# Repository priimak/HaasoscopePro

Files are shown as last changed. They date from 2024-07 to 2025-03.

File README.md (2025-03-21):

## HaasoscopePro

### An Affordable 2 GHz 3.2 GS/s 12 bit open-source open-hardware expandable USB oscilloscope

### [Available on CrowdSupply](https://www.crowdsupply.com/andy-haas/haasoscope-pro)

### [Hackaday.io Page](https://hackaday.io/project/200773-haasoscope-pro)

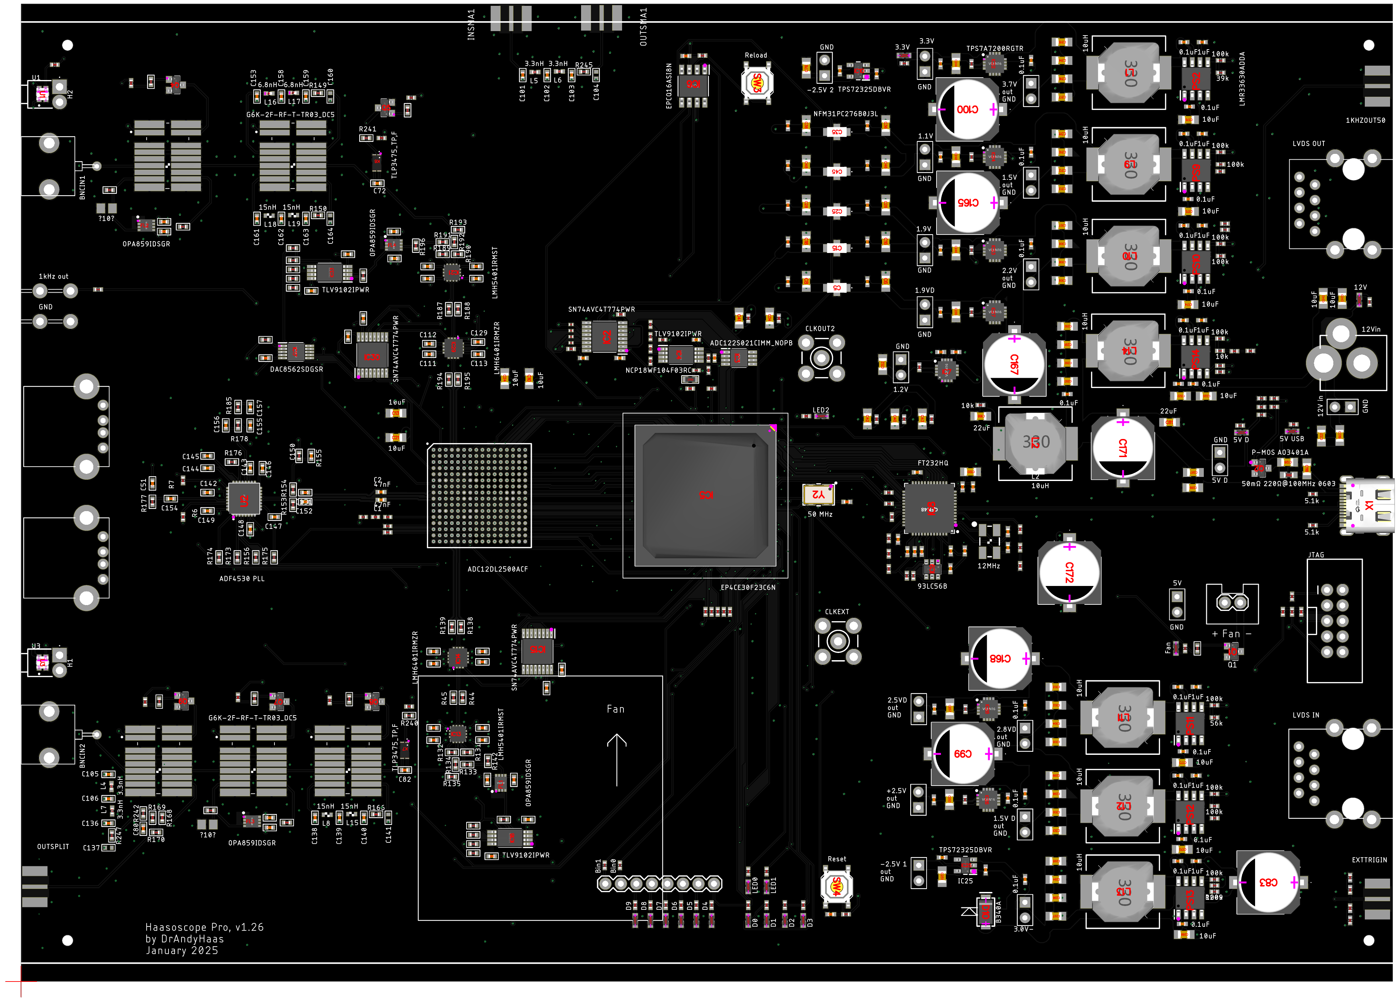
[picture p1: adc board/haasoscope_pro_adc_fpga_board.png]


#### Schematics in PDF: [haasoscope_pro_adc_fpga_board_schematics.pdf](adc%20board%2Fhaasoscope_pro_adc_fpga_board_schematics.pdf)

#### Routing image: [haasoscope_pro_adc_fpga_board_routing.png](adc%20board%2Fhaasoscope_pro_adc_fpga_board_routing.png)

#### Firmware overview: [firmware schematic.pdf](adc%20board%20firmware/schematic.pdf)

### Quick start (Windows/Mac/Linux)

1) Plug Haasoscope Pro into your computer via USB C
2) Download code and unzip it: https://github.com/drandyhaas/HaasoscopePro/archive/refs/heads/main.zip
3) Run **HaasoscopeProQt** in the <code>HaasoscopePro/software/dist/(OS)_HaasoscopeProQt</code> directory

### Tips

- If not enough power is supplied or issues happen during readout, plug in via a powered USB hub, a USB-A to C cable, or use an external 12V power adapter
- If the board is not found on Linux, use this udev rule and then plug it in: <code>sudo cp HaasoscopePro/software/ft245.rules /etc/udev/rules.d/</code>
- If you get an error like "qt.qpa.plugin: Could not load the Qt platform plugin "xcb" in "" even though it was found", try: <code>sudo apt install libxcb-xinerama0</code>

### Fuller way of running

1) Install python3 and git (operating system dependent)
2) Install dependencies: <br><code>pip3 install numpy scipy pyqtgraph PyQt5 pyftdi ftd2xx</code>
3) Get code: <br><code>git clone https://github.com/drandyhaas/HaasoscopePro.git</code>
4) Install [FTDI D2xx driver](https://ftdichip.com/drivers/d2xx-drivers/)
<br>for Windows: install using the [setup exe](https://ftdichip.com/wp-content/uploads/2021/08/CDM212364_Setup.zip)
<br>for Mac can just do: <code>sudo cp HaasoscopePro/software/libftd2xx.dylib /usr/local/lib/</code> 
<br>for Linux can just do: <code>sudo cp HaasoscopePro/software/libftd2xx.so /usr/lib/</code>
5) Run:
<br><code>cd HaasoscopePro/software</code>
<br><code>python3 HaasoscopeProQt.py</code>
6) To remake exe for quick start:
<br><code>pip3 install pyinstaller</code> # install dependency once
<br><code>python3 -m PyInstaller HaasoscopeProQt.py</code>
<br><code>mv dist/HaasoscopeProQt dist/(OS)_HaasoscopeProQt</code>

### Repository structure

- [adc board](adc%20board/): Design files and documentation for the main board, based on Eagle 9.6.2
- [adc board/Kicad](adc%20board/Kicad): An import of the main board design files into KiCad 8
- [adc board firmware](adc%20board%20firmware/): Quartus lite project for the Altera Cyclone IV FPGA firmware (see [README](adc%20board%20firmware/README.md) in there for firmware upload instructions)
- [case](case/): Front and back PCB panels for the aluminum case
- [software](software/): Python files for the oscilloscope program
- [sub boards](sub%20boards/): Eagle design files and documentation for smaller test boards that were used during development 

### 2 GHz Active Probe

All designs for the accompanying active probe are in a separate [repository](https://github.com/drandyhaas/oshw-active-probe)

### Editing the GUI

The Haasoscope Pro GUI can be edited using [Qt Designer](https://www.pythonguis.com/installation/install-qt-designer-standalone/), started with:
<br><code>pip install pyqt5-tools</code>
<br><code>pyqt5-tools designer</code>
<br>Then open software/HaasoscopePro.ui or HaasoscopeProFFT.ui etc.

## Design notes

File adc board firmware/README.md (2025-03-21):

# For compiling and uploading firmware

Install Quartus Prime Lite (free)
 - Tested on Windows, but Linux should work too
 - Tested with version 23.1, but newer should also be OK

Open the **adc_board_firmware/coincidence.qpf** project file in this directory with Quartus Prime Lite
 - File... Open Project

If you've made changes to the code, recompile
 - Processing... Start Compilation (or the "play" button in the menu bar)

To upload firmware to board:
 - Attach power to board
 - Attach USB Blaster to board via JTAG (to set up the usb blaster see tips below)
 - Tools... Programmer
   - Hardware Setup... select USB blaster by double clicking, then close
   - (If you need permanent writing to the board flash, and have recompiled, remake the jic file by doing File... Convert Programming Files, then Open Conversion Setup Data..., select **adc_board_firmware/coincidence.cof**, then Generate button at bottom)
   - Add File... **adc_board_firmware/output_files/coincidence.sof** (for temporary testing) or **adc_board_firmware/output_files/coincidence.jic** (for permanent writing to the board flash memory)
   - Select checkbox Program/Configure
   - Start

To setup USB Blaster on Windows:
 - After plugging in the USB Blaster, it may appear as an unrecognized device in the device manager. If so, you need to install a driver for it. Drivers come with the Quartus installation (even the "programmer only" version). Follow these instructions to install the driver:<br>
Plug in the USB blaster device, go to it in the device manager, and do Update driver, then Browse my computer for drivers, Let me pick from a list of devices, select JTAG cables, Have disk, and select the intelFPGA_lite\<version>\quartus\drivers\usb-blaster-ii directory, and install.

To setup USB Blaster on Linux:
 - In theory it should work out of the box, but you just need permissions to access it. Try this and then plug it in: <code>sudo cp HaasoscopePro/software/blaster.rules /etc/udev/rules.d/</code>

Tips in case of problems:
 - Maybe the USB-blaster must first be powered from the board and then connected to the PC. So the procedure step by step: connect the USB-Blaster to your board, power-on the board, plug the USB cable in the PC.

Screenshots for temporary (sof) or permanent flash (jic) programming:





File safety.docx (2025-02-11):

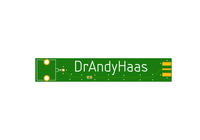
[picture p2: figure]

Regulatory Compliance and Safety Information

Haasoscope Pro and Haasoscope Pro-be

IMPORTANT: PLEASE RETAIN THIS INFORMATION FOR FUTURE REFERENCE

Getting Started

For full set up and installation instructions please visit: github.com/drandyhaas/HaasoscopePro

Wanings

- This product shall only be connected to an external power supply rated at 5V DC for the USB-C connection and a minimum current of 2A, and/or 12V DC for the barrel jack connection and a minimum current of 1A. Any external power supply used with the Haasoscope PRo shall comply with relevant regulations and standards applicable in the country of intended use.
- This product should be operated in a well ventilated environment and the case should not be covered.
- This product should be placed on a stable, flat, non-conductive surface in use and should not be contacted by conductive items.
- The connection of unapproved devices to the connectors may affect compliance or result in damage to the unit.
- All peripherals used with the unit should comply with relevant standards for the country of use and be marked accordingly to ensure that safety and performance requirements are met. These articles include but are not limited to probes, cables, and adapters.
- Where peripherals are connected that do not include the cable or connector, the cable or connector used must offer adequate insulation and operation in order that the requirements of the relevant performance and safety requirements are met.

Institutions for safe use

To avoid malfunction or damage to your Haasoscope Pro please observe the following:

- Do not expose it to water, moisture or place it on a conductive surface whilst in operation.
- Do not expose it to heat from any source; the Haasoscope Pro is designed for reliable operation at normal ambient room temperatures.
- Take care whilst handling to avoid mechanical or electrical damage to the printed circuit board and connectors.
- Avoid handling the printed circuit board while it is powered. Only handle it by the edges to minimise the risk of electrostatic discharge damage.

Compliance information

The Haasoscope Pro complies with the relevant provisions of the RoHS Directive for the European Union. In

common with all Electrical and Electronic Equipment (EEE) the Haasoscope Pro should not be disposed of as

household waste. Alternative arrangements may apply in other jurisdictions.

Electromagnetic compatibility and operation:

- This product is in conformity with the protection requirements of EU Council Directive 2004/108/EC on the approximation of the laws of the Member States relating to electromagnetic compatibility.
- This product has been tested and found to comply with the limits for Class B Information Technology Equipment according to the European Standard.
- NOTE: This equipment has been tested and found to comply with the limits for a Class B digital device, pursuant to part 15 of the FCC Rules. These limits are designed to provide reasonable protection against harmful interference in a residential installation. This equipment generates, uses and can radiate radio frequency energy and, if not installed and used in accordance with the instructions, may cause harmful interference to radio communications. However, there is no guarantee that interference will not occur in a particular installation. If this equipment does cause harmful interference to radio or television reception, which can be determined by turning the equipment off and on, the user is encouraged to try to correct the interference by one or more of the following measures:

❍ Reorient or relocate the receiving antenna

❍ Increase the separation between the equipment and receiver

❍ Connect the equipment into an outlet on a circuit different from that to which the receiver is connected

❍ Consult the dealer or an experienced radio/TV technician for help

- This Class B digital apparatus complies with CAN ICES-3 (B). Cet appareil numérique de la classe B est conforme à la norme NMB-3 (B) du Canada.
- WARNING: Please do not alter or modify the design of this product, doing so may void your ability to use the product freely, this includes altering the frequency at which the product operates.

DrAndyHaas Electronics

215 Lane Gate Rd

Cold Spring, NY 10516

USA

DrAndyHaas.com

Informationen zur Einhaltung gesetzlicher Vorschriften und zur Sicherheit

Haasoskop Pro und Haasoskop Pro-be

WICHTIG: BITTE BEWAHREN SIE DIESE INFORMATIONEN ZUM SPÄTEREN NACHSCHLAGEN AUF

Erste Schritte

Die vollständigen Einrichtungs- und Installationsanweisungen finden Sie unter: github.com/drandyhaas/HaasoscopePro

Abnehmen

- Dieses Produkt darf nur an eine externe Stromversorgung mit 5 V DC für den USB-C-Anschluss und einem Mindeststrom von 2 A und/oder 12 V DC für den Hohlsteckeranschluss und einem Mindeststrom von 1 A angeschlossen werden. Alle mit dem Haasoscope PRo verwendeten externen Netzteile müssen den einschlägigen Vorschriften und Normen entsprechen, die im Land der beabsichtigten Verwendung gelten.
- Dieses Produkt sollte in einer gut belüfteten Umgebung betrieben werden und das Gehäuse sollte nicht abgedeckt werden.
- Dieses Produkt sollte während des Gebrauchs auf einer stabilen, flachen, nicht leitenden Oberfläche platziert werden und nicht mit leitenden Gegenständen in Berührung kommen.
- Der Anschluss nicht zugelassener Geräte an die Anschlüsse kann die Konformität beeinträchtigen oder zu Schäden am Gerät führen.
- Alle mit dem Gerät verwendeten Peripheriegeräte sollten den relevanten Standards des jeweiligen Landes entsprechen und entsprechend gekennzeichnet sein, um sicherzustellen, dass die Sicherheits- und Leistungsanforderungen erfüllt werden. Zu diesen Artikeln gehören unter anderem Sonden, Kabel und Adapter.
- Wenn Peripheriegeräte angeschlossen werden, die kein Kabel oder Stecker enthalten, muss das verwendete Kabel oder der Stecker eine ausreichende Isolierung und Funktion bieten, damit die Anforderungen der relevanten Leistungs- und Sicherheitsanforderungen erfüllt werden.

Institutionen zur sicheren Nutzung

Um Fehlfunktionen oder Schäden an Ihrem Haasoscope Pro zu vermeiden, beachten Sie bitte Folgendes:

- Setzen Sie es während des Betriebs weder Wasser noch Feuchtigkeit aus und stellen Sie es nicht auf eine leitfähige Oberfläche.
- Setzen Sie es keiner Hitzequelle aus; Das Haasoscope Pro ist für einen zuverlässigen Betrieb bei normalen Raumtemperaturen ausgelegt.
- Seien Sie bei der Handhabung vorsichtig, um mechanische oder elektrische Schäden an der Leiterplatte und den Anschlüssen zu vermeiden.
- Vermeiden Sie den Umgang mit der Leiterplatte, während sie mit Strom versorgt wird. Fassen Sie es nur an den Kanten an, um das Risiko einer Beschädigung durch elektrostatische Entladung zu minimieren.

Compliance-Informationen

Das Haasoscope Pro entspricht den einschlägigen Bestimmungen der RoHS-Richtlinie für die Europäische Union. In

Wie bei allen elektrischen und elektronischen Geräten (EEE) sollte der Haasoscope Pro nicht entsorgt werden

Hausmüll. In anderen Gerichtsbarkeiten können alternative Regelungen gelten.

Elektromagnetische Verträglichkeit und Betrieb:

- Dieses Produkt entspricht den Schutzanforderungen der Richtlinie 2004/108/EG des EU-Rats zur Angleichung der Rechtsvorschriften der Mitgliedstaaten zur elektromagnetischen Verträglichkeit.
- Dieses Produkt wurde getestet und entspricht den Grenzwerten für Informationstechnologiegeräte der Klasse B gemäß der europäischen Norm.
- HINWEIS: Dieses Gerät wurde getestet und entspricht den Grenzwerten für ein digitales Gerät der Klasse B gemäß Teil 15 der FCC-Bestimmungen. Diese Grenzwerte sollen einen angemessenen Schutz vor schädlichen Störungen in einer Wohnanlage bieten. Dieses Gerät erzeugt und verwendet Hochfrequenzenergie und kann diese ausstrahlen. Wenn es nicht gemäß den Anweisungen installiert und verwendet wird, kann es schädliche Störungen der Funkkommunikation verursachen. Es gibt jedoch keine Garantie dafür, dass bei einer bestimmten Installation keine Störungen auftreten. Wenn dieses Gerät schädliche Störungen beim Radio- oder Fernsehempfang verursacht, was durch Aus- und Einschalten des Geräts festgestellt werden kann, wird dem Benutzer empfohlen, zu versuchen, die Störung durch eine oder mehrere der folgenden Maßnahmen zu beheben:

❍ Richten Sie die Empfangsantenne neu aus oder verschieben Sie sie

❍ Erhöhen Sie den Abstand zwischen Gerät und Empfänger

❍ Schließen Sie das Gerät an eine Steckdose an, die zu einem anderen Stromkreis gehört als der, an den der Empfänger angeschlossen ist

❍ Wenden Sie sich an den Händler oder einen erfahrenen Radio-/TV-Techniker

- Dieses digitale Gerät der Klasse B entspricht CAN ICES-3 (B). Dieses digitale Gerät der Klasse B entspricht der kanadischen Norm ICES-3 (B).
- WARNUNG: Bitte verändern oder modifizieren Sie das Design dieses Produkts nicht. Dies kann dazu führen, dass Sie das Produkt nicht mehr frei nutzen können, einschließlich der Änderung der Betriebsfrequenz des Produkts.

DrAndyHaas Electronics

215 Lane Gate Rd

Cold Spring, NY 10516

USA

DrAndyHaas.com

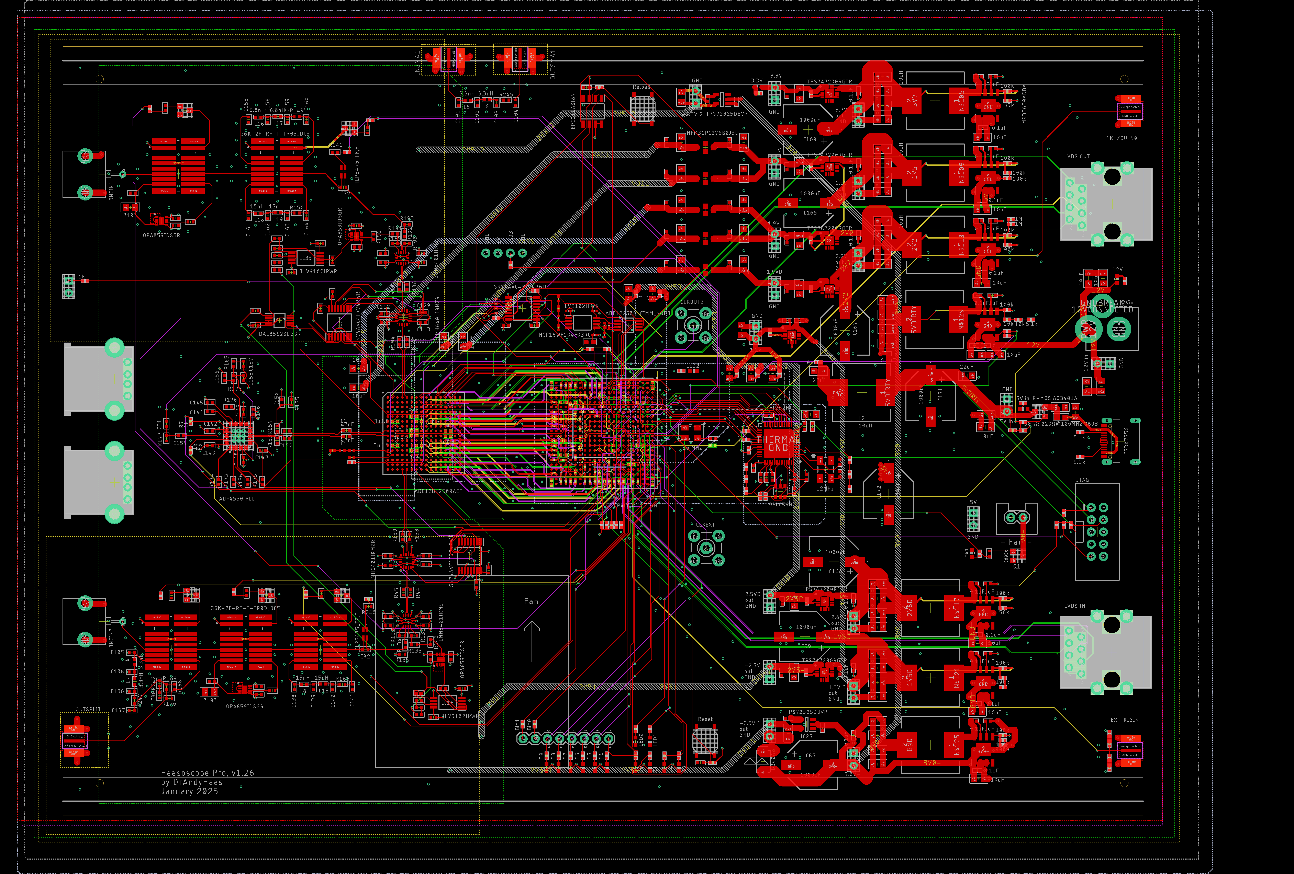
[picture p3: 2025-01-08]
adc board/haasoscope_pro_adc_fpga_board_routing.png

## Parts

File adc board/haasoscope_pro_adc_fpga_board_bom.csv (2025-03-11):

Comment | Designator | Footprint | LCSC Part #
0 | R15 R18 R81 R87 R88 R89 R90 | RES-0402
0 | R128 R129 | 0402_RES
0 | R142 R149 R150 R155 R166 R196 R247 | R0402
0.1uF | C3 C4 C7 C9 C17 C19 C27 C29 C37 C39 | RESC0402_N
0.1uF | C44 | 0402_CAP
0.1uF | C47 C49 | RESC0402_N
0.1uF | C50 | 0402_CAP
0.1uF | C51 | C0402
0.1uF | C53 C54 | RESC0402_N
0.1uF | C55 C56 | C0402
0.1uF | C58 C59 C60 C73 C74 | RESC0402_N
0.1uF | C75 | C0402
0.1uF | C77 | RESC0402_N
0.1uF | C78 C84 C85 C86 C87 C88 C89 C90 C91 C92 C93 C94 C95 C96 C97 C98 | C0402
0.1uF | C101 C102 | RESC0402_N
0.1uF | C107 C108 C109 C110 C111 C112 C113 | C0402
0.1uF | C114 C115 C116 C117 C119 C121 C122 C123 C124 C125 | RESC0402_N
0.1uF | C129 C130 C131 C132 C133 C134 C135 C142 C143 C144 C145 C146 C147 C148 C149 C150 C151 C152 C154 | C0402
0.1uF | C245 C247 C249 C250 C252 C254 C256 C258 C259 C260 C262 C263 C264 C266 C267 C268 C270 C271 C272 C274 C275 C276 C278 C279 C280 C282 C283 C284 C286 C318 | RESC0402_N | C307331
0.75pF | C136 | C0402 | C76914
1.0pF | C105 | C0402 | C72134
1.3pF | C106 | C0402 | C88880
1M | R42 R158 | R0402
1M | R204 R205 | RES-0402
1k | R6 R7 R8 R9 R10 R11 R12 R13 R14 R16 R22 R28 R29 R30 R32 R33 R34 R35 R36 R37 R40 R41 R46 R47 R48 R49 R51 R52 R53 R93 | RES-0402
1k | R122 R124 R126 | 0402_RES
1k | R140 R141 R143 R144 R145 R146 R147 | R0402
1k | R157 | RES-0402
1k | R162 R164 R171 R172 R178 | R0402
1k | R179 | RES-0402
1k | R180 R181 R197 R199 R200 R201 | R0402
1k | R202 R203 | 0402_RES
1k | R206 | RES-0402
1k | R208 | R0402
1k | R236 R237 R238 R243 R244 | RES-0402
1uF | C261 C265 C269 C273 C277 C281 C285 | RESC0402_N
2.4pF | C159 | C0402
2.7nF | C155 | C0402
3.0pF | C153 | C0402
3.3nH | L4 L7 | RESC0402_N | C162542
3.9pF | C158 | C0402
5.1k | R152 R165 | RES-0402
5.1k | R176 | R0402
5.1k | R182 R183 R217 R218 R235 | RES-0402
6.8nH | L16 L17 | RESC0402_N | C77110
6.8pF | C140 C163 | C0402
7.5pF | C138 C161 | C0402
10k | R5 R27 R38 R78 R79 R80 R82 R83 R84 R85 R86 R91 R92 R121 R123 | RES-0402
10k | R125 R127 R130 | 0402_RES
10k | R148 R151 | RES-0402
10k | R156 | R0402
10k | R161 R167 | RES-0402
10k | R173 R174 R175 | R0402
10k | R186 R198 | 0402_RES
10k | R212 R213 R214 R215 R216 R219 R220 R234 R239 R246 | RES-0402
10uF | C6 C8 C10 C13 C16 C18 C21 C24 C26 C28 C34 C36 C38 C40 C41 C42 C43 C46 C48 C52 C76 C118 C120 C126 C170 C173 C174 C175 C176 C242 C243 C244 C246 C248 C251 C253 C255 C257 C287 C288 C289 C319 C320 C321 C322 | RESC0805_N
10uH | L1 L2 L9 L10 L11 L12 L13 L14 | CDRH125 | C339970
11pF | C139 C162 | C0402
12MHz | Y3 | CRYSTAL-SMD-5X3 | C2901628
15nH | L8 L15 L18 L19 | RESC0402_N | C521066
16pF | C80 | C0402
16pF | C127 C128 | RESC0402_N
22.6 | R134 R192 | R0402
22uF | C81 C166 C290 C291 C292 C293 C294 C295 C296 C297 C298 C299 C300 C301 C302 C303 C304 C305 C306 C307 C308 C309 C310 C311 C312 C313 C314 C315 C316 C317 | RESC0805_N
39 | R44 R45 R138 R139 | R0402
39 | R184 | RES-0402
39 | R187 R188 R194 R195 | R0402
39k | R222 | RES-0402
47 | R31 | RES-0402
47 | R43 | R0402
47 | R136 | RES-0402
47 | R153 R154 R159 | R0402
47 | R160 | RES-0402
47 | R168 R169 R170 R177 | R0402
47 | R210 | RES-0402
47 | R242 | R0402
47nF | C1 C2 | RESC0402_N
47nF | C157 | C0402
50 | 1KHZOUT50 EXTTRIGIN OUTSPLIT | SMA_EDGELAUNCH
50mΩ 220Ω@100MHz 0603 | FB2 | 603 | C14709
56k | R228 | RES-0402
66.5 | R133 R191 | R0402
93LC56B | IC9 | SOT23-6 | C190271
100 | R1 R2 R3 R4 | R0201
100k | R137 R163 R209 R221 R223 R224 R225 R226 R227 R229 R230 R231 R232 R233 | RES-0402
120 | R240 R241 | R0402
127 | R131 R132 R189 R190 | R0402
220 | R135 R193 | R0402
357 | R50 | RES-0402
357 | R185 | R0402
680pF | C156 | C0402
1000uF | C83 C99 C100 C165 C167 C168 C171 C172 | EEE0JA152UAP | C401766
?0? | C137 C141 C160 C164 | C0402
?10? | C57 C79 | C0805
ADC12DL2500ACF | IC1 | BGA256C100P16X16_1700X1700X331
ADC122S021CIMM_NOPB | IC3 | SOP65P490X110-8N
ADF4350BCPZ | U2 | QFN50P500X500X100-33V2N | C98705
B340A | D10 | SMA-DIODE | C64982
DAC8562SDGSR | IC17 | SOP50P490X110-10N
EP4CE30F23C6N | IC5 | BGA484C100P22X22_2300X2300X240
EPCQ16ASI8N | IC6 | SOIC127P600X175-8N
FDN340P | Q2 | SOT-23 | C15127
FT232HQ | IC8 | QFN48_8MM
G6K-2F-RF-T-TR03_DC5 | K1 K2 K3 K4 K5 | G6K2FRFTTR03DC5
LMH5401IRMST | IC13 IC21 | LMH5401IRMSR
LMH6401IRMZR | IC14 IC29 | LMH6401IRMZR
LMR33630ADDA | PS2 PS9 PS10 PS11 PS12 PS13 PS14 | SOIC127P600X170-9N | C841384
NCP18WF104F03RC | R207 | R0603 | C13564
NFM31PC276B0J3L | C5 C15 C25 C35 C45 | NFM31HK103R1H3L
OPA859IDSGR | FL1 FL2 FL3 FL4 | SON50P200X200X80-9N
OSCILLATORSMD-5X3 | Y2 | OSCILLATOR-SMD-5X3.2 | C2901546
RF_1uF | C72 C82 | C0402 | C52923
S8050 | Q1 Q4 Q5 Q7 Q8 Q9 | SOT-23 | C7420370
SKQGADE010 | SW3 SW4 | SW4-SMD-5.2X5.2X1.5MM
SN74AVC4T774PWR | IC2 IC15 IC30 | SOP65P640X120-16N
TLP3475_TP F | K6 | TLP3475TPF | C2152213
TLP3475_TP F | K7 | TLP3475TPF | C2152213
TLV9102IPWR | IC4 IC18 IC33 | SOP65P640X120-8N
TPS7A7200RGTR | IC7 IC22 IC23 IC24 IC26 IC27 IC28 | QFN50P300X300X100-17N
TPS72325DBVR | IC10 IC25 | SOT95P280X145-5N
USBC | X1 | USB_C_CUSB31-CFM2AX-01-X | C5307756
WS2812-2020 | U1 U3 | LED_WS2812-2020
red | LED1 LED2 LED3 LED4 LED25 LED26 LED27 LED28 LED29 LED30 LED32 LED41 LED42 LED43 LED45 LED46 LED47 LED48 | CHIP-LED0603
0.1uF | C12 C20 C23 C31 C33 C61 C62 C63 C64 C65 C66 C67 C68 C69 C70 C71 | RESC0402_N
1uF | C11 C14 C22 C30 C32 | RESC0402_N
47 | R211 | RES-0402
50 | 1KHZOUT50 EXTTRIGIN OUTSPLIT | SMA_EDGELAUNCH
100 | R17 R19 R20 R21 R23 R24 R25 R26 R39 R54 R55 R56 R57 R58 R59 R60 R61 R62 R63 R64 R65 R66 R67 R68 R69 R70 R71 R72 R73 R74 R75 R76 R77 R94 R95 R96 R97 R98 R99 R100 R101 R102 R103 R104 R105 R106 R107 R108 R109 R110 R111 R112 R113 R114 R115 R116 R117 R118 R119 R120 | R0201

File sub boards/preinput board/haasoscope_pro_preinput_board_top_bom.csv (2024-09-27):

Comment | Designator | Footprint | LCSC Part #
0 | R14 | R0402
0.1uF | C11 C12 | C0402
1M | R1 | R0805
1k | R3 R4 R6 R7 R12 R13 | R0402
1uF | C2 C3 | C0402
47 | R2 | R0805
47 | R8 R9 R10 | R0402
75 | R15 R16 | R0402
120 | R11 | R0402
?10pF? | C1 | C0805
?50? | R5 | R0805
AQY21SOP | K1 | SOP04 | C7435105
G6K-2F-RF-DC3 | K2 K3 K4 | G6K2FRFDC3 | C397195
OPA859IDSGR | FL1 | SON50P200X200X80-9N
S8050 | Q1 Q2 Q3 | SOT-23 | C7420370
green | D1 D2 | LED0603 | C2286
out50 | OUTMAIN OUTSPLIT TESTSMA1 TESTSMA2 TESTSMA3 TESTSMA4 | SMA_EDGELAUNCH

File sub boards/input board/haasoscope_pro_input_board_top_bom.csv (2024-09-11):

Comment | Designator | Footprint | LCSC Part #
0 | R8 R9 R14 R15 R21 R22 | R0402
0.1uF | C1 C2 C3 C4 C5 C6 C7 C8 C9 C10 C11 C12 C13 C14 C15 | C0402
1k | R12 R13 R16 R18 R19 R20 | R0402
2k | R17 | R0402
22.6 | R6 | R0402
39 | R2 R3 R10 R11 | R0402
66.5 | R5 | R0402
127 | R1 R4 | R0402
357 | R7 | R0402
DAC8562SDGSR | IC6 | SOP50P490X110-10N
LMH5401IRMST | IC1 | LMH5401IRMSR
LMH6401IRMZR | IC2 | LMH6401IRMZR
OPA693ID | IC4 | SOIC127P600X175-8N
SN74AVC4T774PWR | IC3 | SOP65P640X120-16N
TLV9102IPWR | IC7 | SOP65P640X120-8N
green | D1 D2 | LED0603
out+ | AMPOUT+ | SMA_EDGELAUNCH
out- | AMPOUT- | SMA_EDGELAUNCH

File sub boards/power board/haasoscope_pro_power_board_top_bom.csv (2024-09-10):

Comment | Designator | Footprint | LCSC Part #
0.1uF | C1 C2 C5 C9 C12 C15 C16 C20 C22 C23 C24 C27 C29 C31 C32 C35 C39 C40 C43 | RESC0402_N
0.01uF | C4 C7 C13 C17 C25 C33 C41 | RESC0402_N
2k | R16 | RES-0402
3.3k | R1 R3 R8 R11 R12 R14 R18 | RES-0402
10k | R2 R4 R6 R7 R13 R15 R19 R21 | RES-0402
10uF | C3 C10 C11 C14 C19 C21 C28 C30 C38 | RESC0805_N
10uH | L1 L2 L4 L6 L8 L10 | CDRH125 | C339970
20k | R5 R9 R10 R17 R20 R22 R24 | RES-0402
100uF | C6 C8 C18 C26 C34 C42 | VISHAY_C | C7230
B340A | D1 D2 D4 D6 D8 D10 | SMA-DIODE | C64982
TPS7A7200RGTR | IC3 IC7 IC9 IC11 IC12 IC14 | QFN50P300X300X100-17N
TPS5430DDAR | IC1 IC2 IC4 IC6 IC8 IC10 | SOIC127P600X170-9N
TPS72325DBVR | IC5 | SOT95P280X145-5N
green | D3 D5 | LED0805

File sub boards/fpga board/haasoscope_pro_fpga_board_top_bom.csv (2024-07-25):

Comment | Designator | Footprint | LCSC Part #
0 | R4 R17 R18 R19 R20 | RES-0402
0.1uF | C1 C3 C5 C7 C9 C11 C13 C14 C15 | RESC0402_N
1k | R38 R39 R40 R41 R42 R43 R44 R45 | RES-0402
10k | R1 R2 R3 R5 R6 R7 R8 R9 | RES-0402
10uF | C2 C4 C6 C8 C10 C12 | RESC0805_N
AMS1117-1.2 | U3 | SOT-223-3
AMS1117-2.5 | U2 | SOT-223-3
AMS1117-3.3 | U1 | SOT-223-3
EP4CE30F23C6N | IC1 | BGA484C100P22X22_2300X2300X240
EPCQ16ASI8N | IC2 | SOIC127P600X175-8N
OSCILLATORSMD-5X3 | Y1 | OSCILLATOR-SMD-5X3.2 | C2901546
SKQGADE010 | SW1 SW2 | SW4-SMD-5.2X5.2X1.5MM
red | LED33 LED34 LED35 LED36 LED37 LED38 LED39 LED40 | CHIP-LED0603

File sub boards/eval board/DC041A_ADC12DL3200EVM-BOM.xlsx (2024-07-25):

 |  | Bill of Materials
 |  | ADC12DL3200EVM DC041A |  |  | 2018-05-11
Item | Qty | Part Reference | Value | PCB Footprint | MFR | MFR PN | Assembly Option
1 | 2 | BALUN1 BALUN2 | BROADBAND BALUN | BAL-0009SMG | Marki Microwave | BAL-0009SMG | LOAD
2 | 32 | C1 C8 C9 C10 C15 C18 C20 C23 C48 C49 C59 C87 C90 C144 C145 C146 C147 C148 C149 C150 C151 C172 C175 C176 C184 C186 C205 C206 C217 C218 C223 C224 | 1uF | CAPC0402X013N | TDK Corporation | CGB2A1X5R1E105K033BC | LOAD
3 | 77 | C2 C6 C11 C13 C16 C17 C54 C55 C60 C61 C63 C67 C68 C70 C73 C76 C77 C86 C91 C92 C93 C94 C95 C96 C97 C98 C99 C100 C101 C102 C103 C104 C105 C106 C107 C108 C109 C110 C111 C112 C113 C116 C117 C118 C119 C120 C121 C122 C123 C126 C127 C128 C129 C130 C131 C132 C133 C134 C135 C136 C137 C138 C139 C140 C141 C142 C143 C156 C157 C158 C159 C160 C163 C165 C168 C169 C170 | 0.1uF | CAPC0201X013N | MURATA | GRM033R61C104KE84D | LOAD
4 | 25 | C3 C4 C5 C62 C72 C161 C166 C167 C174 C178 C179 C185 C187 C191 C194 C196 C197 C201 C202 C207 C214 C219 C222 C227 C228 | 10uF | CAPC0603X035N | TDK Corporation | C1608X5R1A106K080AC | LOAD
5 | 4 | C7 C71 C78 C79 | 100pF | CAPC0201X013N | MURATA | GRM033R71E101KA01D | LOAD
6 | 22 | C12 C19 C21 C22 C26 C27 C42 C45 C47 C69 C83 C153 C171 C180 C188 C189 C190 C211 C212 C213 C215 C216 | 0.1uF | CAPC0402X021N | TDK Corporation | CGA2B3X7R1E104K050BB | LOAD
7 | 2 | C14 C89 | 10000pF | CAPC0402X022N | Kemet | C0402C103J3RACTU | LOAD
8 | 0 | C24 C25 C115 C125 | 4700pF | CAPC0402X023N | Vishay | VJ0402Y472KXBAC | DNL
9 | 5 | C28 C29 C30 C31 C152 | 10uF | CAPMP1411X082N | Vishay | 293D106X9010B2TE3 | LOAD
10 | 7 | C32 C33 C36 C44 C46 C162 C173 | 0.1uF | CAPC0603X034N | Kemet | C0603C104M3RACTU | LOAD
11 | 4 | C34 C35 C84 C155 | 100pF | CAPC0402X022N | AVX | 04025A101JAT2A | LOAD
12 | 2 | C37 C164 | 100uF | CAPC1206X071N | KEMET | C1206C107M9PACTU | LOAD
13 | 2 | C38 C41 | 18pF | CAPC0402X022N | AVX | 04025A180JAT2A | LOAD
14 | 4 | C39 C40 C43 C154 | 1uF | CAPC0603X035N | SAMSUNG | CL10B105KA8NNNC | LOAD
15 | 1 | C50 | 560pF | CAPC0201X013N | MURATA | GRM033R71E561KA01D | LOAD
16 | 0 | C51 | 6800pF | CAPC0201X013N | AVX | 0201ZD682KAT2A | DNL
17 | 1 | C52 | 6800pF | CAPC0201X013N | AVX | 0201ZD682KAT2A | LOAD
18 | 1 | C53 | 0.047uF | CAPC0201X013N | MURATA | GRM033R60J473KE19D | LOAD
19 | 0 | C56 C57 C66 C74 C75 | 0.1uF | CAPC0201X013N | MURATA | GRM033R61C104KE84D | DNL
20 | 1 | C58 | 0.68uF | CAPC0402X022N | TDK Corporation | C1005X7S0J684K050BC | LOAD
21 | 5 | C64 C65 C181 C182 C183 | 0.01uF | CAPC0201X013N | MURATA | GRM033R71A103KA01D | LOAD
22 | 1 | C80 | 12pF | CAPC0201X013N | TDK Corporation | CGA1A2C0G1E120J030BA | LOAD
23 | 1 | C81 | 47pF | CAPC0201X013N | MURATA | GRM0335C1E470JA01D | LOAD
24 | 1 | C82 | 3900pF | CAPC0201X013N | AVX Corporation | 0201ZD392KAT2A | LOAD
25 | 1 | C85 | 10pF | CAPC0402X022N | AVX | 04025A100JAT2A | LOAD
26 | 1 | C88 | 2200pF | CAPC0402X022N | MURATA | GRM155R61E222KA01D | LOAD
27 | 2 | C114 C124 | 4700pF | CAPC0402X023N | Vishay | VJ0402Y472KXAAC | LOAD
28 | 8 | C177 C192 C193 C195 C198 C199 C203 C204 | 33uF | CAPC0805X057 | TDK Corporation | C2012X5R1A336M125AC | LOAD
29 | 3 | C200 C221 C225 | 22uF | CAPC1206X071N | AVX | 12063D226MAT2A | LOAD
30 | 1 | C208 | 47uF | CAPC1411X083N | AVX Corporation | TPSB476K010R0250 | LOAD
31 | 3 | C209 C210 C226 | 47uF | CAPC1206X071N | MURATA | GRM31CR61A476ME15L | LOAD
32 | 1 | C220 | 2.2uF | CAPC0603X039N | AVX Corporation | TPCL225K016R5000 | LOAD
33 | 0 | C229 C230 | 0.01uF | CAPC0603X035N | MURATA | GRM033R71A103KA01D | DNL
34 | 2 | C231 C232 | 10uF | CAPC0805X053N | MURATA | GRM21BR61E106KA73L | LOAD
35 | 5 | D1 D2 D5 D6 D13 | LED GREEN | LEDC0805X110N | Lite-On Inc. | LTST-C170KGKT | LOAD
36 | 1 | D7 | LED RED | LEDC0805X110N | Lite-On Inc. | LTST-C170KRKT | LOAD
37 | 2 | D8 D11 | LED ORANGE | LEDC0603X080N | Lite-On Inc. | LTST-C190KFKT | LOAD
38 | 2 | D9 D10 | 1N4148W | 1N4148W_SOD123 | Diodes Incorporated | 1N4148W-7-F | LOAD
39 | 1 | D12 | MBRB2515L | MBRB2515L_D2PAK | ON Semiconductor | MBRB2515LT4G | LOAD
40 | 0 | F1 | 1206SFF200F/63-2 | 1206SFF200F_FUSE_SMD | Littelfuse Inc. | 1206SFF200F/63-2 | DNL
41 | 10 | FB1 FB2 FB3 FB4 FB5 FB6 FB7 FB8 FB11 FB12 | 120Ohm@100MHz | INDC0603X037N | MURATA | BLM18AG121SN1D | LOAD
42 | 1 | FB9 | 26Ohm@100MHz | INDC0603X037N | MURATA | BLM18SG260TN1D | LOAD
43 | 3 | FB10 FB13 FB14 | 120Ohm@100MHz | INDC0603X037N | MURATA | BLM18SG121TN1D | LOAD
44 | 5 | FB15 FB16 FB17 FB18 FB19 | 27uF | IND_NFM31PC | MURATA | NFM31PC276B0J3L | LOAD
45 | 5 | FB20 FB21 FB22 FB23 FB24 | 120Ohm@100MHz | INDC1206X051N | MURATA | BLM31PG121SN1L | LOAD
46 | 4 | J1 J2 J7 J8 | 142-0701-201 | SMA_142-0701-201 | Cinch Connectivity Solutions Johnson | 142-0701-201 | LOAD
47 | 1 | J13 | SEAM-40-02.0-S-10-2-A-K-TR | SEAM_400POS_SMD | Samtec Inc. | SEAM-40-02.0-S-10-2-A-K-TR | LOAD
48 | 6 | J3 J9 J10 J15 J16 J18 | SF2921-61345-1S | SMA_SMT_SF2921 | Amphenol SV Microwave | SF2921-61345-1S | LOAD
49 | 1 | J4 | 0853050232 | 85305_SMP | Molex, LLC | 0853050232 | LOAD
50 | 4 | J5 J14 J20 JP1 | HTSW-102-07-G-S | HTSW-102_1X2_100M_TH | Samtec Inc. | HTSW-102-07-G-S | LOAD
51 | 3 | J6 J11 J12 | 142-0701-801 | SMA_142-0701-801 | Cinch Connectivity Solutions Johnson | 142-0701-801 | LOAD
52 | 0 | J17 | HTSW-102-07-G-S | HTSW-102_1X2_100M_TH | Samtec Inc. | HTSW-102-07-G-S | DNL
53 | 1 | J19 | 651305142821 | USB_MINI_AB_651305142821 | Wurth Electronics Inc. | 651305142821 | LOAD
54 | 1 | J21 | RAPC722X | RAPC722X_PWR_CONN | Switchcraft Inc. | RAPC722X | LOAD
55 | 2 | JP2 JP3 | HTSW-102-07-G-S | HTSW-102_1X2_100M_TH | Samtec Inc. | HTSW-102-07-G-S | LOAD SHUNT 1&2
55B | 1 | JP4 | HTSW-102-03-G-S | HTSW-103_1X3_100M_TH | Samtec Inc. | HTSW-103-07-G-S | LOAD SHUNT 1&2
56 | 4 | MT1 MT2 MT3 MT4 | 3480 | 3480 | Keystone | 3480 | LOAD
57 | 1 | PCB1 | BARE BOARD, ADC12DL3200 |  | ANY VENDOR | DC041A ADC12DL3200EVM
58 | 1 | Q1 | MMBT3904 | SOT23_MMBT3904 | Fairchild/ON Semiconductor | MMBT3904 | LOAD
59 | 1 | Q2 | N-MOSFET | CSD18532Q5B_8VSON | Texas Instruments | CSD18532Q5B | LOAD
60 | 2 | R1 R4 | 750Ohm | RESC0603X021N | PANASONIC | ERJ-3EKF7500V | LOAD
61 | 17 | R5 R6 R31 R35 R55 R56 R59 R60 R61 R62 R74 R101 R149 R150 R152 R153 R157 | 0 | RESC0402X016N | PANASONIC | ERJ-2GE0R00X | LOAD
62 | 15 | R7 R8 R13 R14 R16 R17 R22 R23 R64 R83 R85 R88 R116 R117 R154 | 0 | RESC0201X011N | Vishay Dale | CRCW02010000Z0ED | LOAD
63 | 0 | R9 R10 R11 R12 R18 R19 R20 R21 R151 R155 | 0 | RESC0201X011N | Vishay Dale | CRCW02010000Z0ED | DNL
64 | 16 | R15 R41 R45 R47 R48 R82 R92 R123 R128 R129 R131 R132 R134 R135 R136 R137 | 100 | RESC0402X016N | PANASONIC | ERJ-2RKF1000X | LOAD
65 | 12 | R24 R26 R29 R32 R33 R34 R39 R43 R110 R115 R122 R138 | 10k | RESC0402X016N | PANASONIC | ERJ-2RKF1002X | LOAD
66 | 1 | R25 | 270 | RESC0402X016N | PANASONIC | ERJ-2RKF2700X | LOAD
67 | 1 | R27 | 2.2k | RESC0603X022N | PANASONIC | ERJ-3GEYJ222V | LOAD
68 | 2 | R28 R30 | 1.3k | RESC0402X016N | PANASONIC | ERJ-2RKF1301X | LOAD
69 | 1 | R36 | 750 | RESC0402X016N | PANASONIC | ERJ-2RKF7500X | LOAD
70 | 1 | R37 | 0 | RESC0603X021N | PANASONIC | ERJ-3GEY0R00V | LOAD
71 | 0 | R38 | 100 | RESC0402X016N | PANASONIC | ERJ-2RKF1000X | DNL
72 | 2 | R40 R44 | 10 | RESC0603X021N | PANASONIC | ERJ-3EKF10R0V | LOAD
73 | 2 | R42 R51 | 1.2k | RESC0402X016N | PANASONIC | ERJ-2RKF1201X | LOAD
74 | 2 | R46 R49 | 1M | RESC0402X016N | PANASONIC | ERJ-2RKF1004X | LOAD
75 | 1 | R50 | 8.06k | RESC0402X016N | PANASONIC | ERJ-2RKF8061X | LOAD
76 | 1 | R52 | 1.33k | RESC0402X016N | PANASONIC | ERJ-2RKF1331X | LOAD
77 | 0 | R53 R54 R164 R166 R168 R169 | 0 | RESC1206X023N | PANASONIC | ERJ-8GEY0R00V | DNL
78 | 0 | R57 R58 R102 R143 R144 R147 R148 R156 | 0 | RESC0402X016N | PANASONIC | ERJ-2GE0R00X | DNL
79 | 1 | R63 | 150 | RESC0201X010N | PANASONIC | ERJ-1GEJ151C | LOAD
80 | 1 | R65 | 12 | RESC0201X010N | PANASONIC | ERJ-1GEF12R0C | LOAD
81 | 1 | R66 | 680 | RESC0201X010N | PANASONIC | ERJ-1GEF6800C | LOAD
82 | 1 | R67 | 12k | RESC0402X016N | PANASONIC | ERJ-2RKF1202X | LOAD
83 | 1 | R68 | 39k | RESC0201X010N | PANASONIC | ERJ-1GEF3902C | LOAD
84 | 6 | R69 R70 R91 R93 R113 R114 | 240 | RESC0201X010N | PANASONIC | ERJ-1GEF2400C | LOAD
85 | 4 | R71 R75 R80 R86 | 120 | RESC0201X010N | PANASONIC | ERJ-1GEF1200C | LOAD
86 | 1 | R72 | 294 | RESC0402X016N | PANASONIC | ERJ-2RKF2940X | LOAD
87 | 0 | R73 | 294 | RESC0402X016N | PANASONIC | ERJ-2RKF2940X | DNL
88 | 0 | R76 | 18 | RESC0402X016N | PANASONIC | ERJ-2RKF18R0X | DNL
89 | 0 | R77 | 0 | RESC0603X021N | PANASONIC | ERJ-3GEY0R00V | DNL
90 | 4 | R78 R84 R97 R98 | 49.9 | RESC0402X016N | PANASONIC | RC0402FR-0749R9L | LOAD
91 | 0 | R79 R96 R107 R108 | 49.9 | RESC0201X33N | PANASONIC | ERJ-1GEF49R9C | DNL
92 | 0 | R81 R87 R99 | 100 | RESC0201X010N | PANASONIC | ERJ-1GEJ101C | DNL
93 | 1 | R89 | 51Ohm | RESC0201X010N | PANASONIC | ERJ-1GEJ510C | LOAD
94 | 0 | R90 | 680 | RESC0201X010N | PANASONIC | ERJ-1GEF6800C | DNL
95 | 0 | R94 R104 | 82 | RESC0201X010N | PANASONIC | ERJ-1GEF82R0C | DNL
96 | 0 | R95 R105 | 130 | RESC0201X010N | PANASONIC | ERJ-1GEF1300C | DNL
97 | 1 | R100 | 100 | RESC0201X010N | PANASONIC | ERJ-1GEJ101C | LOAD
98 | 1 | R103 | 2.32k | RESC0402X016N | PANASONIC | ERJ-2RKF2321X | LOAD
99 | 1 | R106 | 49.9 | RESC0201X33N | PANASONIC | ERJ-1GEF49R9C | LOAD
100 | 1 | R109 | 620 | RESC0201X010N | PANASONIC | ERJ-1GEF6200C | LOAD
101 | 0 | R111 R112 | 240 | RESC0201X010N | PANASONIC | ERJ-1GEF2400C | DNL
102 | 8 | R118 R120 R121 R124 R125 R126 R127 R142 | 1k | RESC0402X016N | PANASONIC | ERJ-2RKF1001X | LOAD
103 | 1 | R119 | 2.1k | RESC0402X016N | PANASONIC | ERJ-2RKF2101X | LOAD
104 | 1 | R130 | 12k | RESC0603X022N | PANASONIC | ERJ-3EKF1202V | LOAD
105 | 1 | R133 | 1k | RESC0603X021N | PANASONIC | ERJ-3EKF1001V | LOAD
106 | 2 | R139 R140 | 36.5k | RESC0402X016N | PANASONIC | ERJ-2RKF3652X | LOAD
107 | 2 | R141 R146 | 165k | RESC0402X016N | PANASONIC | ERJ-2RKF1653X | LOAD
108 | 1 | R145 | 61.9k | RESC0402X016N | PANASONIC | ERJ-2RKF6192X | LOAD
109 | 2 | R158 R161 | 162k | RESC0402X016N | Vishay Dale | CRCW0402162KFKED | LOAD
110 | 1 | R159 | 143k | RESC0402X016N | PANASONIC | ERJ-2RKF1433X | LOAD
111 | 1 | R160 | 287k | RESC0402X016N | PANASONIC | ERJ-2RKF2873X | LOAD
112 | 2 | R162 R163 | 499k | RESC0402X016N | PANASONIC | ERJ-2RKF4993X | LOAD
113 | 2 | R165 R167 | 0 | RESC1206X023N | PANASONIC | ERJ-8GEY0R00V | LOAD
114 | 1 | T1 | TC1-1-43X-2+ | TC1-1-43X | Mini-Circuits | TC1-1-43X-2+ | LOAD
115 | 1 | T2 | TC1-1-13M+ | TC1-1-13M | Mini-Circuits | TC1-1-13M+ | LOAD
116 | 6 | TP1 TP13 TP20 TP25 TP26 TP32 | 5001 Black | TP_KEYSTONE_5001 | Keystone | 5001 | LOAD
117 | 7 | TP2 TP3 TP4 TP10 TP11 TP12 TP35 | 5003 Orange | TP_KEYSTONE_5003 | Keystone | 5003 | LOAD
118 | 0 | TP5 TP6 TP7 TP9 TP15 TP17 TP19 TP21 TP22 TP23 TP24 TP28 TP29 TP30 TP31 TP33 | PROBE POINT | PROBE_POINT_30PAD | Harwin | P1113SS3 | DNL
119 | 1 | TP8 | 5116 Green | TP_5116 | Keystone | 5116 | LOAD
120 | 3 | TP14 TP16 TP27 | 5011 Black | TP_KEYSTONE_5011 | Keystone | 5011 | LOAD
121 | 1 | TP18 | 5010 Red | TP_KEYSTONE_5010 | Keystone | 5010 | LOAD
122 | 1 | TP34 | 5000 Red | TP_RED_5000 | Keystone | 5000 | LOAD
123 | 1 | U2 | 93LC46B-I/MS | 93LC46B_8MSOP | Microchip Technology | 93LC46B-I/MS | LOAD
124 | 1 | U3 | LM95233 | LM95233_14WDFN | Texas Instruments | LM95233CISD/NOPB | LOAD
125 | 0 | U4 | TLV70233DBVT | TLV70233_5SOT23 | Texas Instruments | TLV70233DBVT | DNL
126 | 1 | U5 | FT4232HL-REEL | FT4232H_64LQFP | FTDI | FT4232HL-REEL | LOAD
127 | 1 | U7 | TPS2400 | TPS2400_5SOT23 | Texas Instruments | TPS2400DBVT | LOAD
128 | 1 | U8 | LMX2582 | LMX2582_40VQFN | Texas Instruments | LMX2582RHAT | LOAD
129 | 2 | U10 U12 | SN74AVC4T774PWR | TSSOP16_SN74AVC4T774 | Texas Instruments | SN74AVC4T774PWR | LOAD
130 | 1 | U11 | SN74LVC1G125 | SN74LVC1G125_5SOT23 | Texas Instruments | SN74LVC1G125DBVR | LOAD
131 | 1 | U13 | TPS82084 | TPS82084_8uSIP | Texas Instruments | TPS82084SILR | LOAD
132 | 2 | U14 U15 | TPS7A7200 | TPS7A7200_20VQFN | Texas Instruments | TPS7A7200RGWR | LOAD
133 | 2 | U16 U17 | TPS7A4700 | TPS7A4700_20VQFN | Texas Instruments | TPS7A4700RGWT | LOAD
134 | 2 | U18 U19 | TPS82085SILT | USIP8_TPS82085 | Texas Instruments | TPS82085SILT | LOAD
135 | 1 | U1 | ADC12DL3200 | ADC12DL3200_BGA_256_39 | Texas Instruments | ADC12DL3200ACF | LOAD
136 | 1 | U6 | LMC6762 | LMC6762_8SOIC | Texas Instruments | LMC6762AIM/NOPB | LOAD
137 | 1 | U9 | LMK04828 | LMK04828_64WQFN | Texas Instruments | LMK04828BISQE/NOPB | LOAD
138 | 1 | Y1 | 12MHZ | ABM3-12_2SMD | Abracon LLC | ABM3-12.000MHZ-B2-T | LOAD
139 | 1 | Y2 | 100MHZ | CVHD-037X_6SMD | Crystek Corporation | CVHD-950-100.000 | LOAD
140
141 | 4 | Z_SCREW1 Z_SCREW2 Z_SCREW3 Z_SCREW4 | PMSSS 440 0025 PH | PMSSS4400025PH | B&F Fastener Supply | PMSSS 440 0025 PH | LOAD
142 | 3 | Z_SH-H1 Z_SH-J1 Z_SH-J2 | SHUNT-HEADER |  | TE CONNECTIVITY | 1-382811-6

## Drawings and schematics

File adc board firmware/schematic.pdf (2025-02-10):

Date: February 10, 2025 | coincidence.bdf | Project: coincidence
USB data I/O block | Main processor block

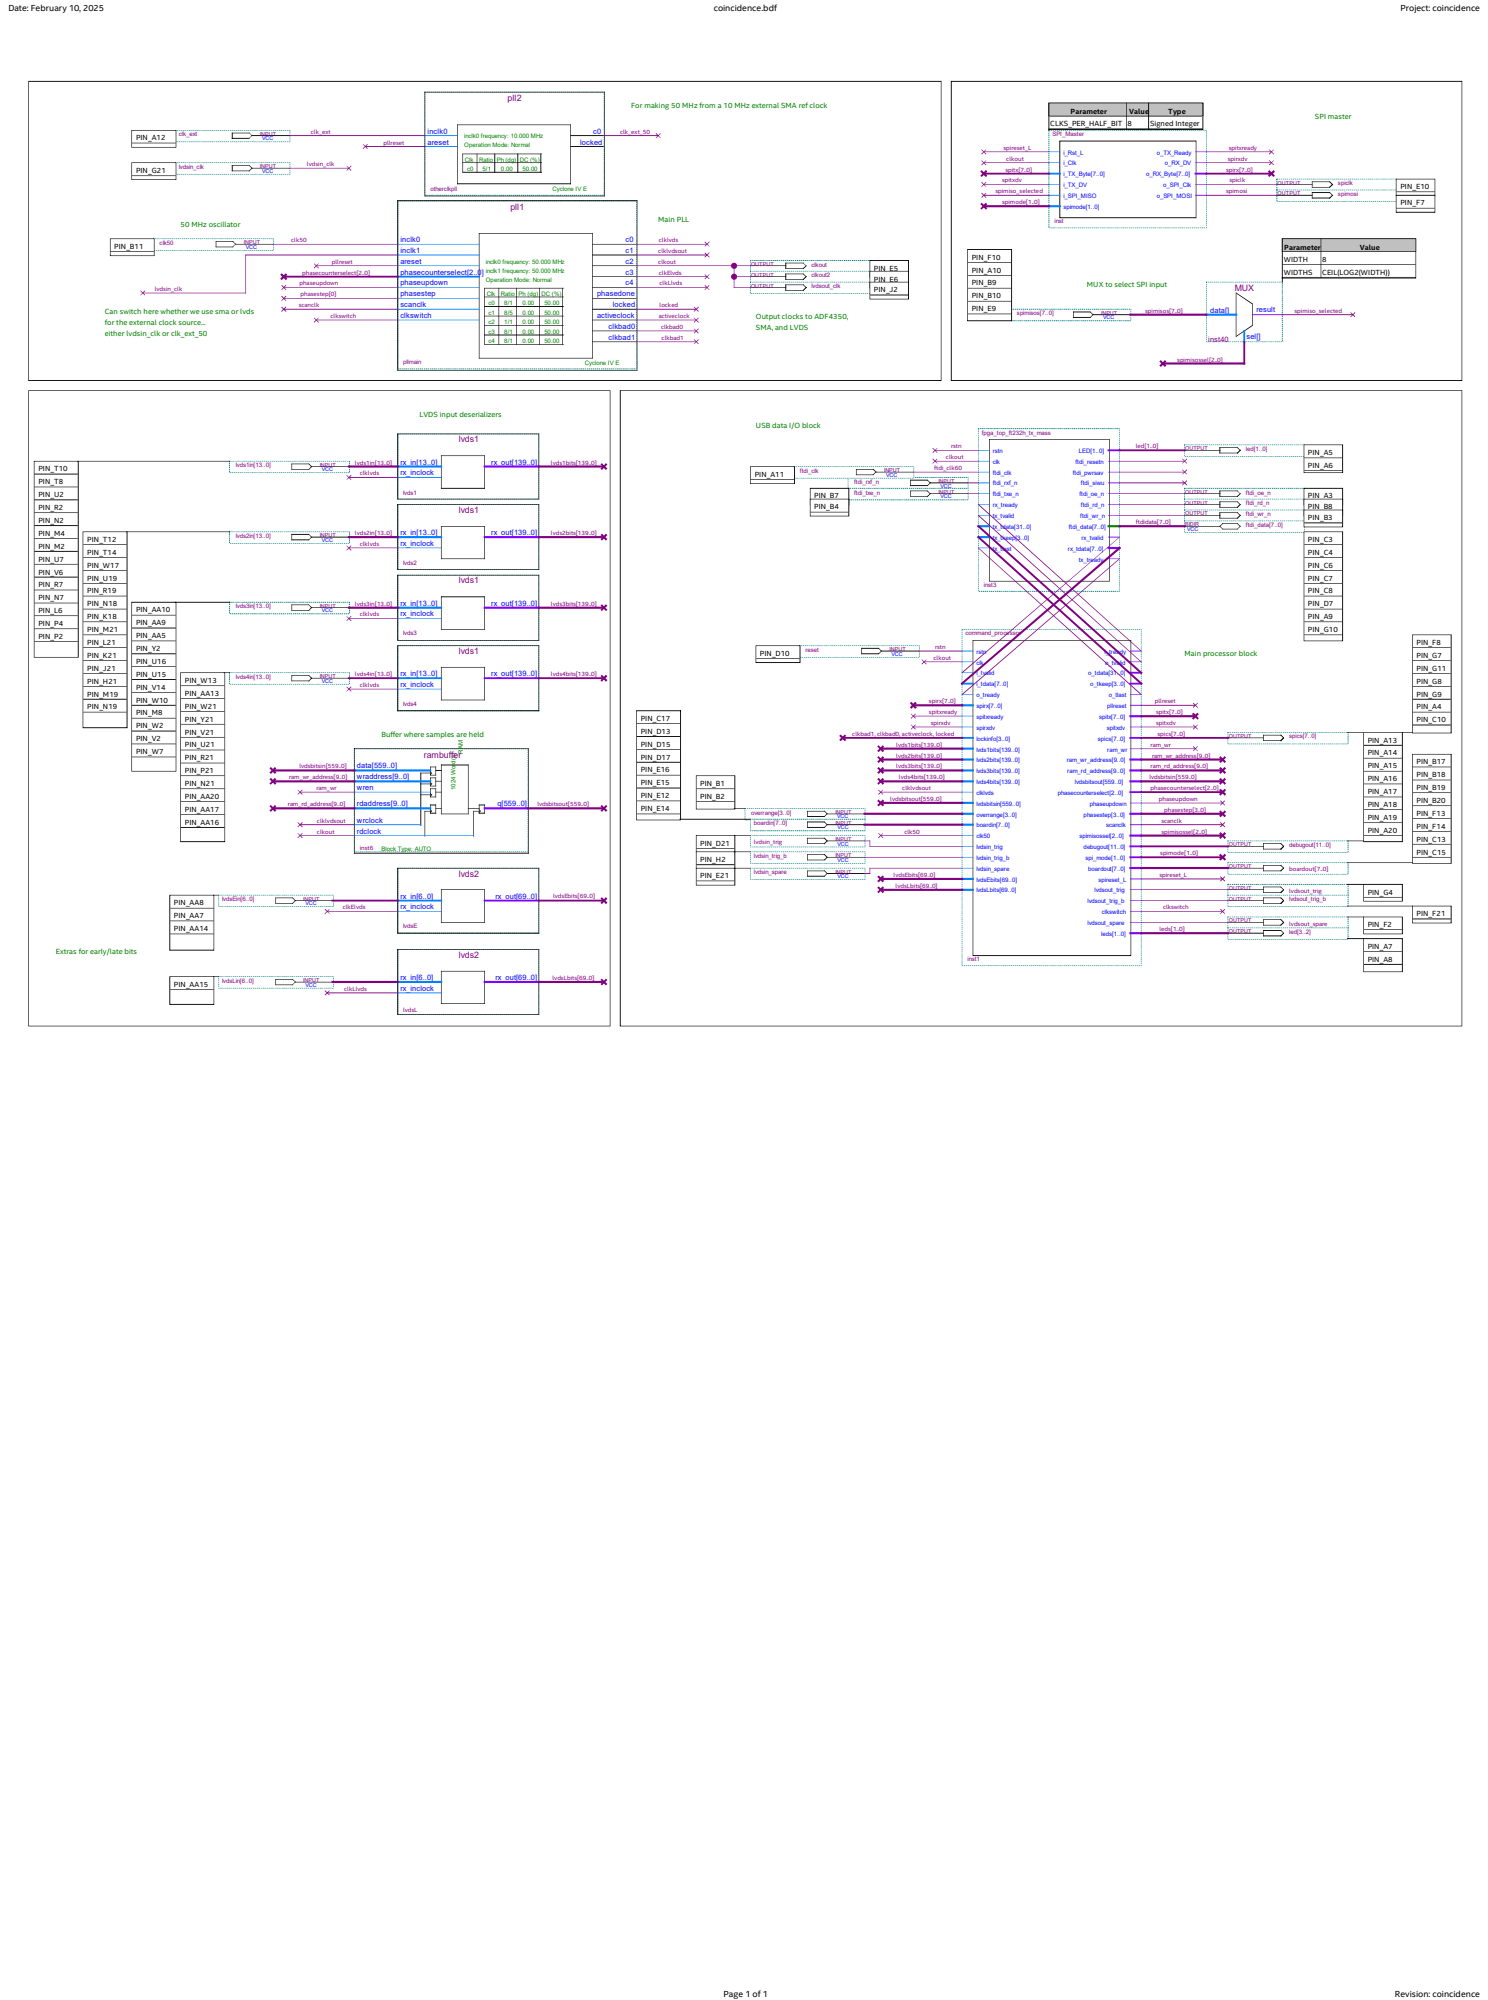
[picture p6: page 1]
Page 1 of 1; Revision: coincidence; Can switch here whether we use sma or lvds 50 MHz oscillator; Output clocks to ADF4350, SMA, and LVDS; for the external clock source... either lvdsin_clk or clk_ext_50; Main PLL; ram_wr_address[9..0] ram_rd_address[9..0] ram_wr; scanclk spimisossel[2..0] spimode[1..0] spireset_L; clkswitch; rstn; spirxdv clkbad1, clkbad0, activeclock, locked lvds1bits[139..0] lvds2bits[139..0] lvds3bits[139..0] lvds4bits[139..0] clklvdsout; lvdsbitsout[559..0] clk50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

For making 50 MHz from a 10 MHz external SMA ref clock

SPI master MUX to select SPI input

inst Cyclone IV E

clkElvds clkLlvds activeclock

LVDS input deserializers

command_processor
clkout spirx[7..0] spitxready

o_tdata[31..0] o_tkeep[3..0] o_tlast pllreset spitx[7..0] spitxdv

pllreset spitx[7..0] spitxdv

Buffer where samples are held

data[559..0] wraddress[9..0] wren

lvdsbitsin[559..0] phasecounterselect[2..0] phasestep[3..0] phaseupdown

lvdsbitsout[559..0] phasecounterselect[2..0] phaseupdown

lvdsbitsin[559..0] overrange[3..0] boardin[7..0] clk50

spimisossel[2..0] debugout[11..0] spi_mode[1..0] boardout[7..0] spireset_L

Block Type: AUTO

lvdsLbits[69..0] clkElvds clkLlvds

Extras for early/late bits

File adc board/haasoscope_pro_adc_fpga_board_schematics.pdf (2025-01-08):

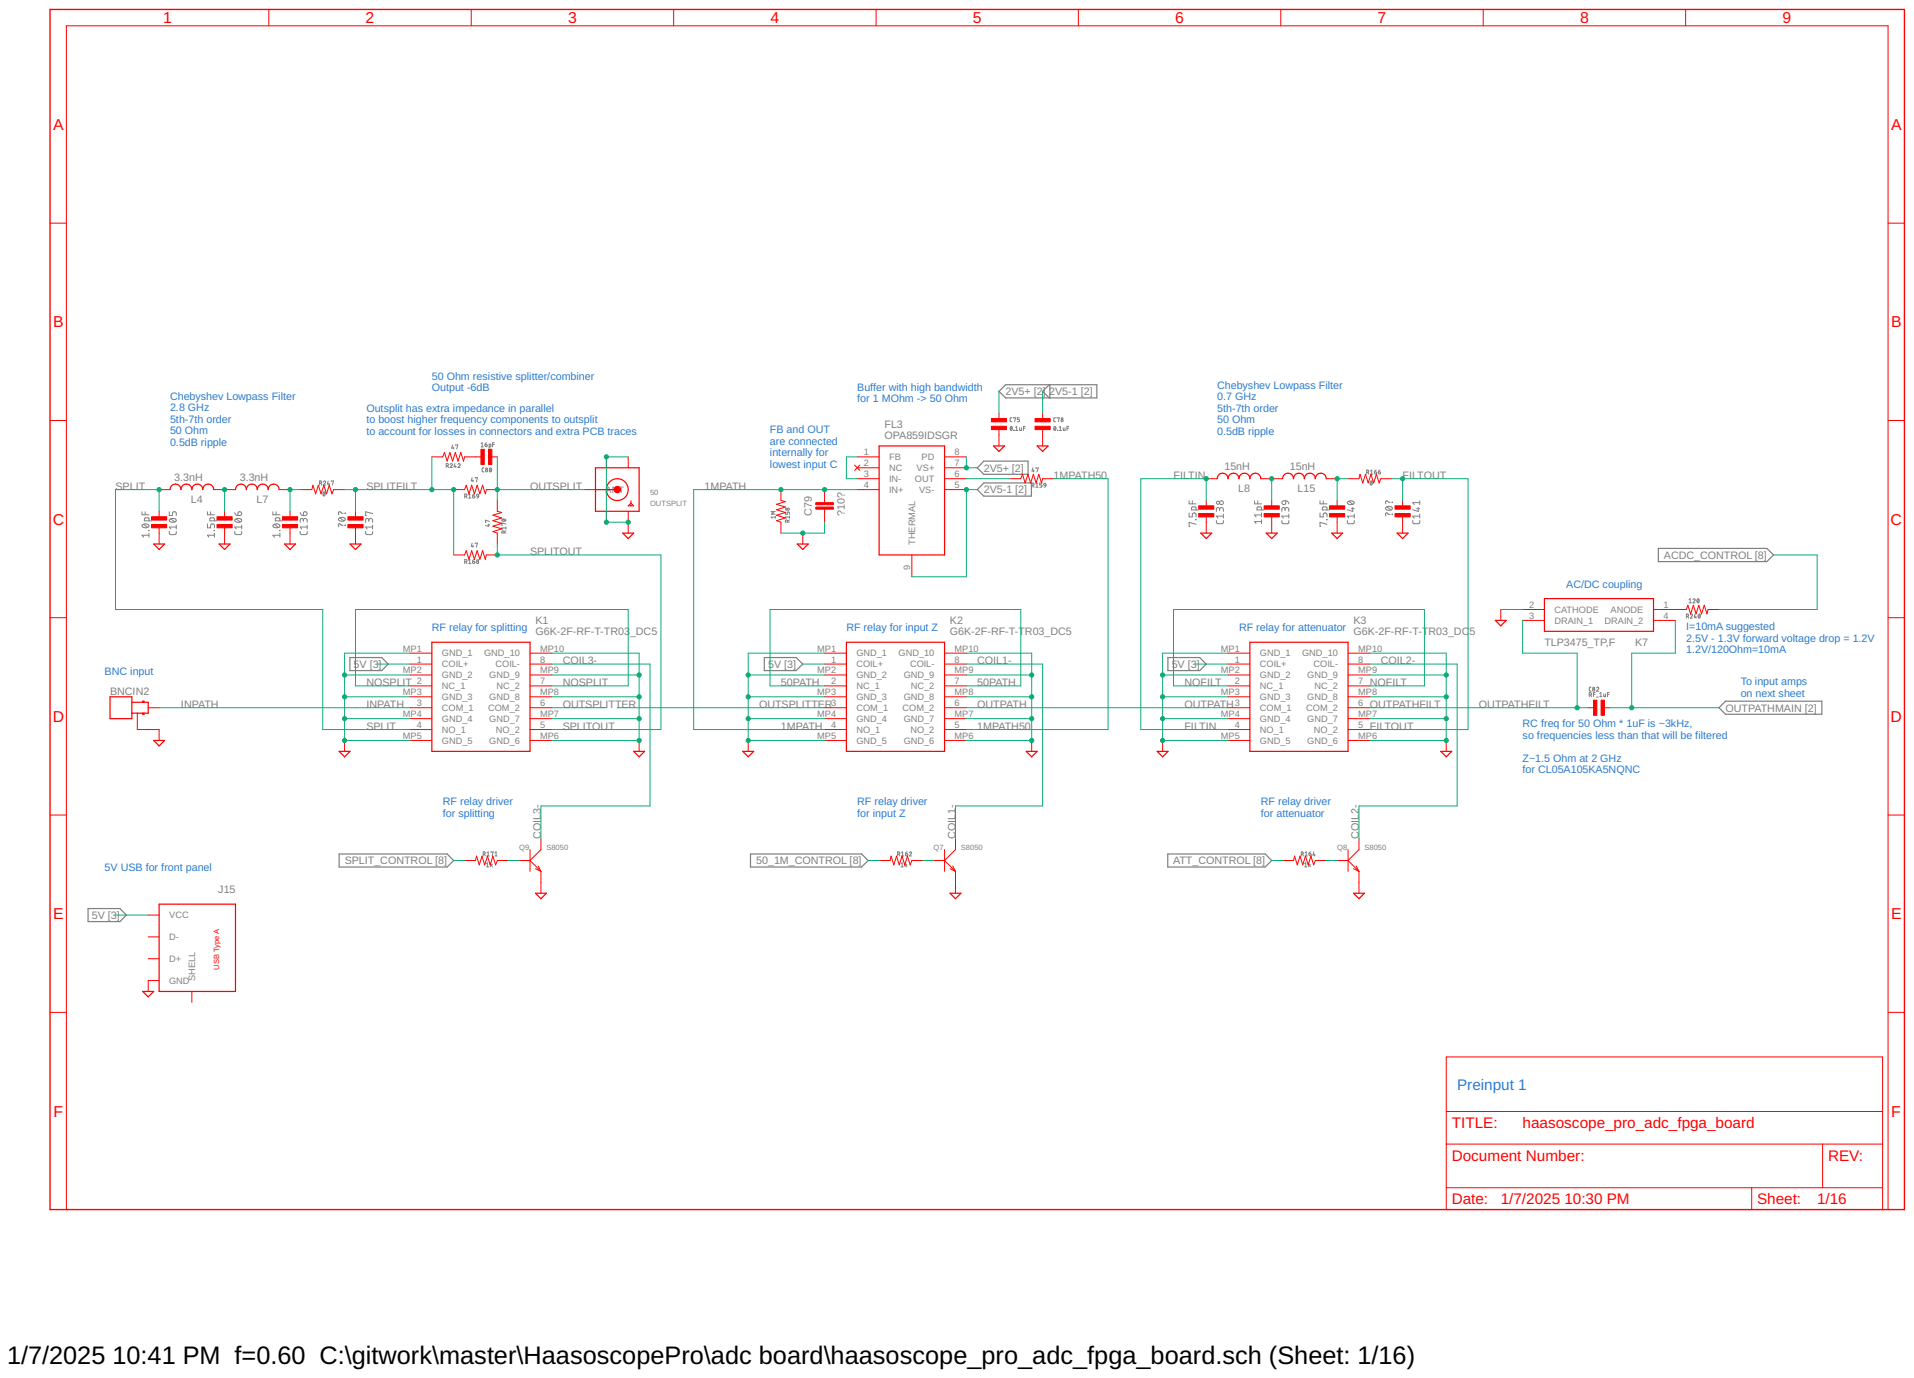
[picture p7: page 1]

to account for losses in connectors and extra PCB traces Chebyshev Lowpass Filter 2.8 GHz 5th-7th order 50 Ohm

50 Ohm resistive splitter/combiner Output -6dB

Buffer with high bandwidth
for 1 MOhm -> 50 Ohm

Outsplit has extra impedance in parallel to boost higher frequency components to outsplit

RF relay for splitting

RF relay for input Z

RF relay for attenuator

To input amps on next sheet

RC freq for 50 Ohm * 1uF is ~3kHz, so frequencies less than that will be filtered Z~1.5 Ohm at 2 GHz

5V USB for front panel

1/7/2025 10:41 PM f=0.60 C:\gitwork\master\HaasoscopePro\adc board\haasoscope_pro_adc_fpga_board.sch (Sheet: 1/16)

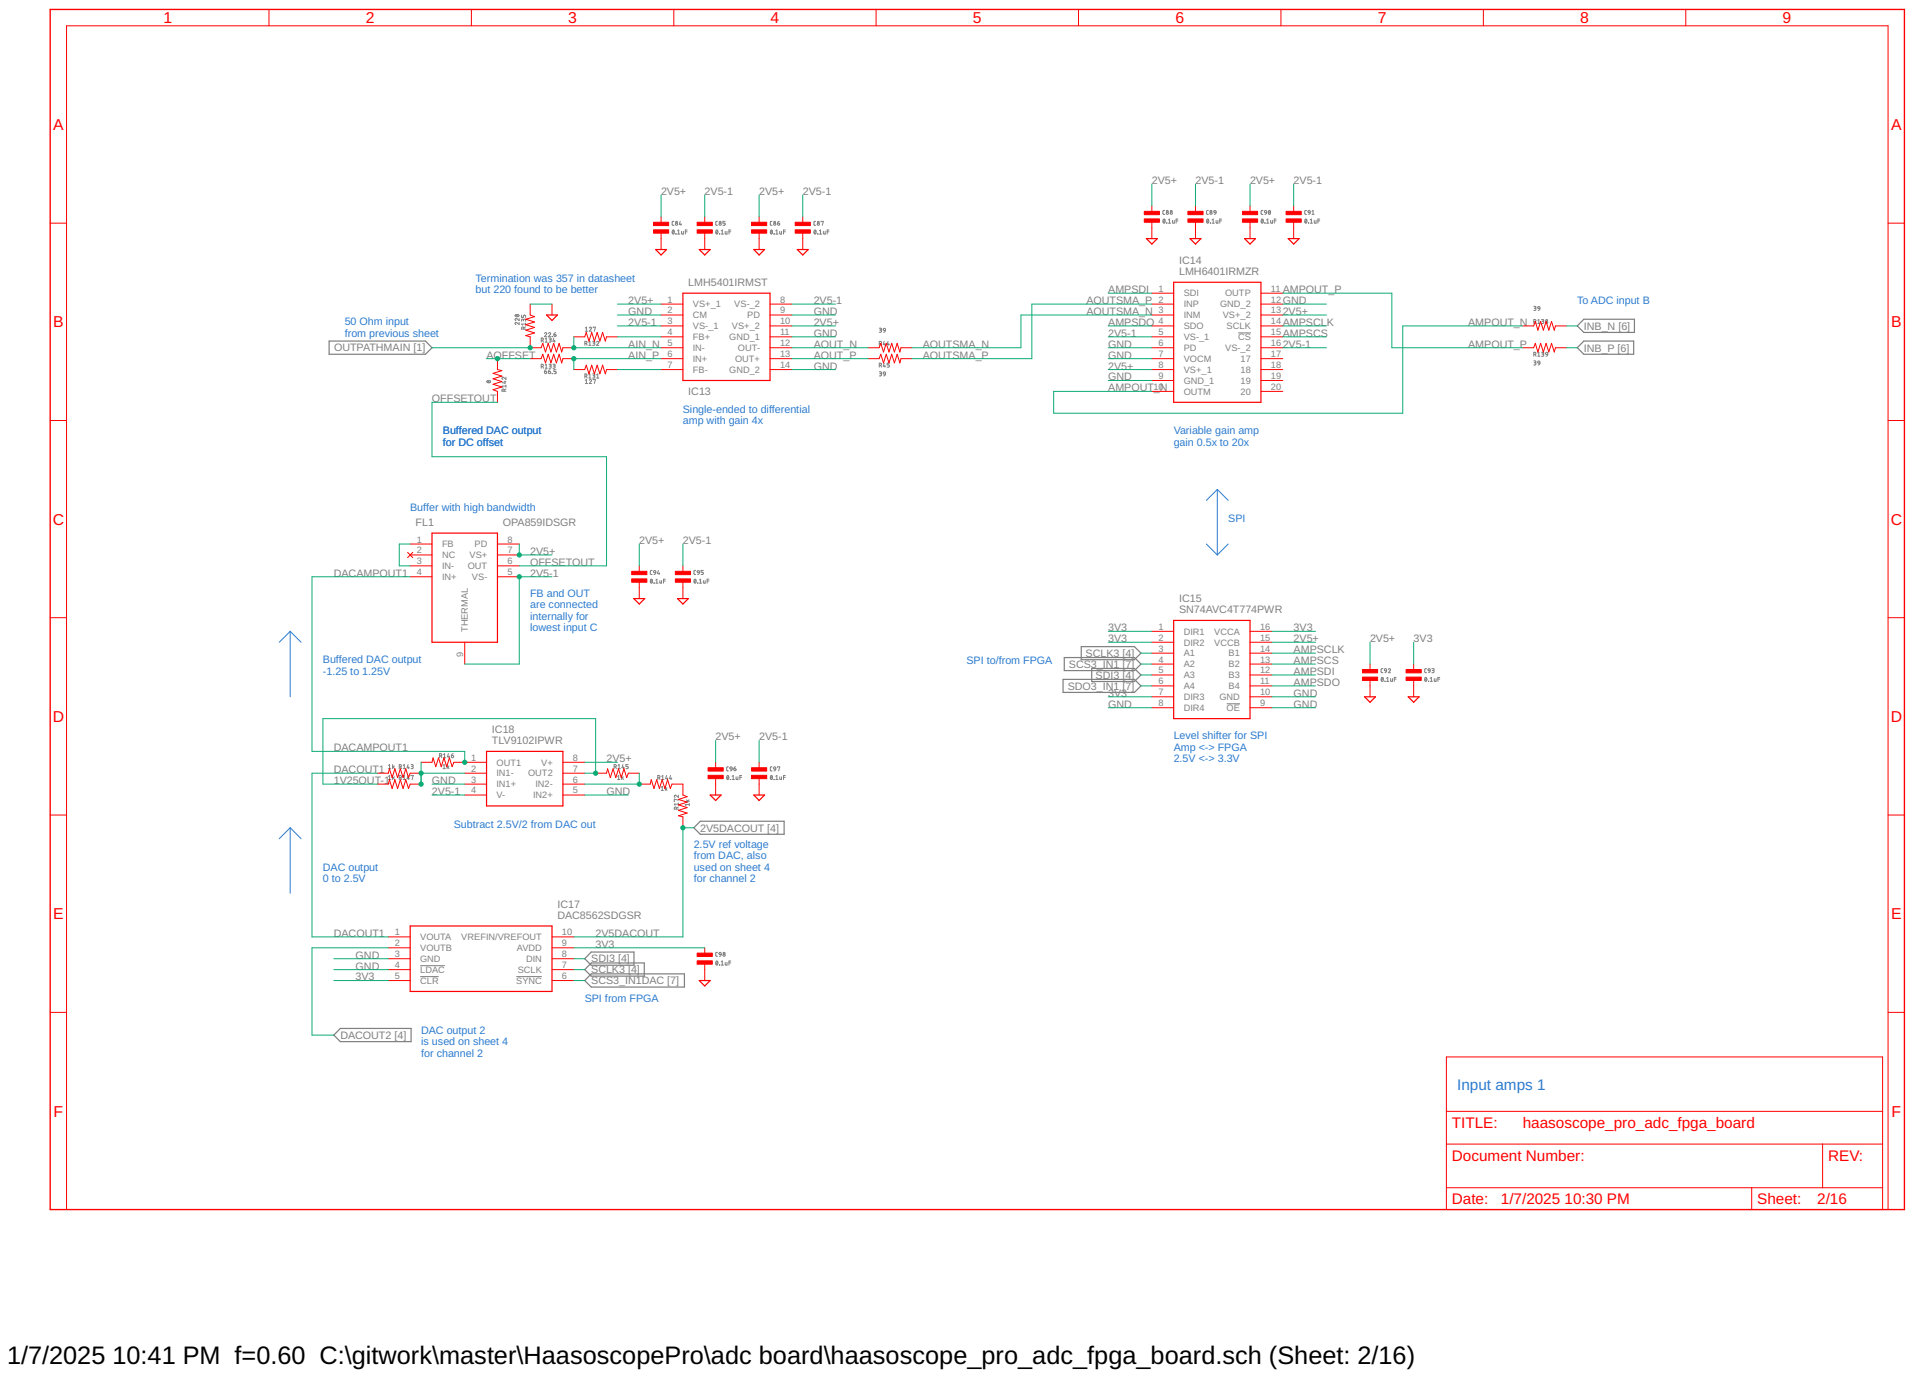
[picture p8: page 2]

Termination was 357 in datasheet but 220 found to be better

Buffer with high bandwidth

Buffered DAC output -1.25 to 1.25V

SPI to/from FPGA

Level shifter for SPI Amp <-> FPGA

Subtract 2.5V/2 from DAC out

for channel 2 DAC output 0 to 2.5V

DAC output 2
is used on sheet 4
for channel 2

1/7/2025 10:41 PM f=0.60 C:\gitwork\master\HaasoscopePro\adc board\haasoscope_pro_adc_fpga_board.sch (Sheet: 2/16)

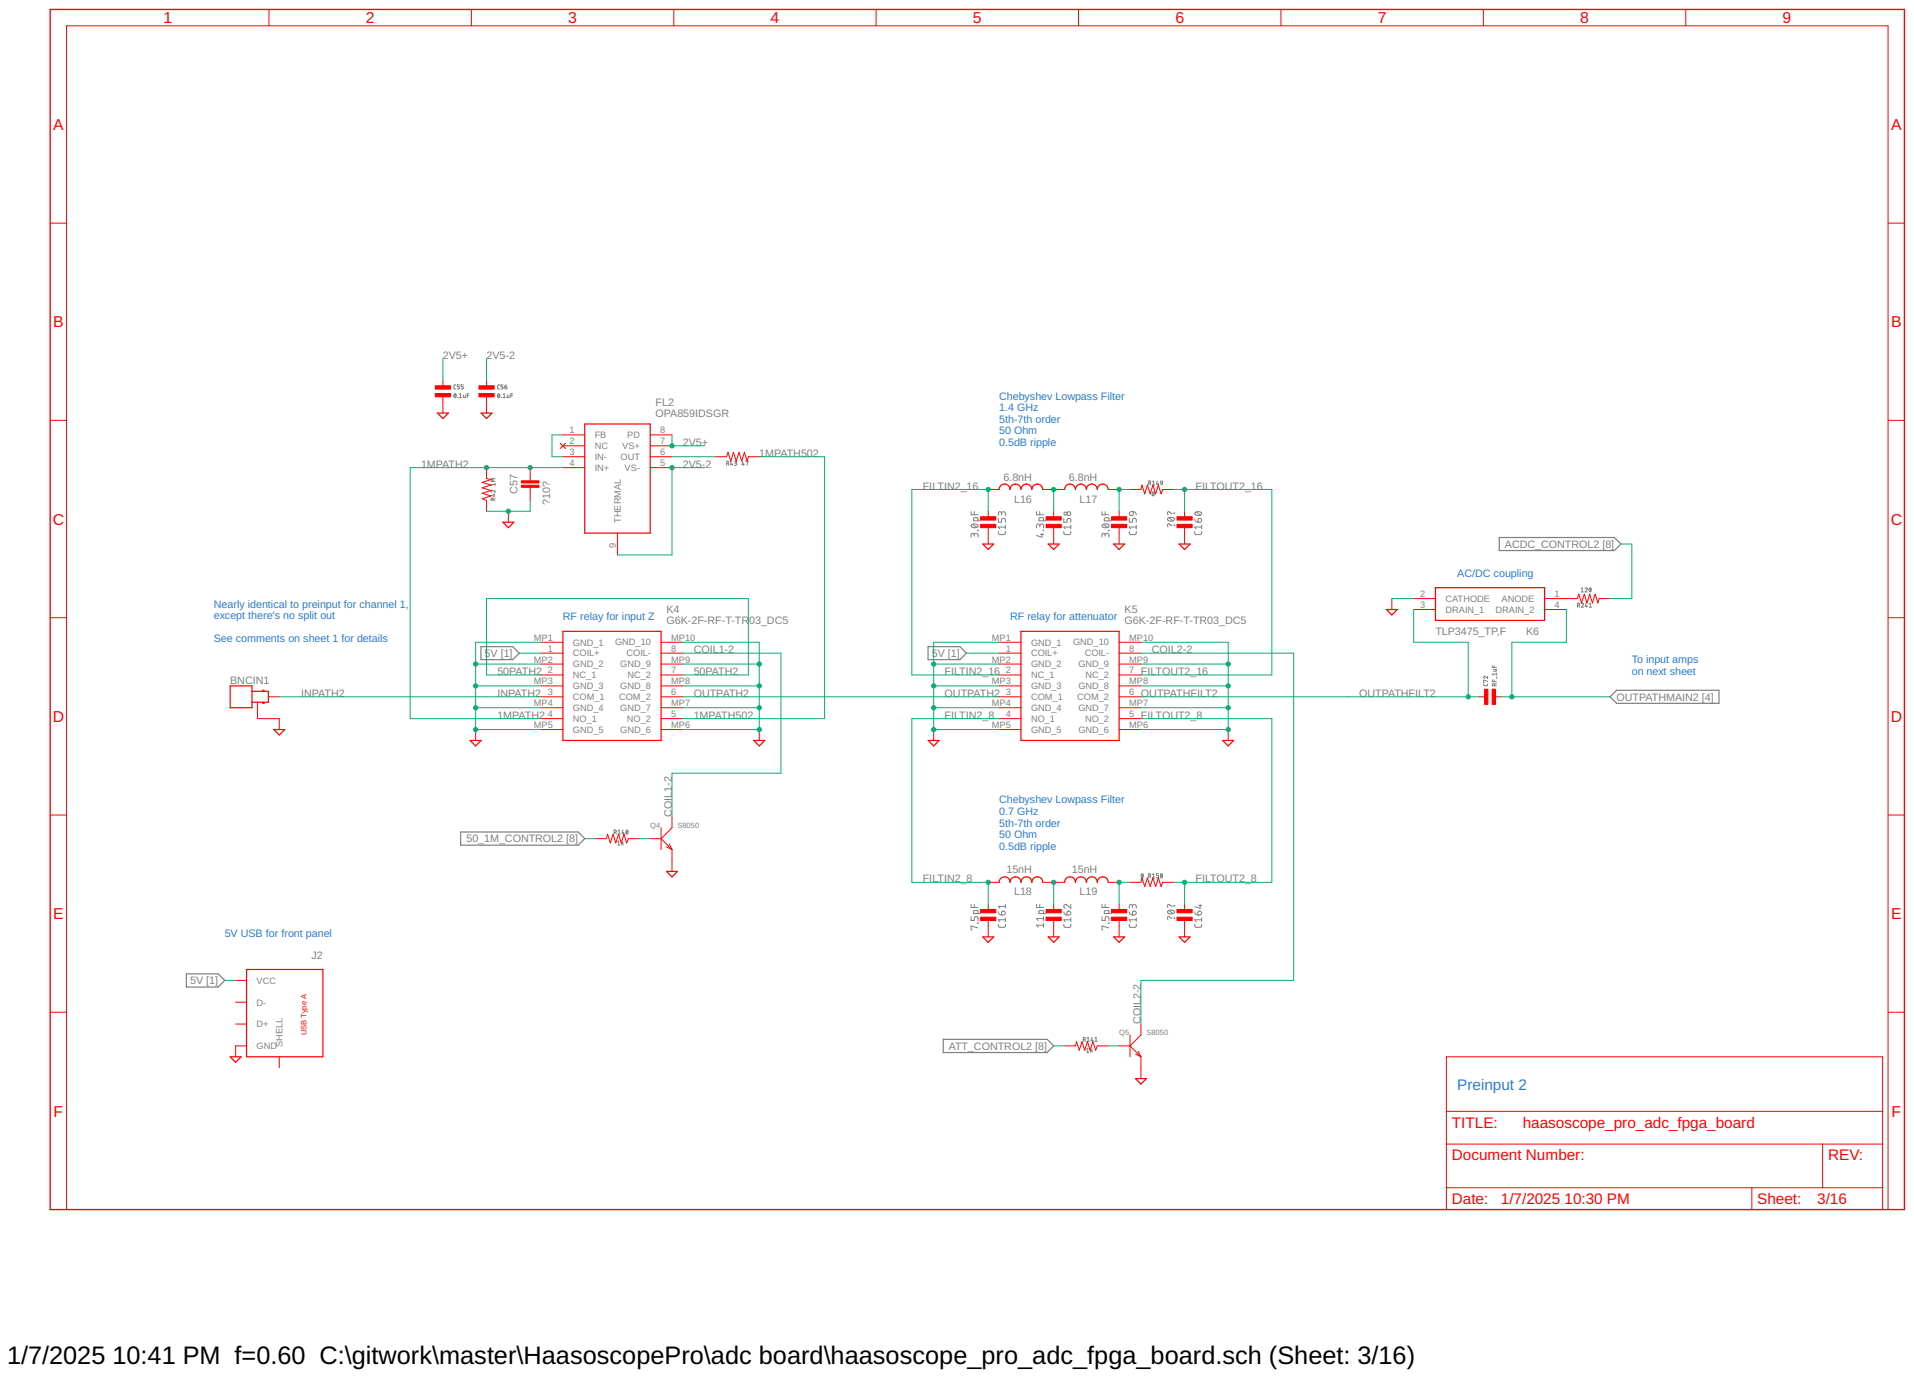
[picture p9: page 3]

Chebyshev Lowpass Filter 1.4 GHz 5th-7th order 50 Ohm

Nearly identical to preinput for channel 1, except there's no split out See comments on sheet 1 for details

To input amps on next sheet

Chebyshev Lowpass Filter 0.7 GHz 5th-7th order 50 Ohm

5V USB for front panel

1/7/2025 10:41 PM f=0.60 C:\gitwork\master\HaasoscopePro\adc board\haasoscope_pro_adc_fpga_board.sch (Sheet: 3/16)

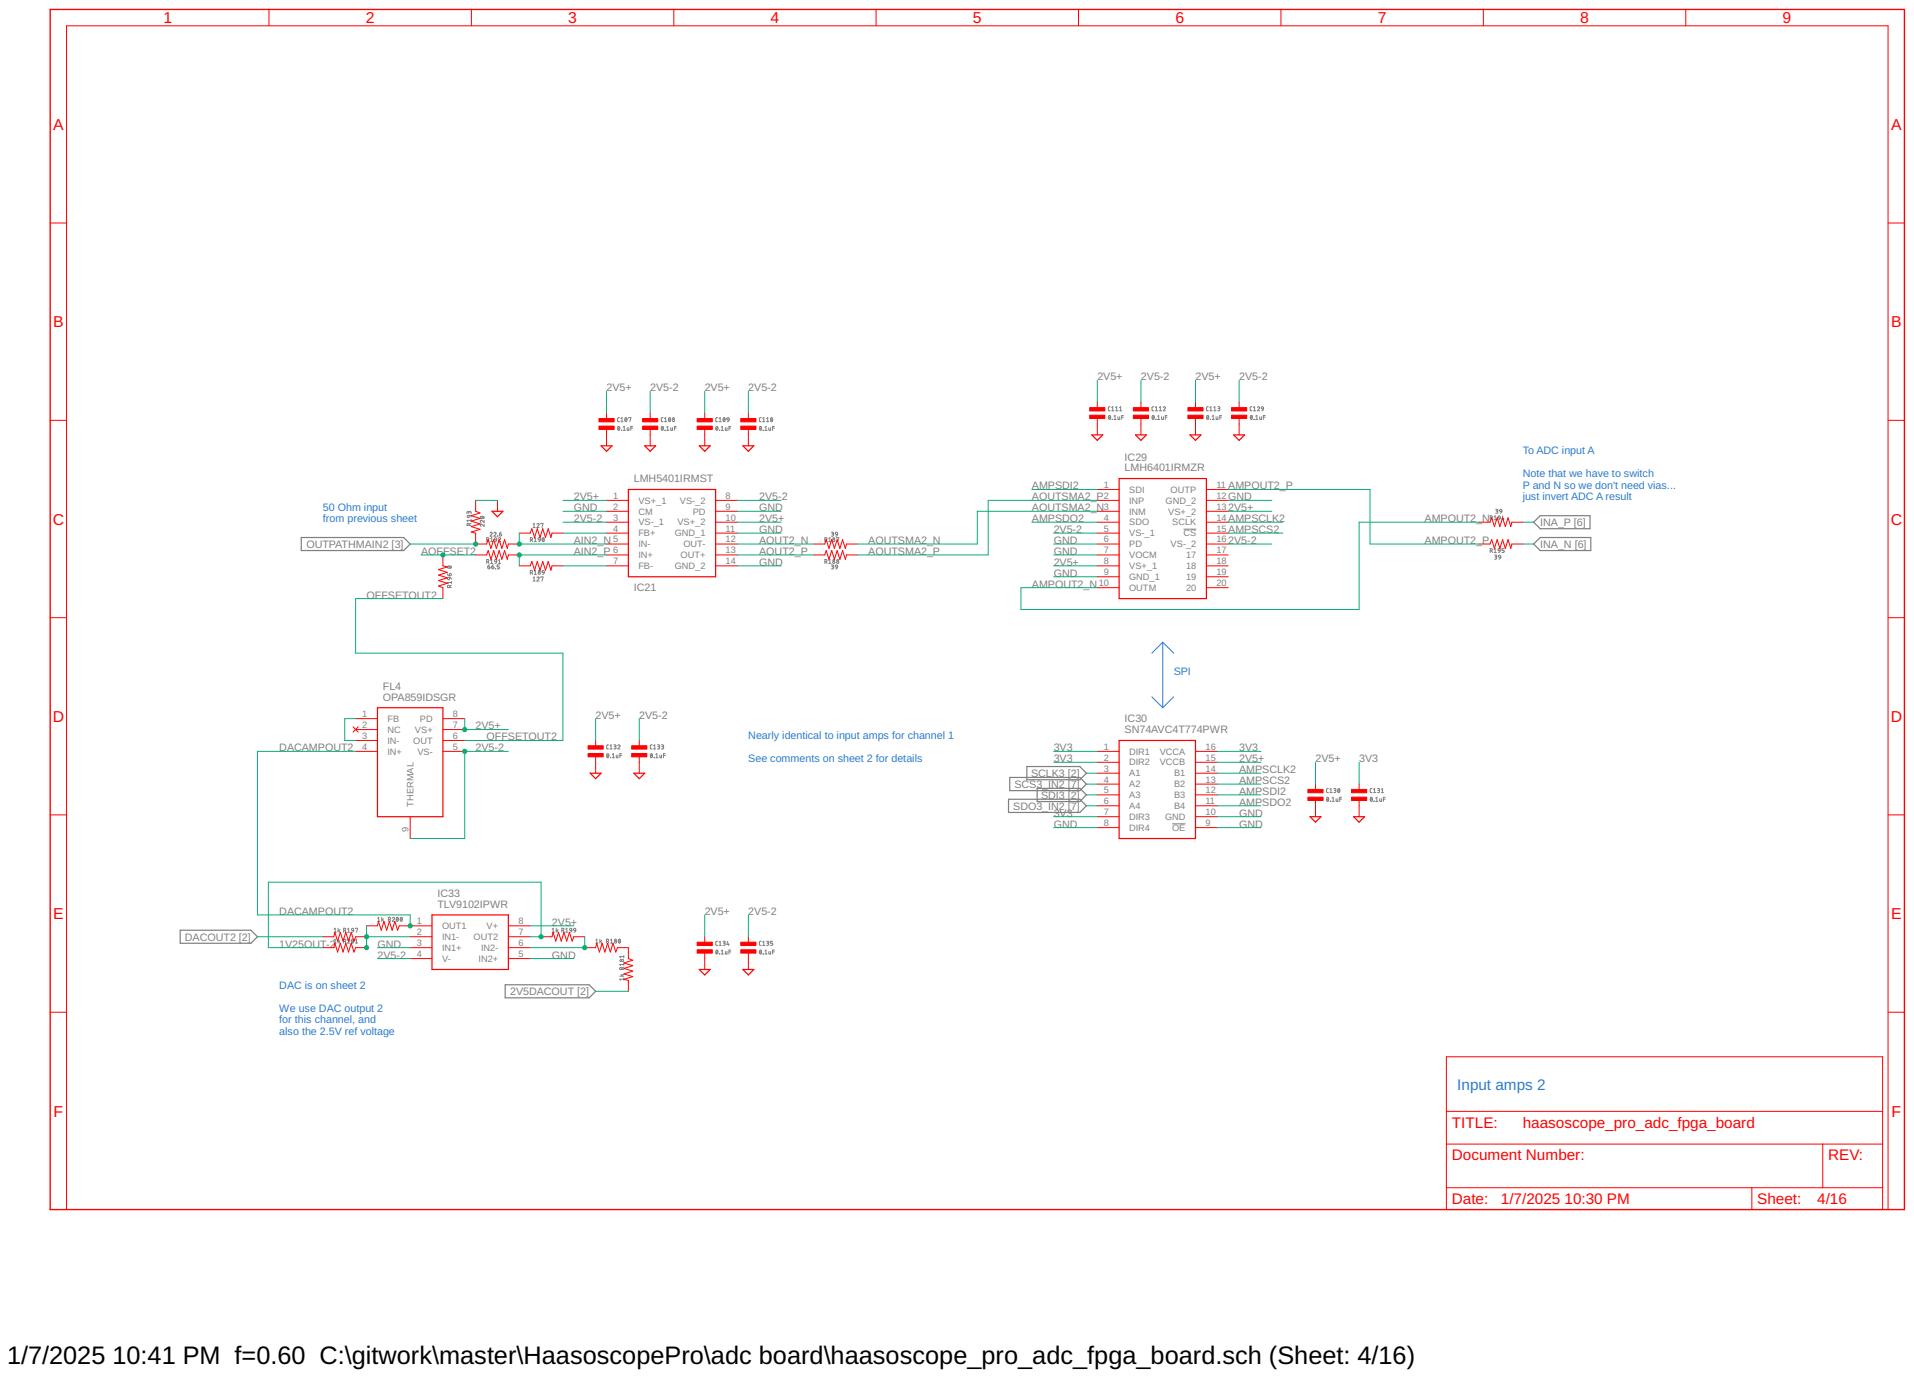
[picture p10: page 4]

To ADC input A Note that we have to switch P and N so we don't need vias...

just invert ADC A result

Nearly identical to input amps for channel 1 See comments on sheet 2 for details

DAC is on sheet 2 We use DAC output 2

for this channel, and
also the 2.5V ref voltage

1/7/2025 10:41 PM f=0.60 C:\gitwork\master\HaasoscopePro\adc board\haasoscope_pro_adc_fpga_board.sch (Sheet: 4/16)

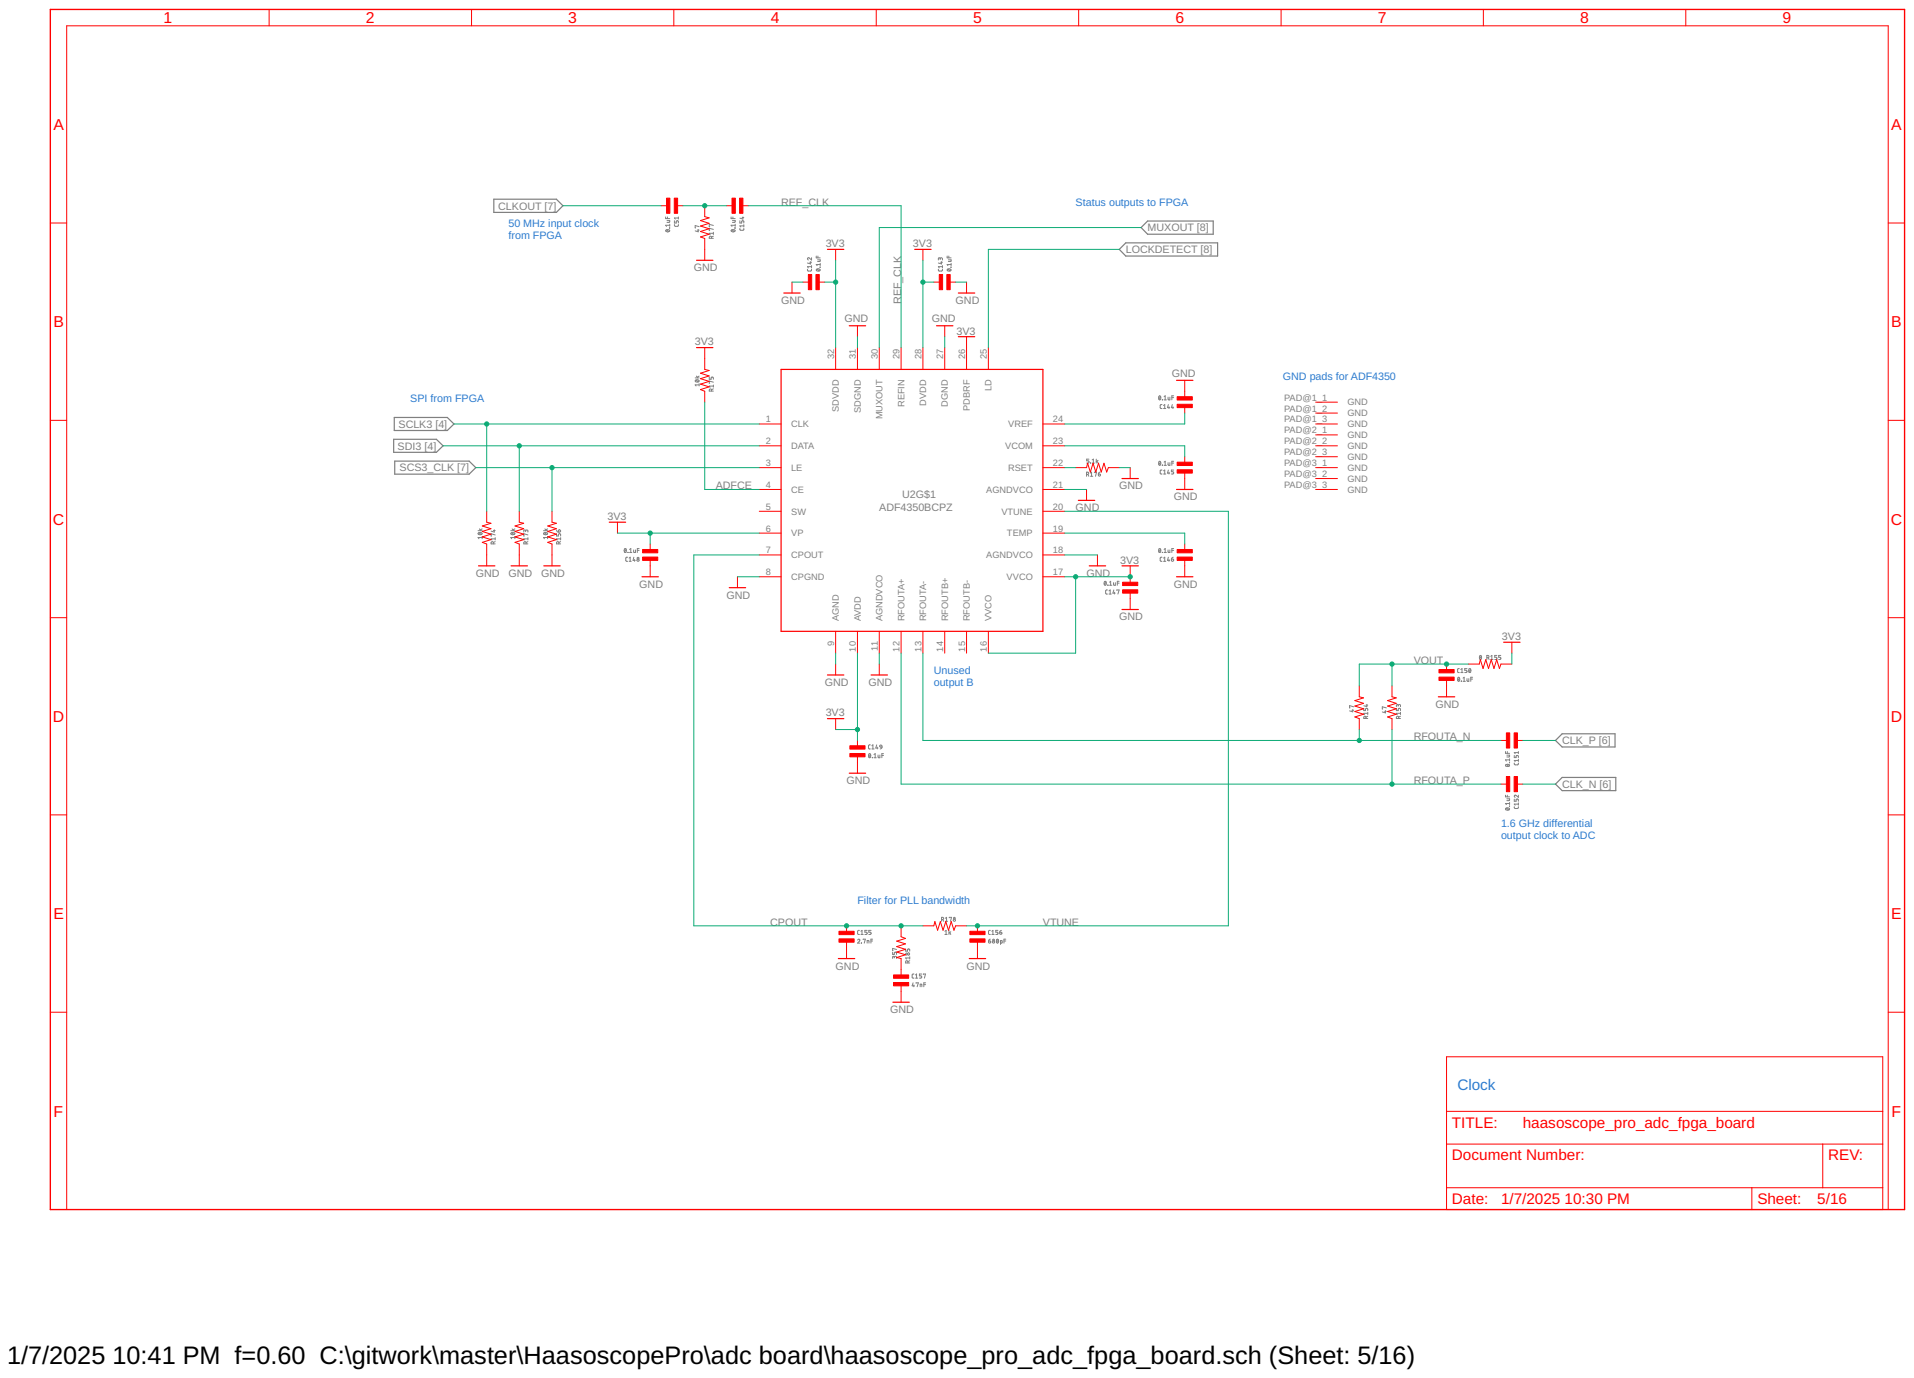
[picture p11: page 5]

Status outputs to FPGA

GND GND

1.6 GHz differential output clock to ADC

Filter for PLL bandwidth

1/7/2025 10:41 PM f=0.60 C:\gitwork\master\HaasoscopePro\adc board\haasoscope_pro_adc_fpga_board.sch (Sheet: 5/16)

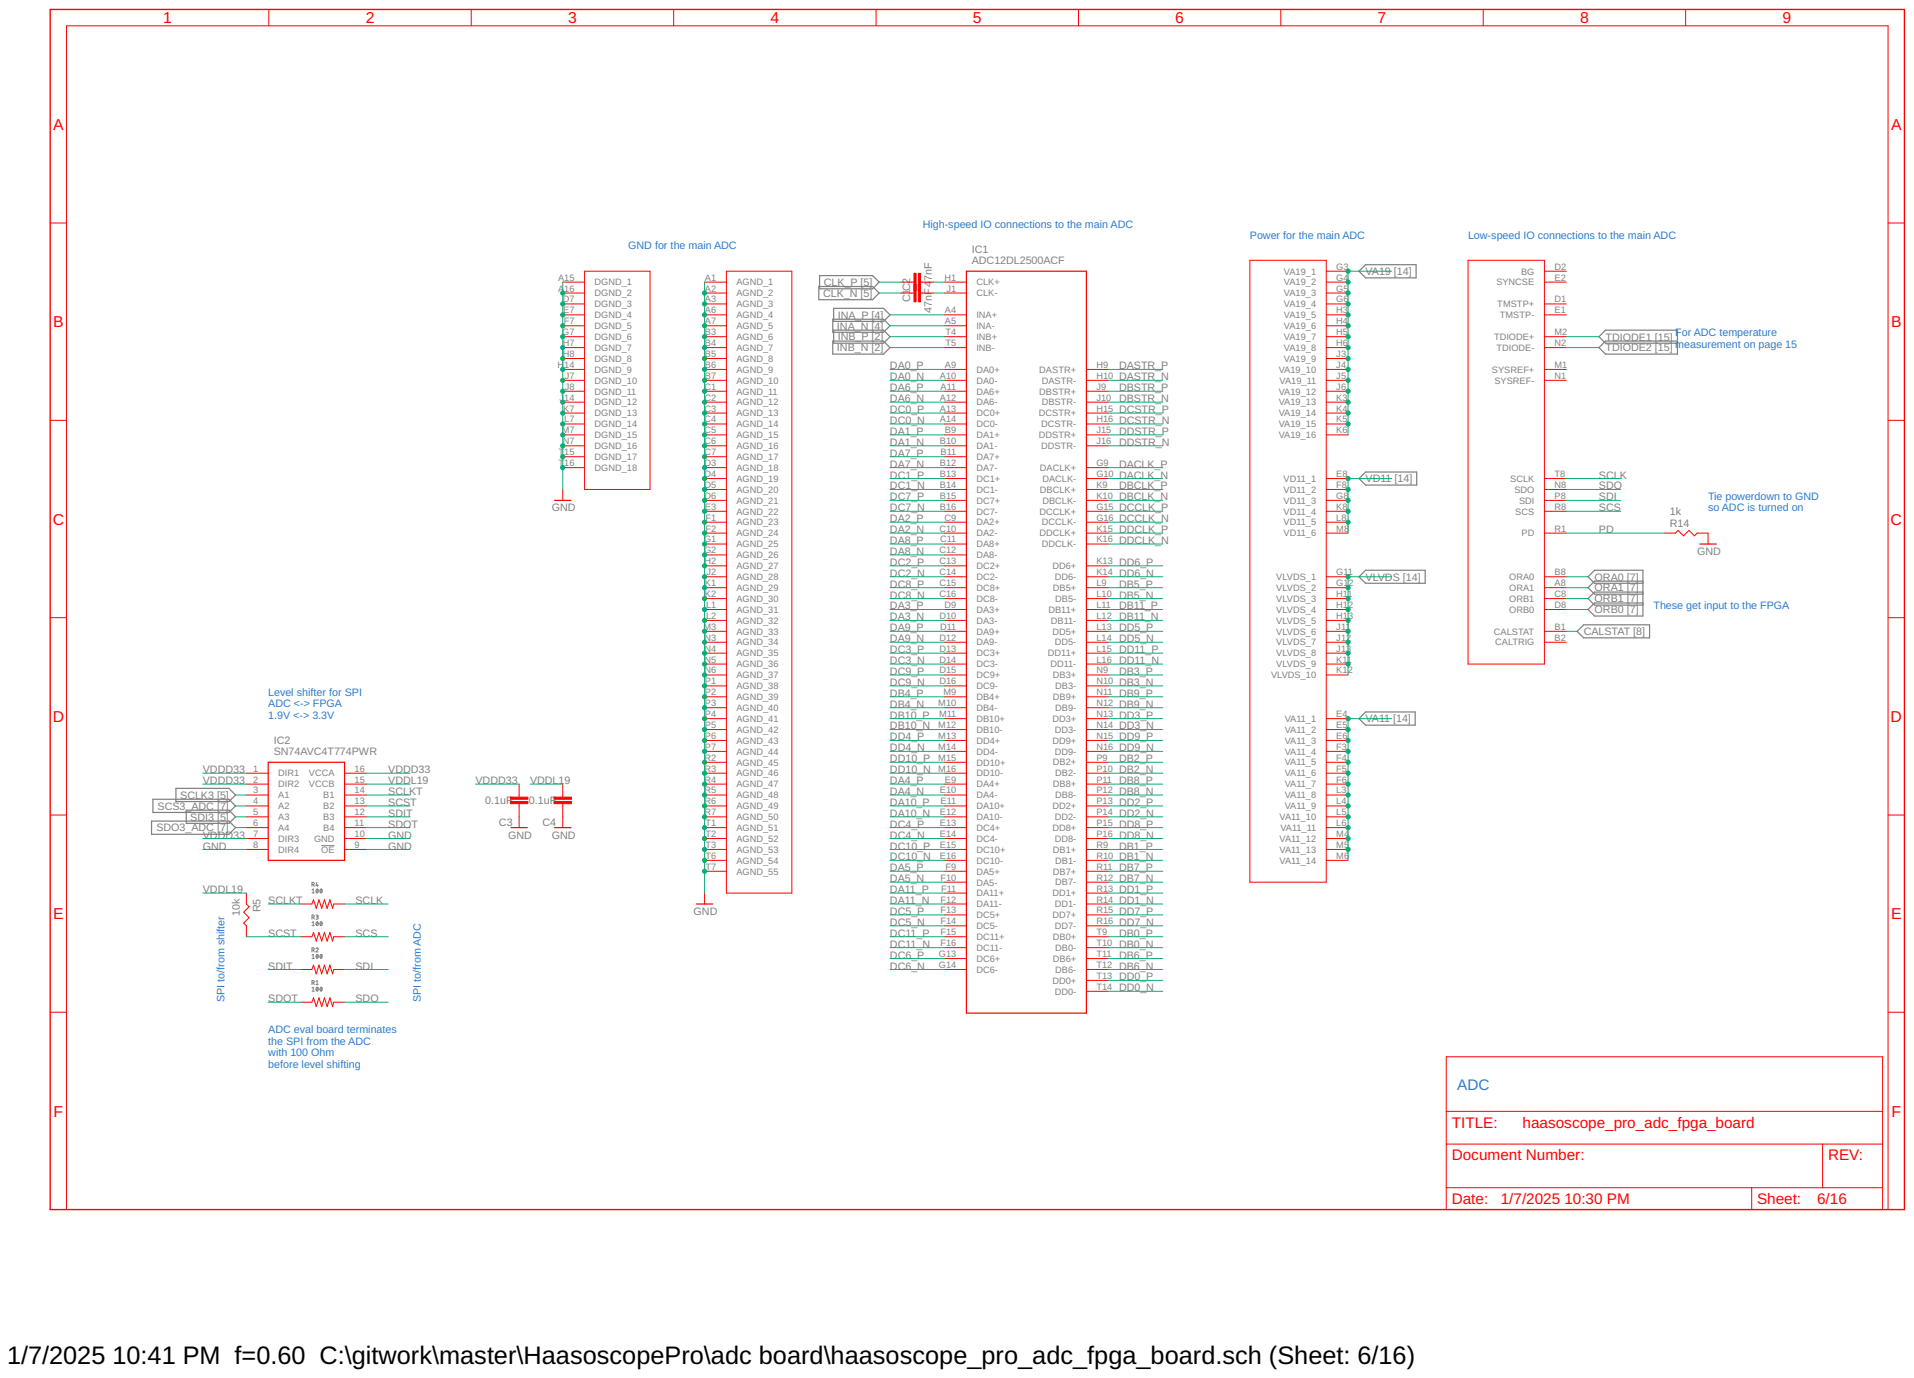
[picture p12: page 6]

High-speed IO connections to the main ADC

For ADC temperature measurement on page 15

Tie powerdown to GND
so ADC is turned on

These get input to the FPGA

Level shifter for SPI ADC <-> FPGA

SPI to/from shifter

SPI to/from ADC

ADC eval board terminates
the SPI from the ADC
with 100 Ohm
before level shifting

1/7/2025 10:41 PM f=0.60 C:\gitwork\master\HaasoscopePro\adc board\haasoscope_pro_adc_fpga_board.sch (Sheet: 6/16)

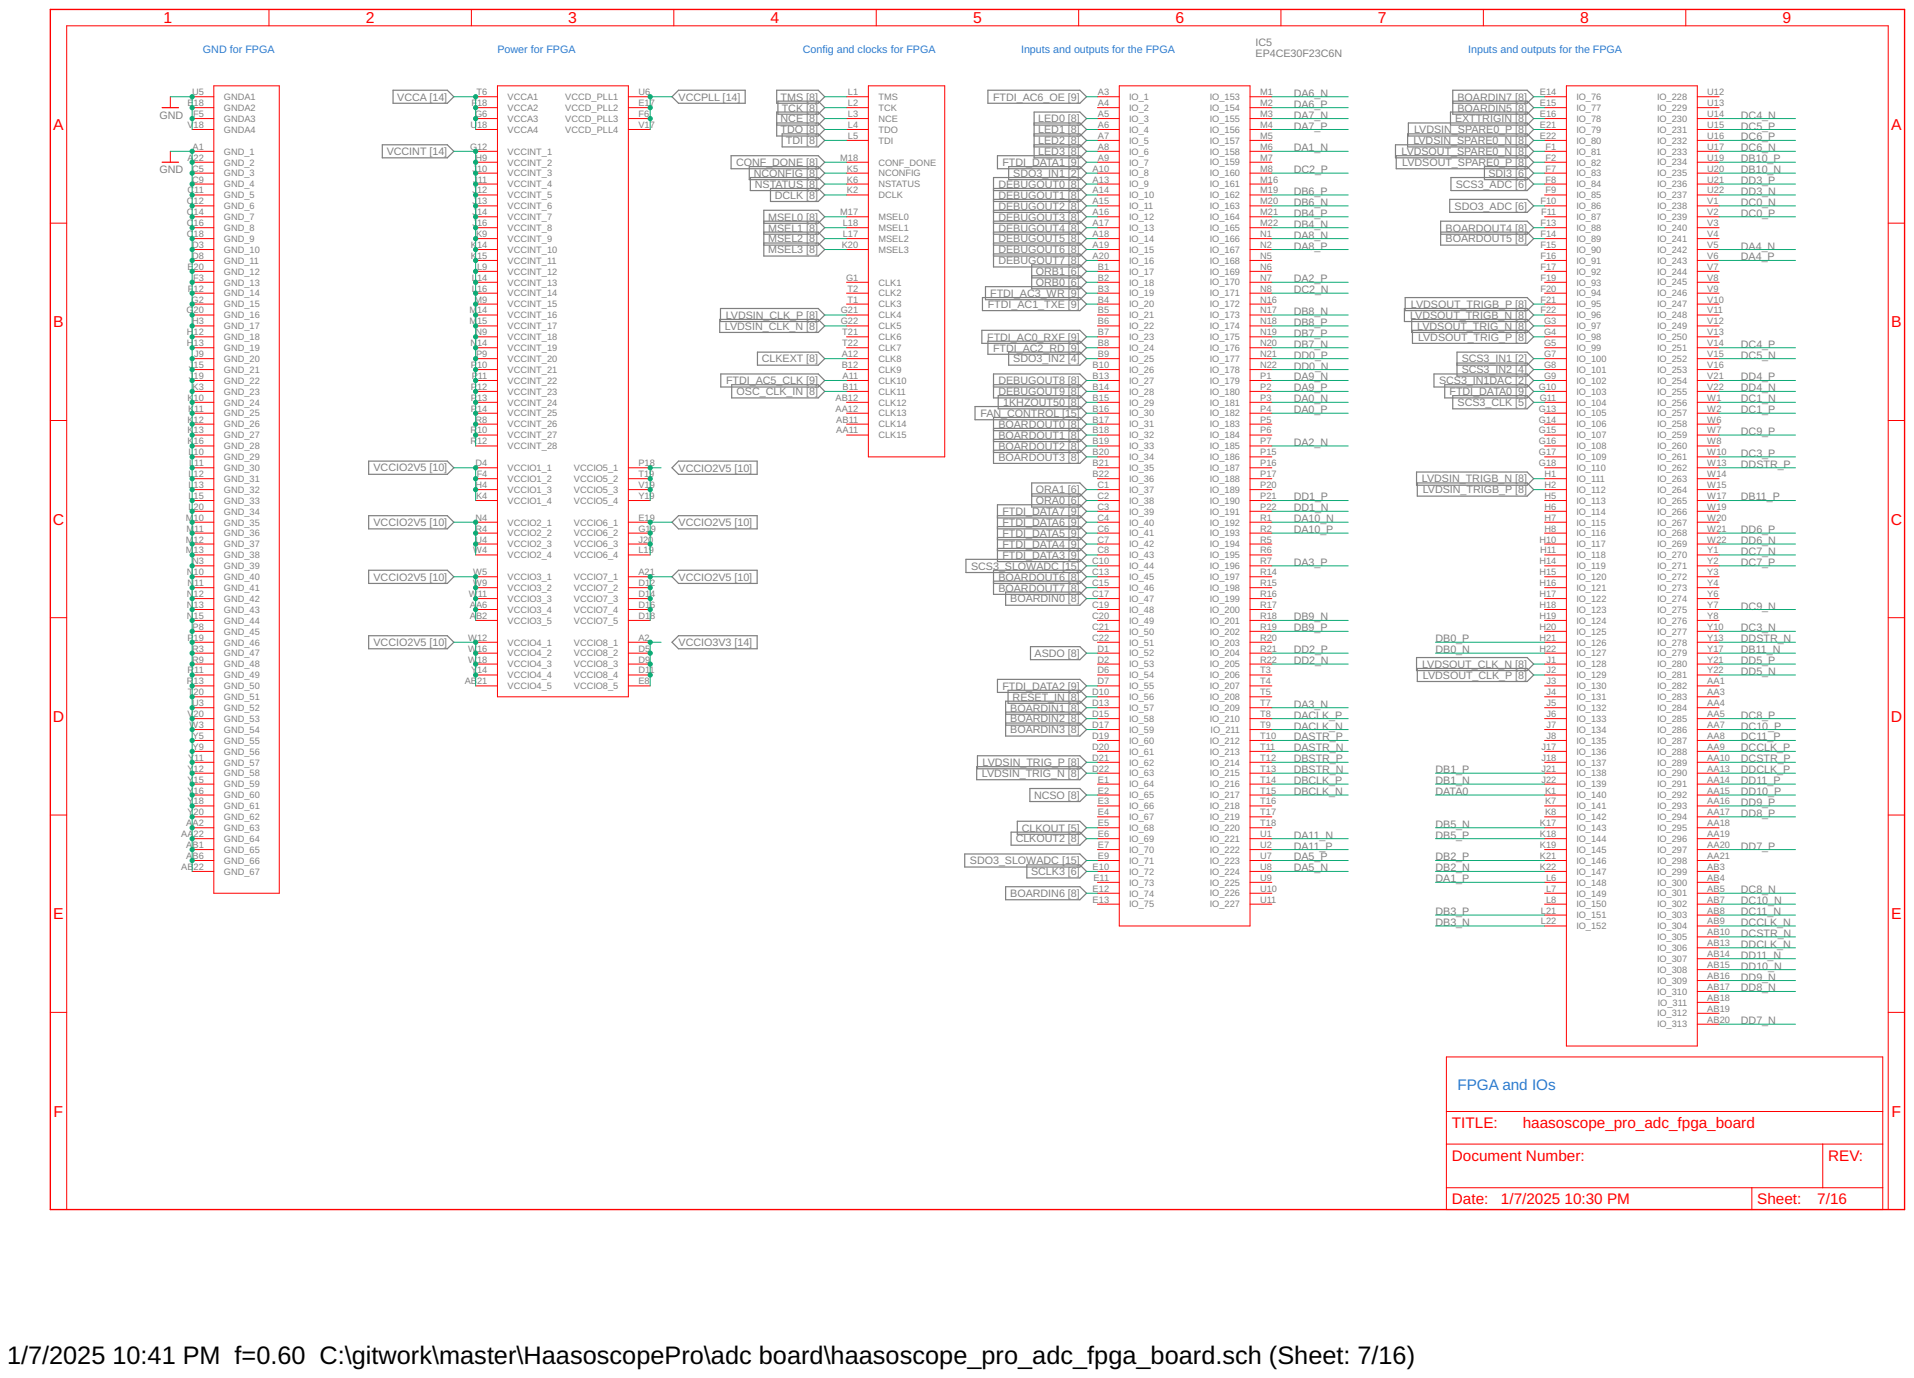
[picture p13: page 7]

TMS [8] TCK [8] NCE [8] TDO [8] TDI [8]

1/7/2025 10:41 PM f=0.60 C:\gitwork\master\HaasoscopePro\adc board\haasoscope_pro_adc_fpga_board.sch (Sheet: 7/16)

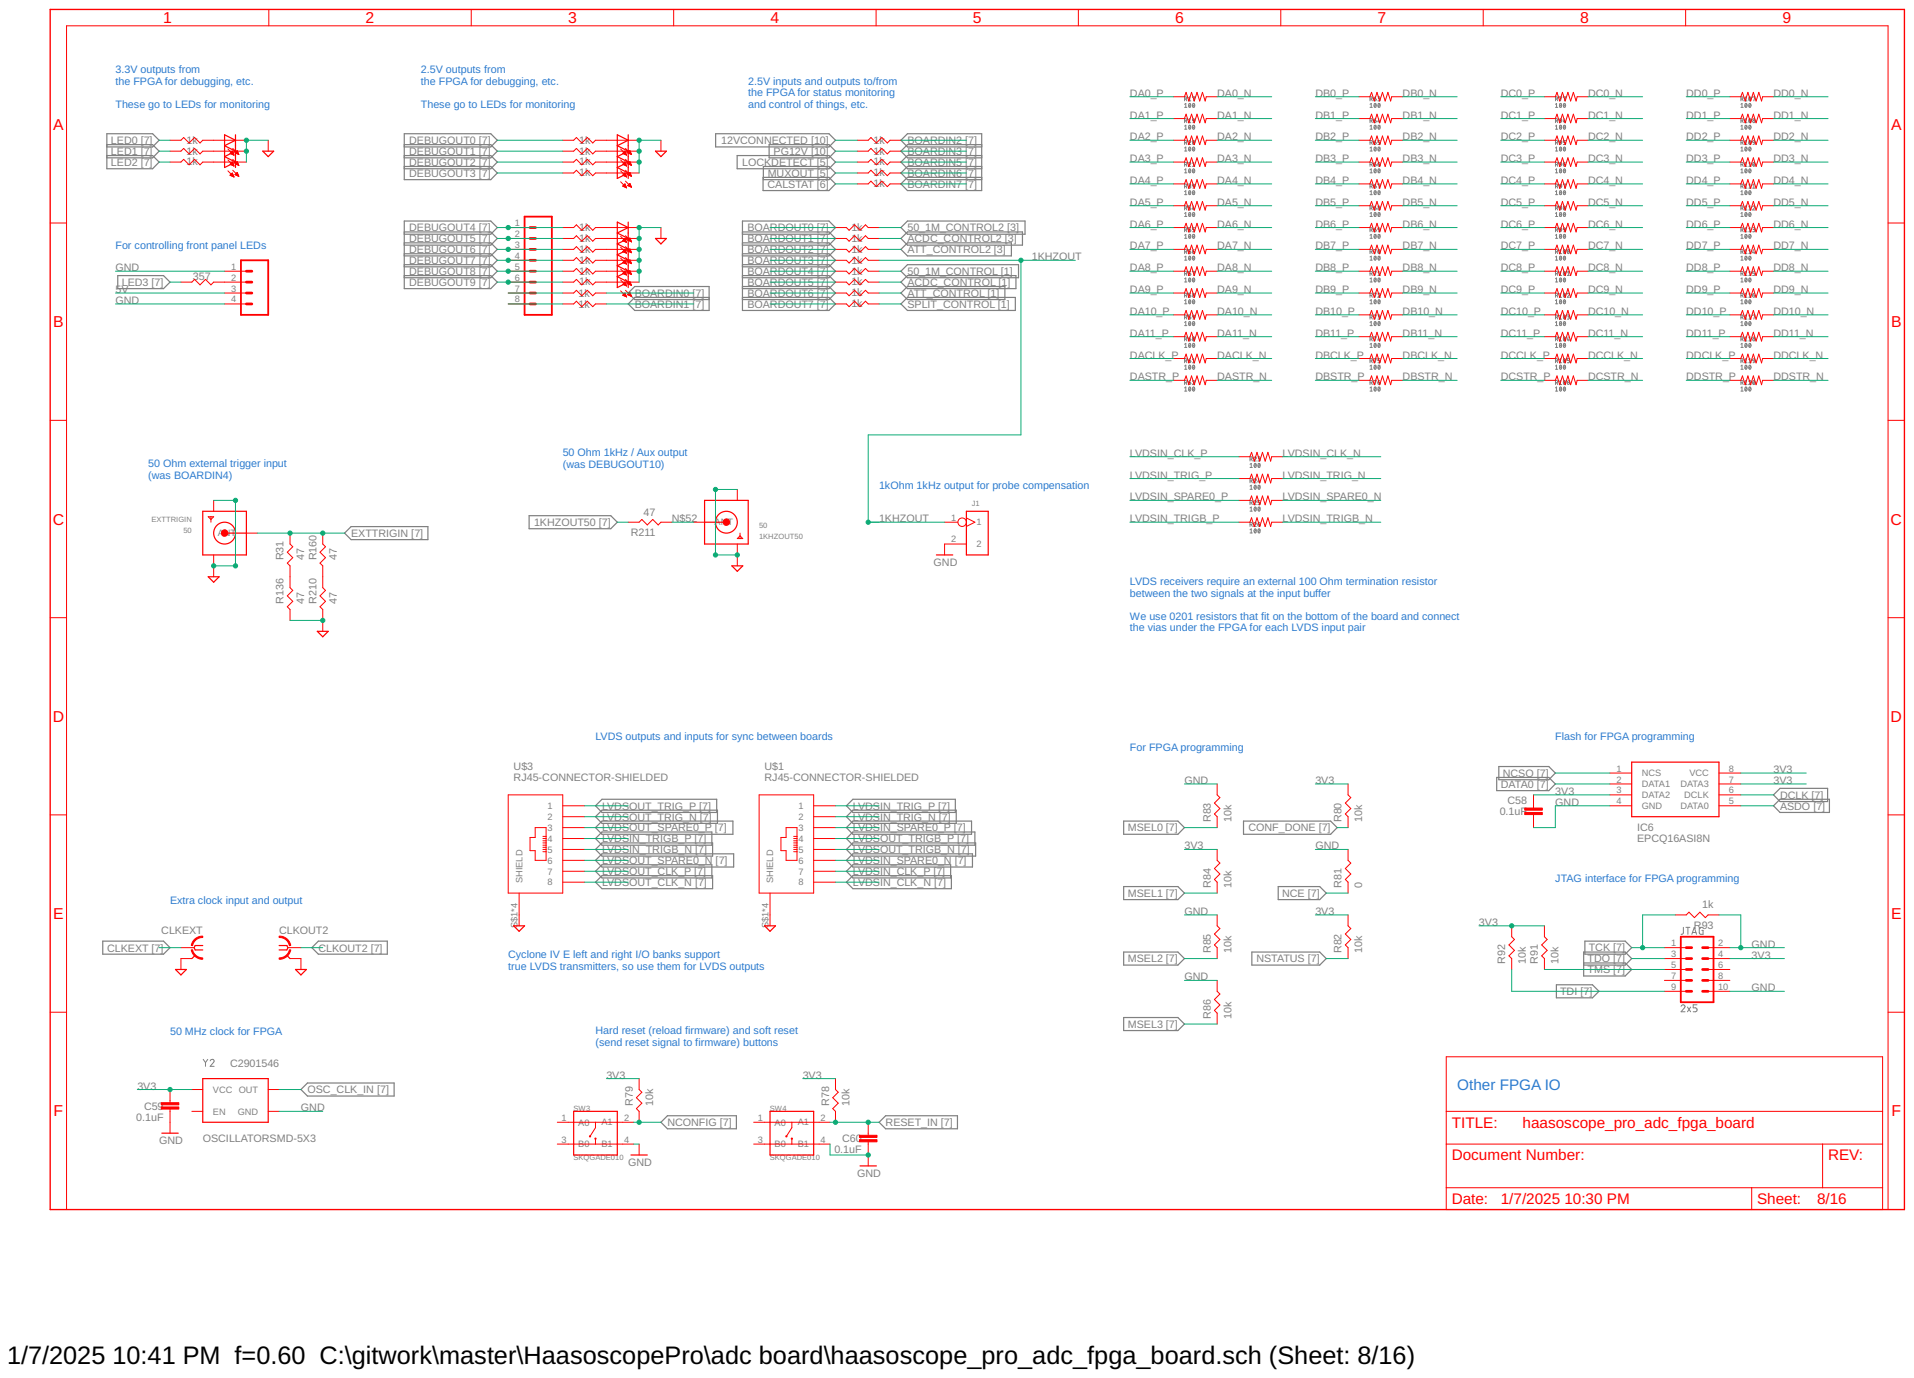
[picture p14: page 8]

3.3V outputs from
the FPGA for debugging, etc. These go to LEDs for monitoring

and control of things, etc. 2.5V outputs from

2.5V inputs and outputs to/from
the FPGA for status monitoring

For controlling front panel LEDs

LVDS receivers require an external 100 Ohm termination resistor between the two signals at the input buffer We use 0201 resistors that fit on the bottom of the board and connect

the vias under the FPGA for each LVDS input pair

LVDS outputs and inputs for sync between boards

Flash for FPGA programming

JTAG interface for FPGA programming

Extra clock input and output

Cyclone IV E left and right I/O banks support
true LVDS transmitters, so use them for LVDS outputs

50 MHz clock for FPGA

Hard reset (reload firmware) and soft reset (send reset signal to firmware) buttons

Date: Sheet: 8/16 | REV: TITLE: Document Number: 1/7/2025 10:30 PM

1/7/2025 10:41 PM f=0.60 C:\gitwork\master\HaasoscopePro\adc board\haasoscope_pro_adc_fpga_board.sch (Sheet: 8/16)

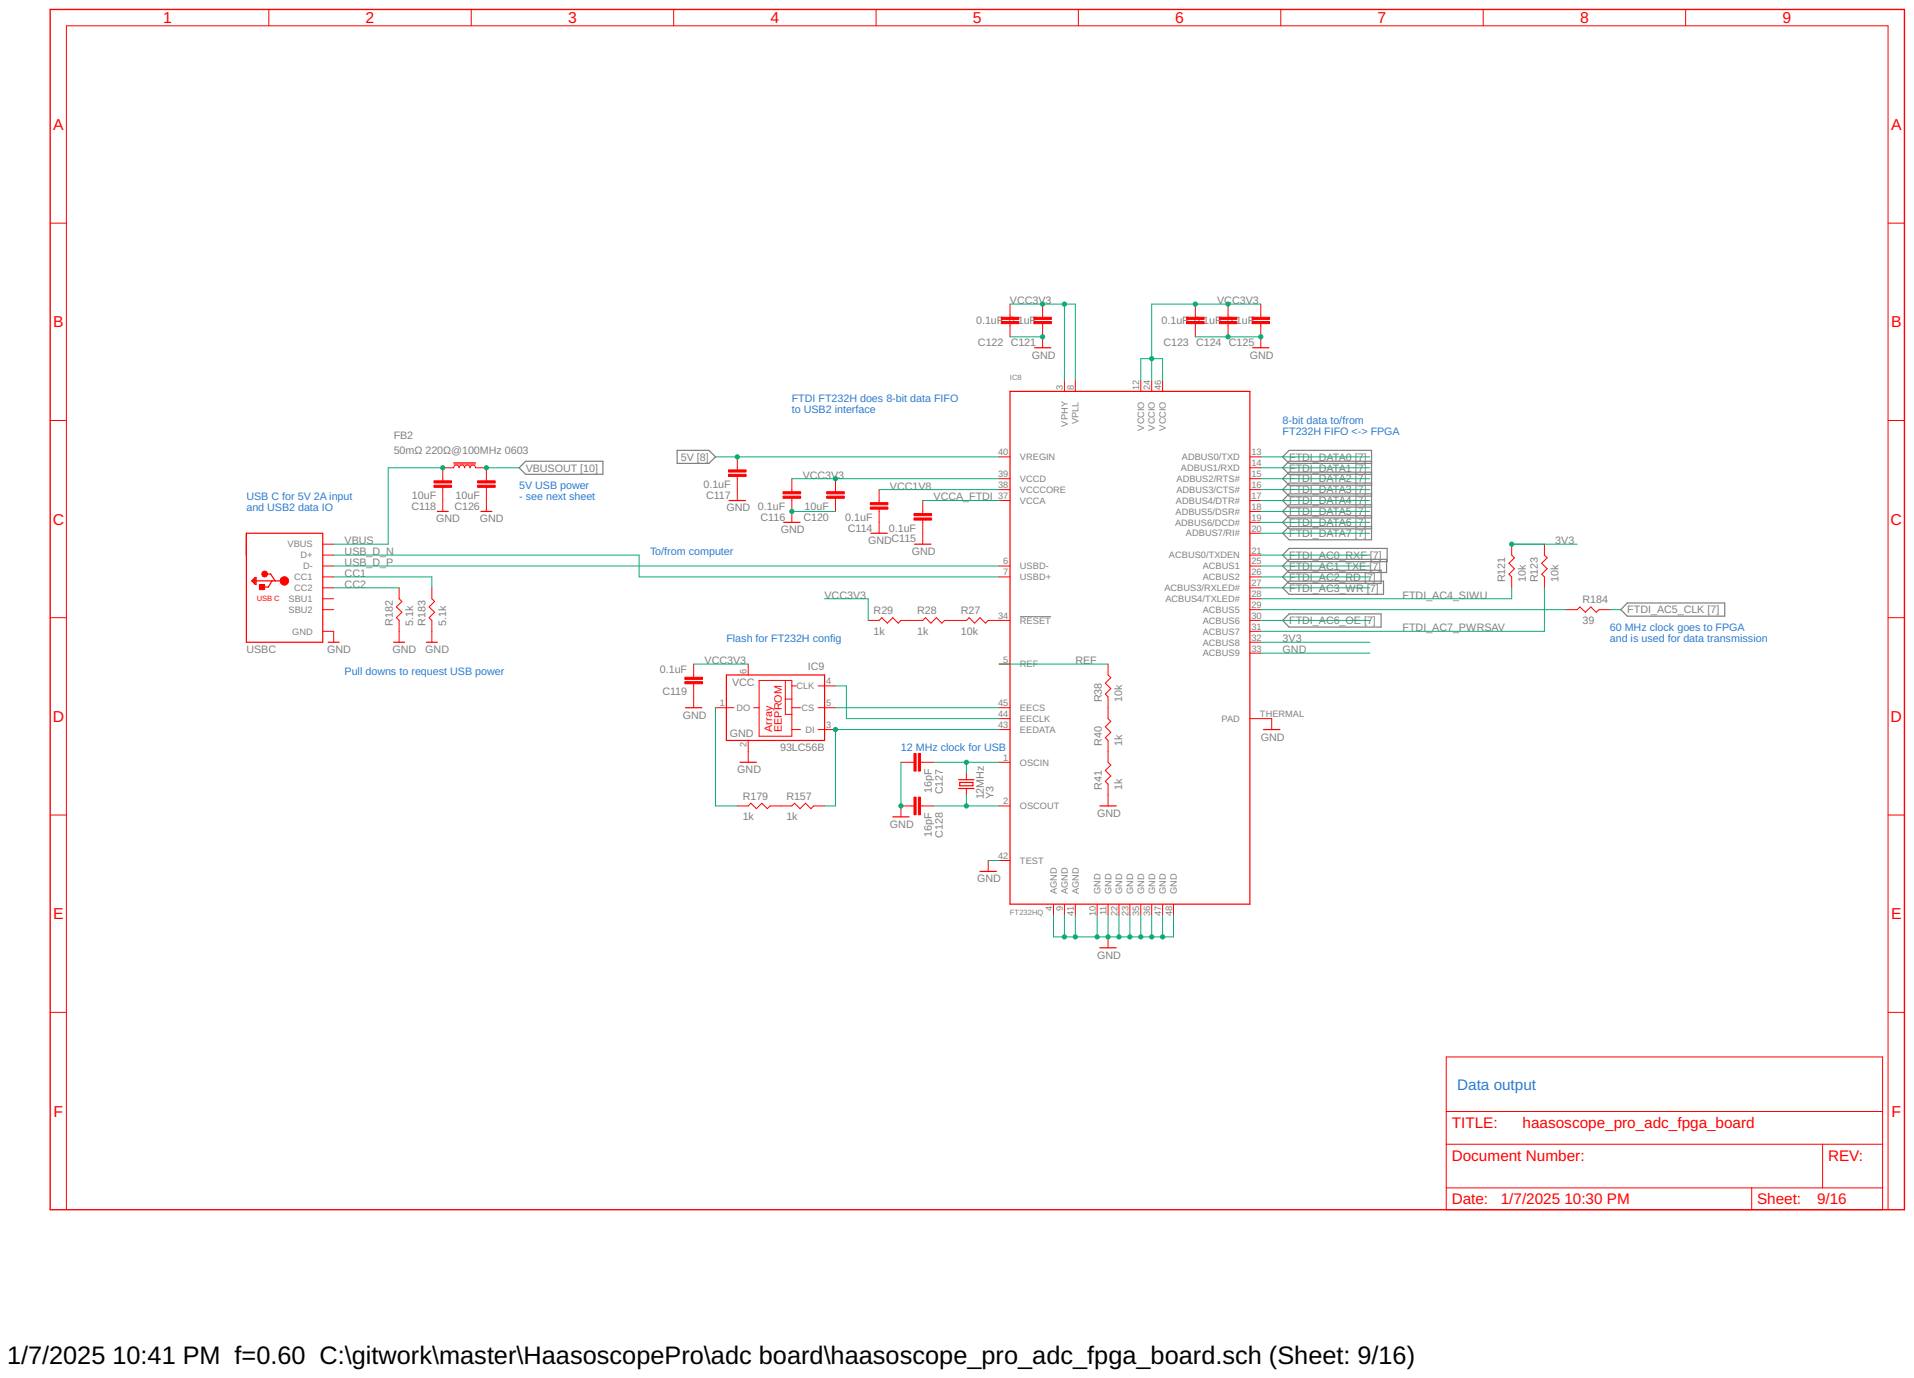
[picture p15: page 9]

FTDI FT232H does 8-bit data FIFO
to USB2 interface

8-bit data to/from
FT232H FIFO <-> FPGA

USB C for 5V 2A input and USB2 data IO

60 MHz clock goes to FPGA
and is used for data transmission

Pull downs to request USB power

12 MHz clock for USB

1/7/2025 10:41 PM f=0.60 C:\gitwork\master\HaasoscopePro\adc board\haasoscope_pro_adc_fpga_board.sch (Sheet: 9/16)

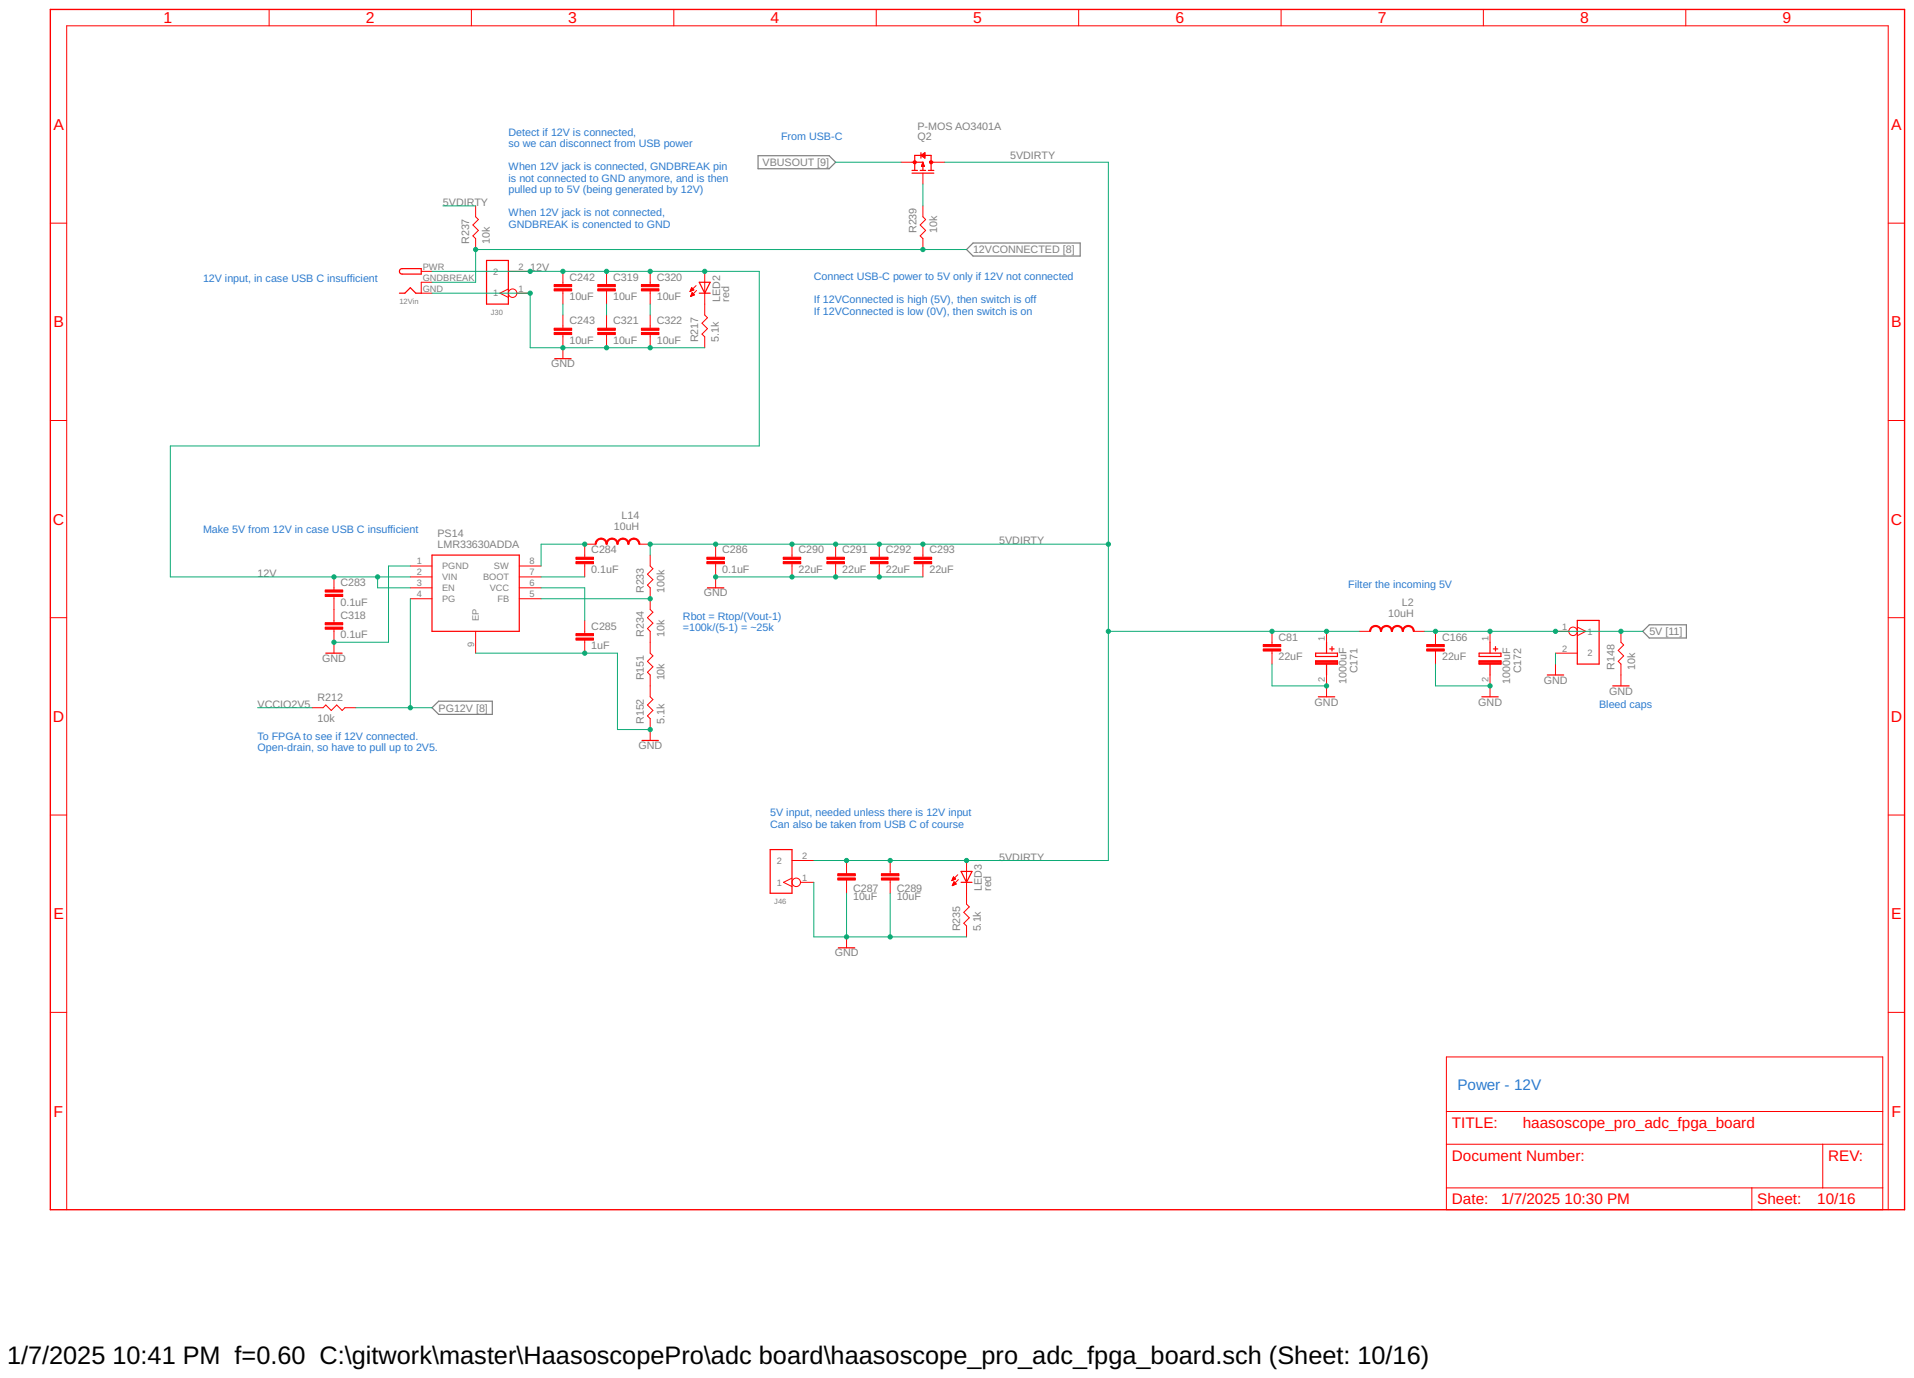
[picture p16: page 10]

Detect if 12V is connected, so we can disconnect from USB power When 12V jack is connected, GNDBREAK pin

is not connected to GND anymore, and is then
pulled up to 5V (being generated by 12V) When 12V jack is not connected, GNDBREAK is conencted to GND
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

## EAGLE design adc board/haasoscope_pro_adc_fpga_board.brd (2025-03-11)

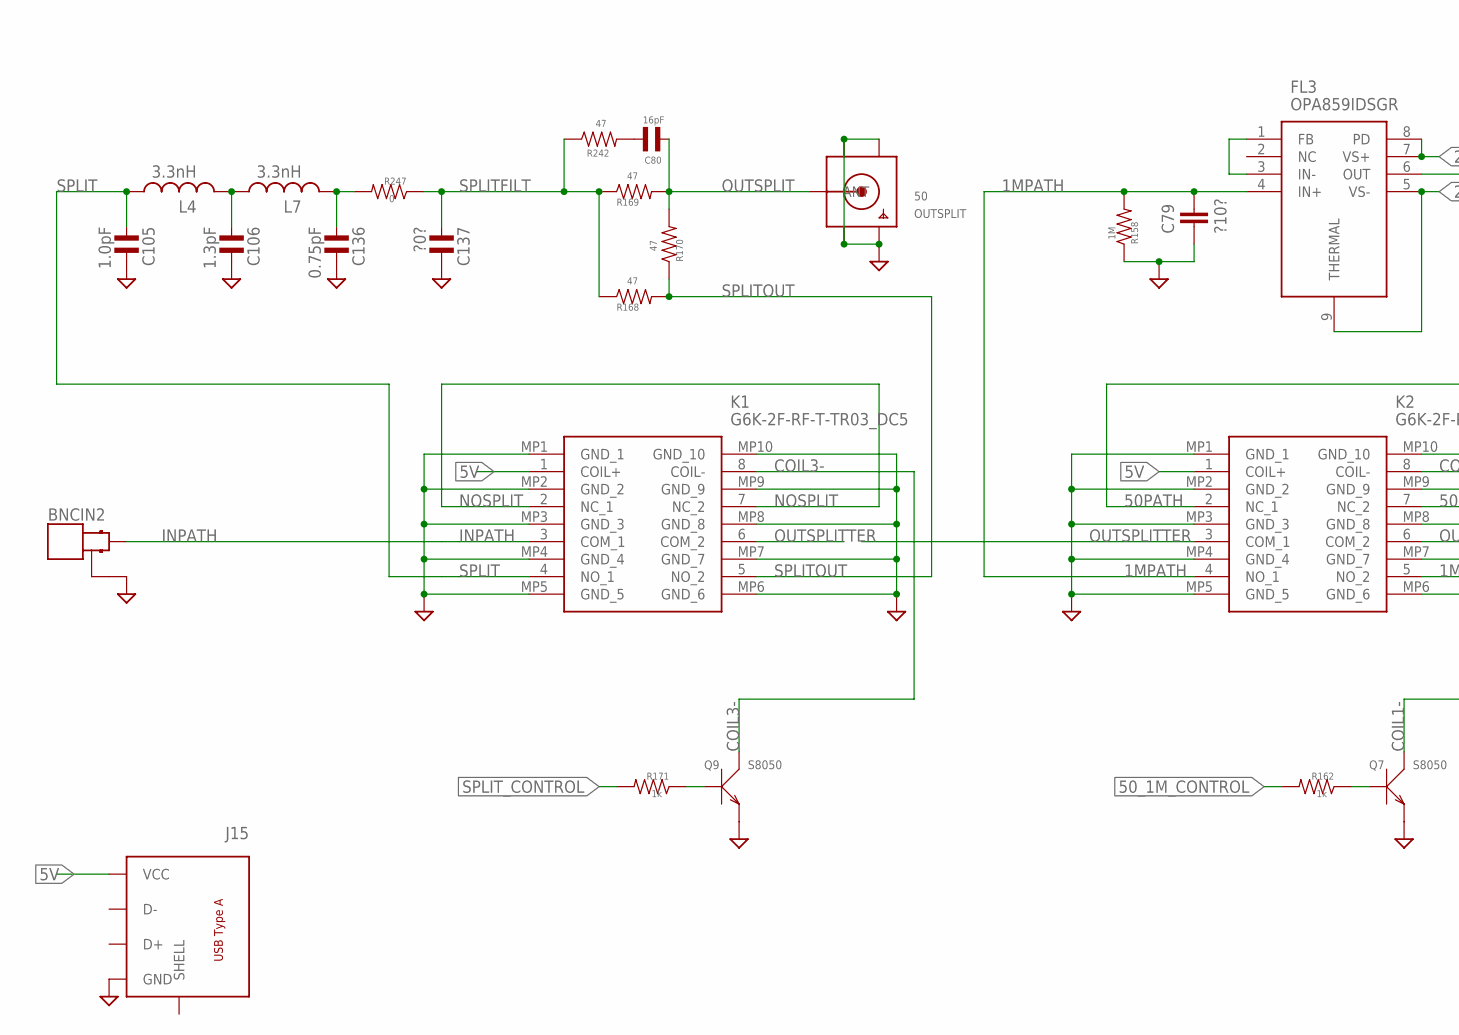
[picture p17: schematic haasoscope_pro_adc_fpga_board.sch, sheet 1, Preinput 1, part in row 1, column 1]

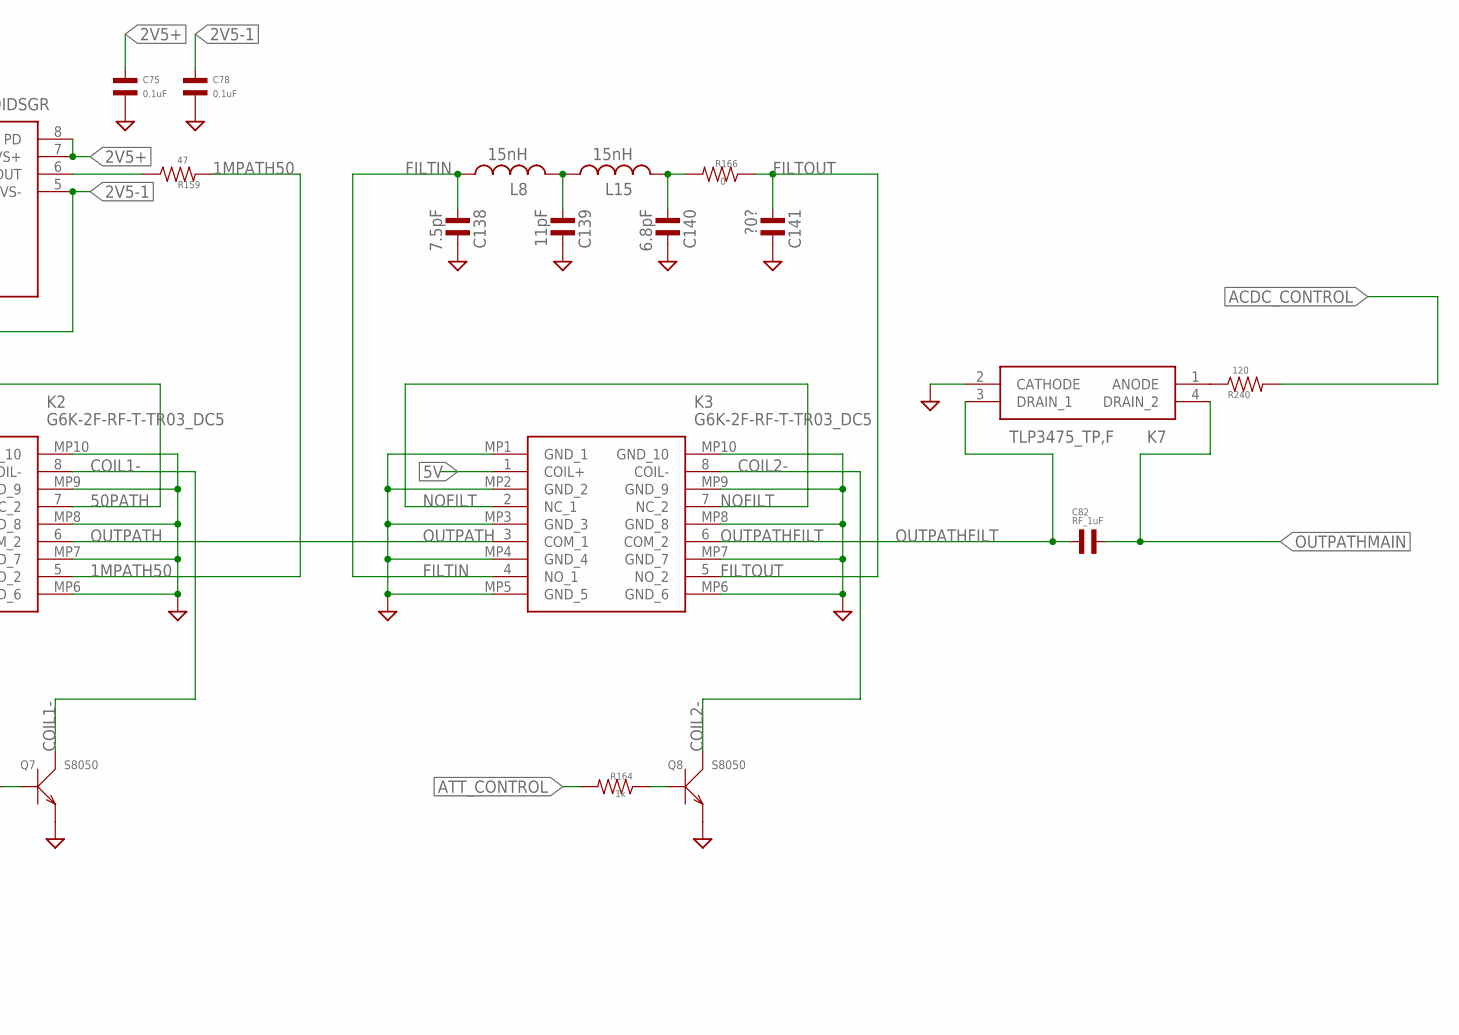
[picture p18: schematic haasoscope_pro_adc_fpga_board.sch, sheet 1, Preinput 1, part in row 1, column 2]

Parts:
BNCIN2: MOLEX_BNC_73100-0105; MOLEX-BNC-73100-0105; MPN 73100-0105
C75, C78: 0.1uF; C0402
C79: ?10?; C0805
C80: 16pF; C0402
C82: RF_1uF; C0402; LCSC C52923
C105: 1.0pF; C0402
C106: 1.3pF; C0402
C136: 0.75pF; C0402
C137, C141: ?0?; C0402
C138: 7.5pF; C0402
C139: 11pF; C0402
C140: 6.8pF; C0402
FL3: OPA859IDSGR; SON50P200X200X80-9N
J15: test1; USB-2.0-A-THT-RA-TE_AMP-292303-1
K1, K2, K3: G6K-2F-RF-T-TR03_DC5; G6K2FRFTTR03DC5
K7: TLP3475_TP,F; TLP3475TPF; MANUFACTURER_PART_NUMBER TLP3475; MOUSER_PART_NUMBER 757-TLP3475
L4, L7: 3.3nH; RESC0402_N; LCSC C162542
L8, L15: 15nH; RESC0402_N; LCSC C521066
OUTSPLIT: 50; SMA_EDGELAUNCH
Q7, Q8, Q9: S8050; SOT-23; LCSC C7420370
R158: 1M; R0402
R159, R168, R169, R170, R242: 47; R0402
R162, R164, R171: 1k; R0402
R166, R247: 0; R0402
R240: 120; R0402

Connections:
1MPATH: C79.2, FL3.4 (IN+), K2.4 (NO_1), R158.P$2
1MPATH50: K2.5 (NO_2), R159.P$2
2V5+: C75.P$1, FL3.7 (VS+), FL3.8 (PD); also elsewhere on the board
2V5-1: C78.P$1, FL3.5 (VS-), FL3.9 (THERMAL); also elsewhere on the board
5V: J15.P$1 (VCC), K1.1 (COIL+), K2.1 (COIL+), K3.1 (COIL+); also elsewhere on the board
50PATH: K2.2 (NC_1), K2.7 (NC_2)
50_1M_CONTROL: R162.P$2; also elsewhere on the board
ACDC_CONTROL: R240.P$2; also elsewhere on the board
ATT_CONTROL: R164.P$2; also elsewhere on the board
COIL1-: K2.8 (COIL-), Q7.3 (C)
COIL2-: K3.8 (COIL-), Q8.3 (C)
COIL3-: K1.8 (COIL-), Q9.3 (C)
FILTIN: C138.P$1, K3.4 (NO_1), L8.1
FILTOUT: C141.P$1, K3.5 (NO_2), R166.P$1
GND: BNCIN2.GND1 (GND), BNCIN2.GND2 (GND), C75.P$2, C78.P$2, C79.1, C105.P$2, C106.P$2, C136.P$2, C137.P$2, C138.P$2, C139.P$2, C140.P$2, C141.P$2, J15.P$4 (GND), K1.MP1 (GND_1), K1.MP2 (GND_2), K1.MP3 (GND_3), K1.MP4 (GND_4), K1.MP5 (GND_5), K1.MP6 (GND_6), K1.MP7 (GND_7), K1.MP8 (GND_8), K1.MP9 (GND_9), K1.MP10 (GND_10), K2.MP1 (GND_1), K2.MP2 (GND_2), K2.MP3 (GND_3), K2.MP4 (GND_4), K2.MP5 (GND_5), K2.MP6 (GND_6), K2.MP7 (GND_7), K2.MP8 (GND_8), K2.MP9 (GND_9), K2.MP10 (GND_10), K3.MP1 (GND_1), K3.MP2 (GND_2), K3.MP3 (GND_3), K3.MP4 (GND_4), K3.MP5 (GND_5), K3.MP6 (GND_6), K3.MP7 (GND_7), K3.MP8 (GND_8), K3.MP9 (GND_9), K3.MP10 (GND_10), K7.2 (CATHODE), OUTSPLIT.GND@1 (GND4), OUTSPLIT.GND@2 (GND3), OUTSPLIT.GND@3 (GND2), OUTSPLIT.GND@4 (GND1), Q7.2 (E), Q8.2 (E), Q9.2 (E), R158.P$1; also elsewhere on the board
INPATH: BNCIN2.SIGNAL, K1.3 (COM_1)
unnamed: C139.P$1, L8.2, L15.1
unnamed: FL3.6 (OUT), R159.P$1
unnamed: FL3.1 (FB), FL3.3 (IN-)
unnamed: Q7.1 (B), R162.P$1
unnamed: Q8.1 (B), R164.P$1
unnamed: Q9.1 (B), R171.P$1
unnamed: K7.1 (ANODE), R240.P$1
unnamed: C80.P$1, R242.P$2
unnamed: C140.P$1, L15.2, R166.P$2
unnamed: C136.P$1, L7.2, R247.P$2
unnamed: C106.P$1, L4.2, L7.1
NOFILT: K3.2 (NC_1), K3.7 (NC_2)
NOSPLIT: K1.2 (NC_1), K1.7 (NC_2)
OUTPATH: K2.6 (COM_2), K3.3 (COM_1)
OUTPATHFILT: C82.P$1, K3.6 (COM_2), K7.3 (DRAIN_1)
OUTPATHMAIN: C82.P$2, K7.4 (DRAIN_2); also elsewhere on the board
OUTSPLIT: C80.P$2, OUTSPLIT.P (ANT), R169.P$2, R170.P$2
OUTSPLITTER: K1.6 (COM_2), K2.3 (COM_1)
SPLIT: C105.P$1, K1.4 (NO_1), L4.1
SPLITFILT: C137.P$1, R168.P$1, R169.P$1, R242.P$1, R247.P$1
SPLITOUT: K1.5 (NO_2), R168.P$2, R170.P$1
SPLIT_CONTROL: R171.P$2; also elsewhere on the board

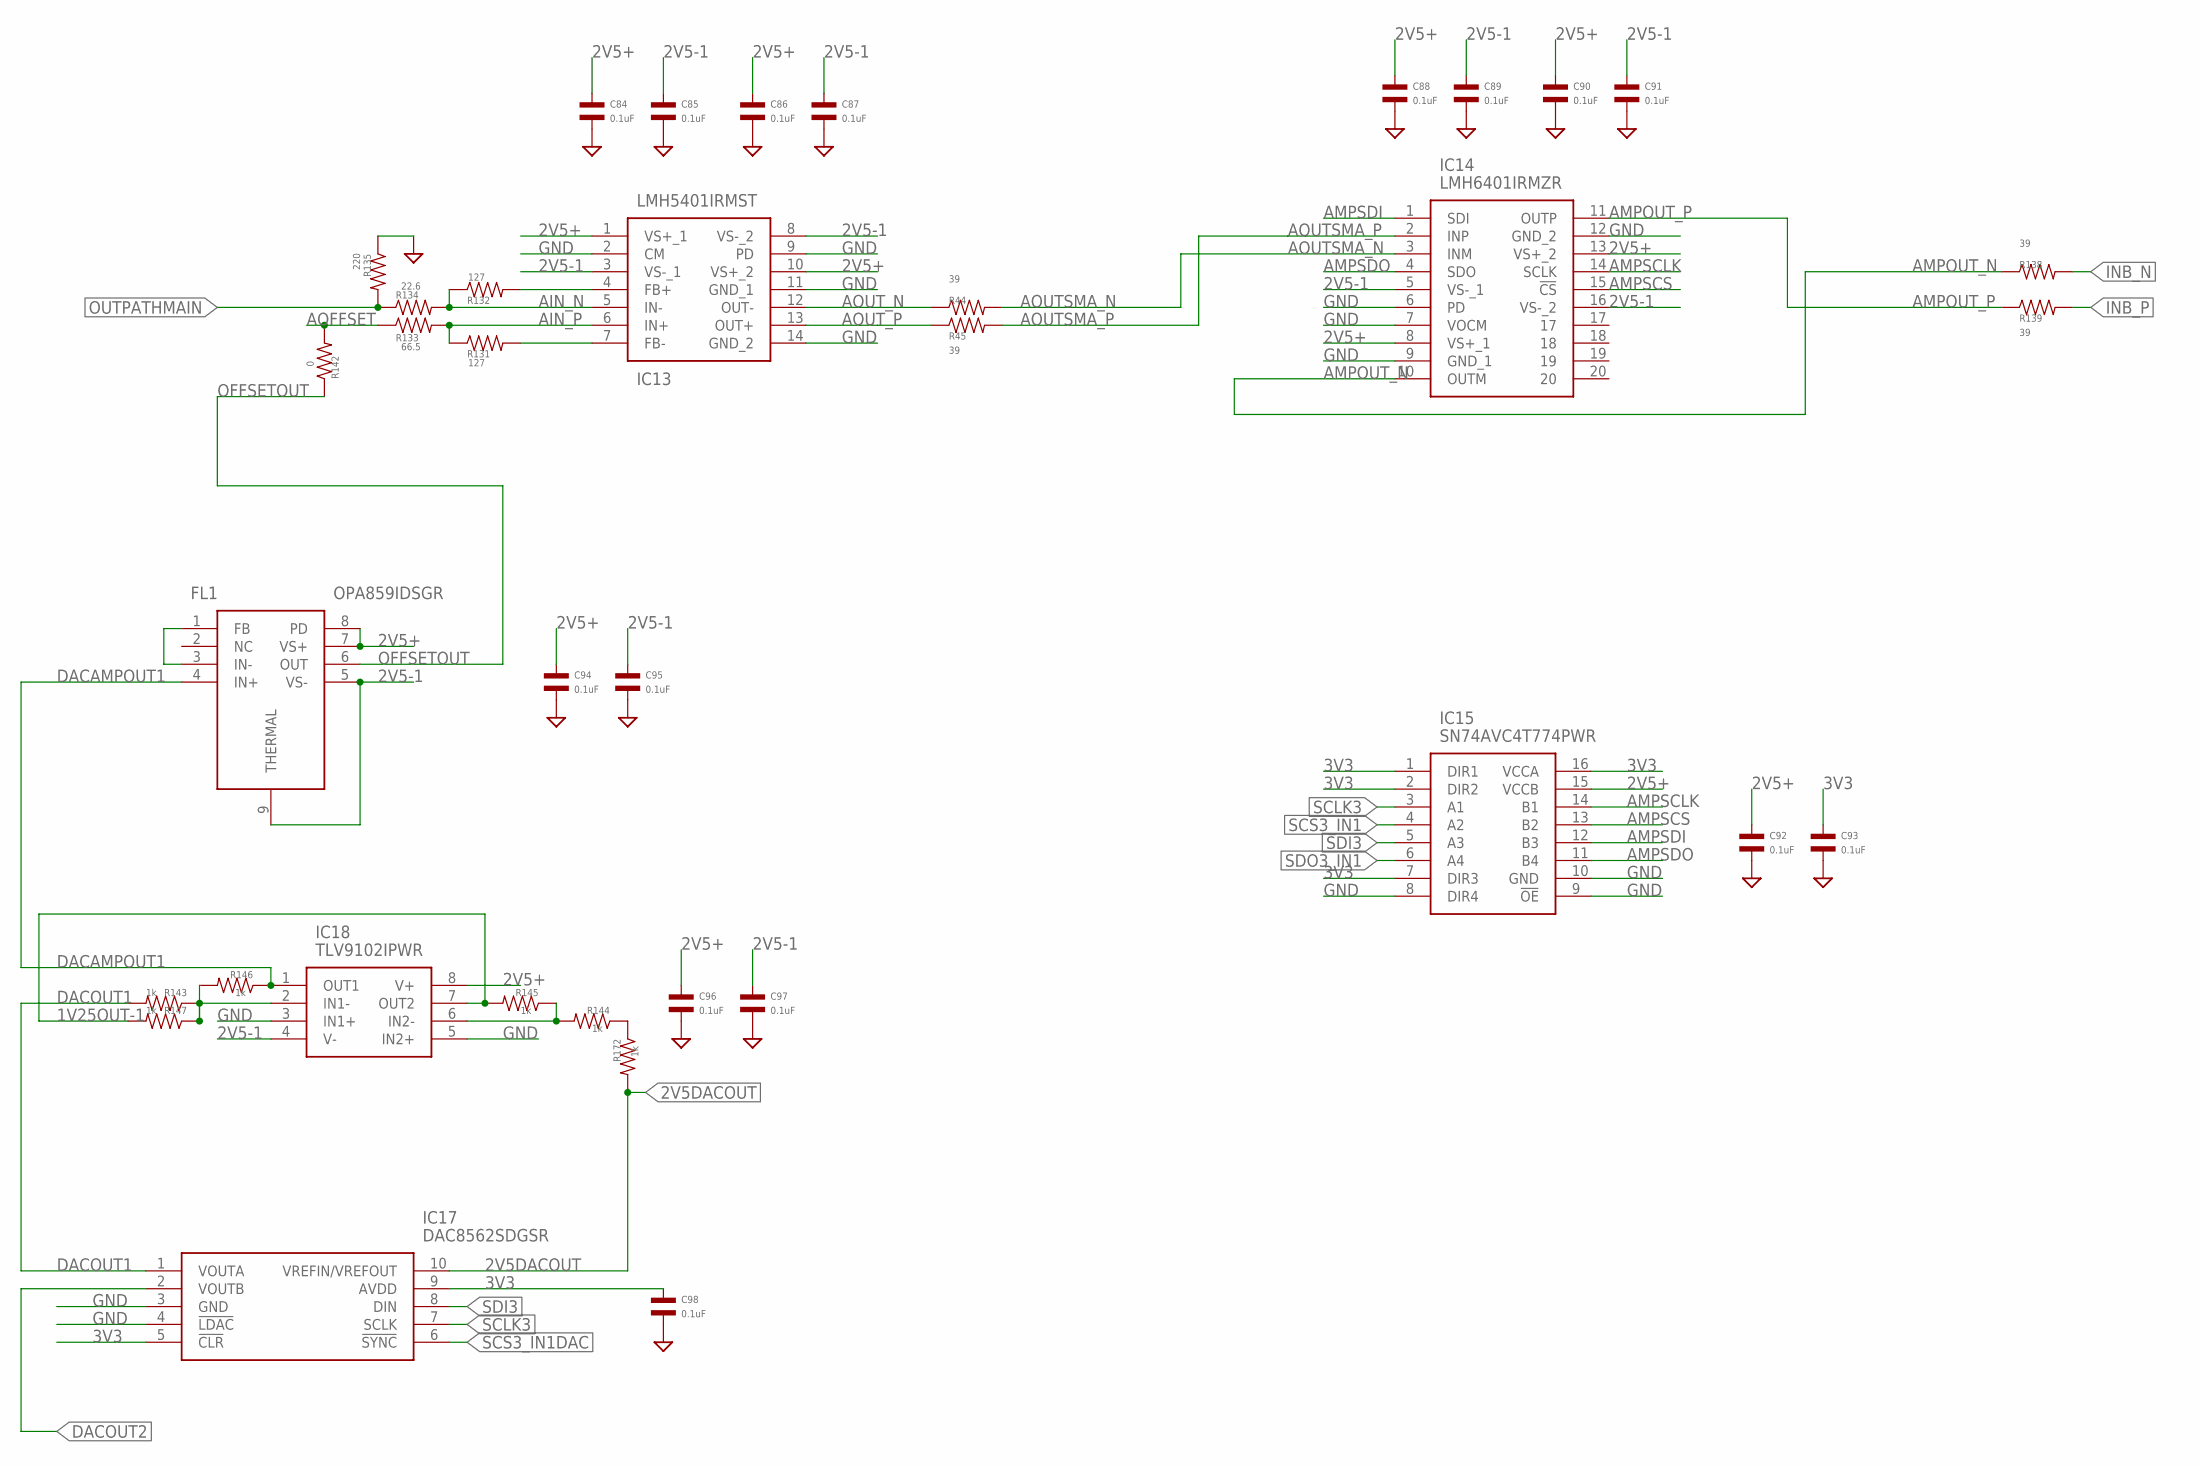
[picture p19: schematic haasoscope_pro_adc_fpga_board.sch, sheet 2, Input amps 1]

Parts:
C84, C85, C86, C87, C88, C89, C90, C91, C92, C93, C94, C95, C96, C97, C98: 0.1uF; C0402
FL1: OPA859IDSGR; SON50P200X200X80-9N
IC13: LMH5401IRMST; LMH5401IRMSR
IC14: LMH6401IRMZR
IC15: SN74AVC4T774PWR; SOP65P640X120-16N
IC17: DAC8562SDGSR; SOP50P490X110-10N
IC18: TLV9102IPWR; SOP65P640X120-8N
R44, R45, R138, R139: 39; R0402
R131, R132: 127; R0402
R133: 66.5; R0402
R134: 22.6; R0402
R135: 220; R0402
R142: 0; R0402
R143, R144, R145, R146, R147, R172: 1k; R0402

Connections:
1V25OUT-1: IC18.7 (OUT2), R145.P$2, R147.P$2
2V5+: C84.P$1, C86.P$1, C88.P$1, C90.P$1, C92.P$1, C94.P$1, C96.P$1, FL1.7 (VS+), FL1.8 (PD), IC13.1 (VS+_1), IC13.10 (VS+_2), IC14.8 (VS+_1), IC14.13 (VS+_2), IC15.15 (VCCB), IC18.8 (V+); also elsewhere on the board
2V5-1: C85.P$1, C87.P$1, C89.P$1, C91.P$1, C95.P$1, C97.P$1, FL1.5 (VS-), FL1.9 (THERMAL), IC13.3 (VS-_1), IC13.8 (VS-_2), IC14.5 (VS-_1), IC14.16 (VS-_2), IC18.4 (V-); also elsewhere on the board
2V5DACOUT: IC17.10 (VREFIN/VREFOUT), R172.P$2; also elsewhere on the board
3V3: C93.P$1, C98.P$1, IC15.1 (DIR1), IC15.2 (DIR2), IC15.7 (DIR3), IC15.16 (VCCA), IC17.5 (!CLR), IC17.9 (AVDD); also elsewhere on the board
AIN_N: IC13.5 (IN-), R132.P$1, R134.P$2
AIN_P: IC13.6 (IN+), R131.P$1, R133.P$2
AMPOUT_N: IC14.10 (OUTM), R138.P$1
AMPOUT_P: IC14.11 (OUTP), R139.P$1
AMPSCLK: IC14.14 (SCLK), IC15.14 (B1)
AMPSCS: IC14.15 (!CS), IC15.13 (B2)
AMPSDI: IC14.1 (SDI), IC15.12 (B3)
AMPSDO: IC14.4 (SDO), IC15.11 (B4)
AOFFSET: R133.P$1, R142.P$2
AOUTSMA_N: IC14.3 (INM), R44.P$2
AOUTSMA_P: IC14.2 (INP), R45.P$2
AOUT_N: IC13.12 (OUT-), R44.P$1
AOUT_P: IC13.13 (OUT+), R45.P$1
DACAMPOUT1: FL1.4 (IN+), IC18.1 (OUT1), R146.P$1
DACOUT1: IC17.1 (VOUTA), R143.P$2
DACOUT2: IC17.2 (VOUTB); also elsewhere on the board
GND: C84.P$2, C85.P$2, C86.P$2, C87.P$2, C88.P$2, C89.P$2, C90.P$2, C91.P$2, C92.P$2, C93.P$2, C94.P$2, C95.P$2, C96.P$2, C97.P$2, C98.P$2, IC13.2 (CM), IC13.9 (PD), IC13.11 (GND_1), IC13.14 (GND_2), IC14.6 (PD), IC14.7 (VOCM), IC14.9 (GND_1), IC14.12 (GND_2), IC15.8 (DIR4), IC15.9 (!OE), IC15.10 (GND), IC17.3 (GND), IC17.4 (!LDAC), IC18.3 (IN1+), IC18.5 (IN2+), R135.P$1; also elsewhere on the board
INB_N: R138.P$2; also elsewhere on the board
INB_P: R139.P$2; also elsewhere on the board
unnamed: FL1.1 (FB), FL1.3 (IN-)
unnamed: IC13.7 (FB-), R131.P$2
unnamed: IC13.4 (FB+), R132.P$2
unnamed: IC18.6 (IN2-), R144.P$2, R145.P$1
unnamed: IC18.2 (IN1-), R143.P$1, R146.P$2, R147.P$1
unnamed: R144.P$1, R172.P$1
OFFSETOUT: FL1.6 (OUT), R142.P$1
OUTPATHMAIN: R134.P$1, R135.P$2; also elsewhere on the board
SCLK3: IC15.3 (A1), IC17.7 (SCLK); also elsewhere on the board
SCS3_IN1: IC15.4 (A2); also elsewhere on the board
SCS3_IN1DAC: IC17.6 (!SYNC); also elsewhere on the board
SDI3: IC15.5 (A3), IC17.8 (DIN); also elsewhere on the board
SDO3_IN1: IC15.6 (A4); also elsewhere on the board

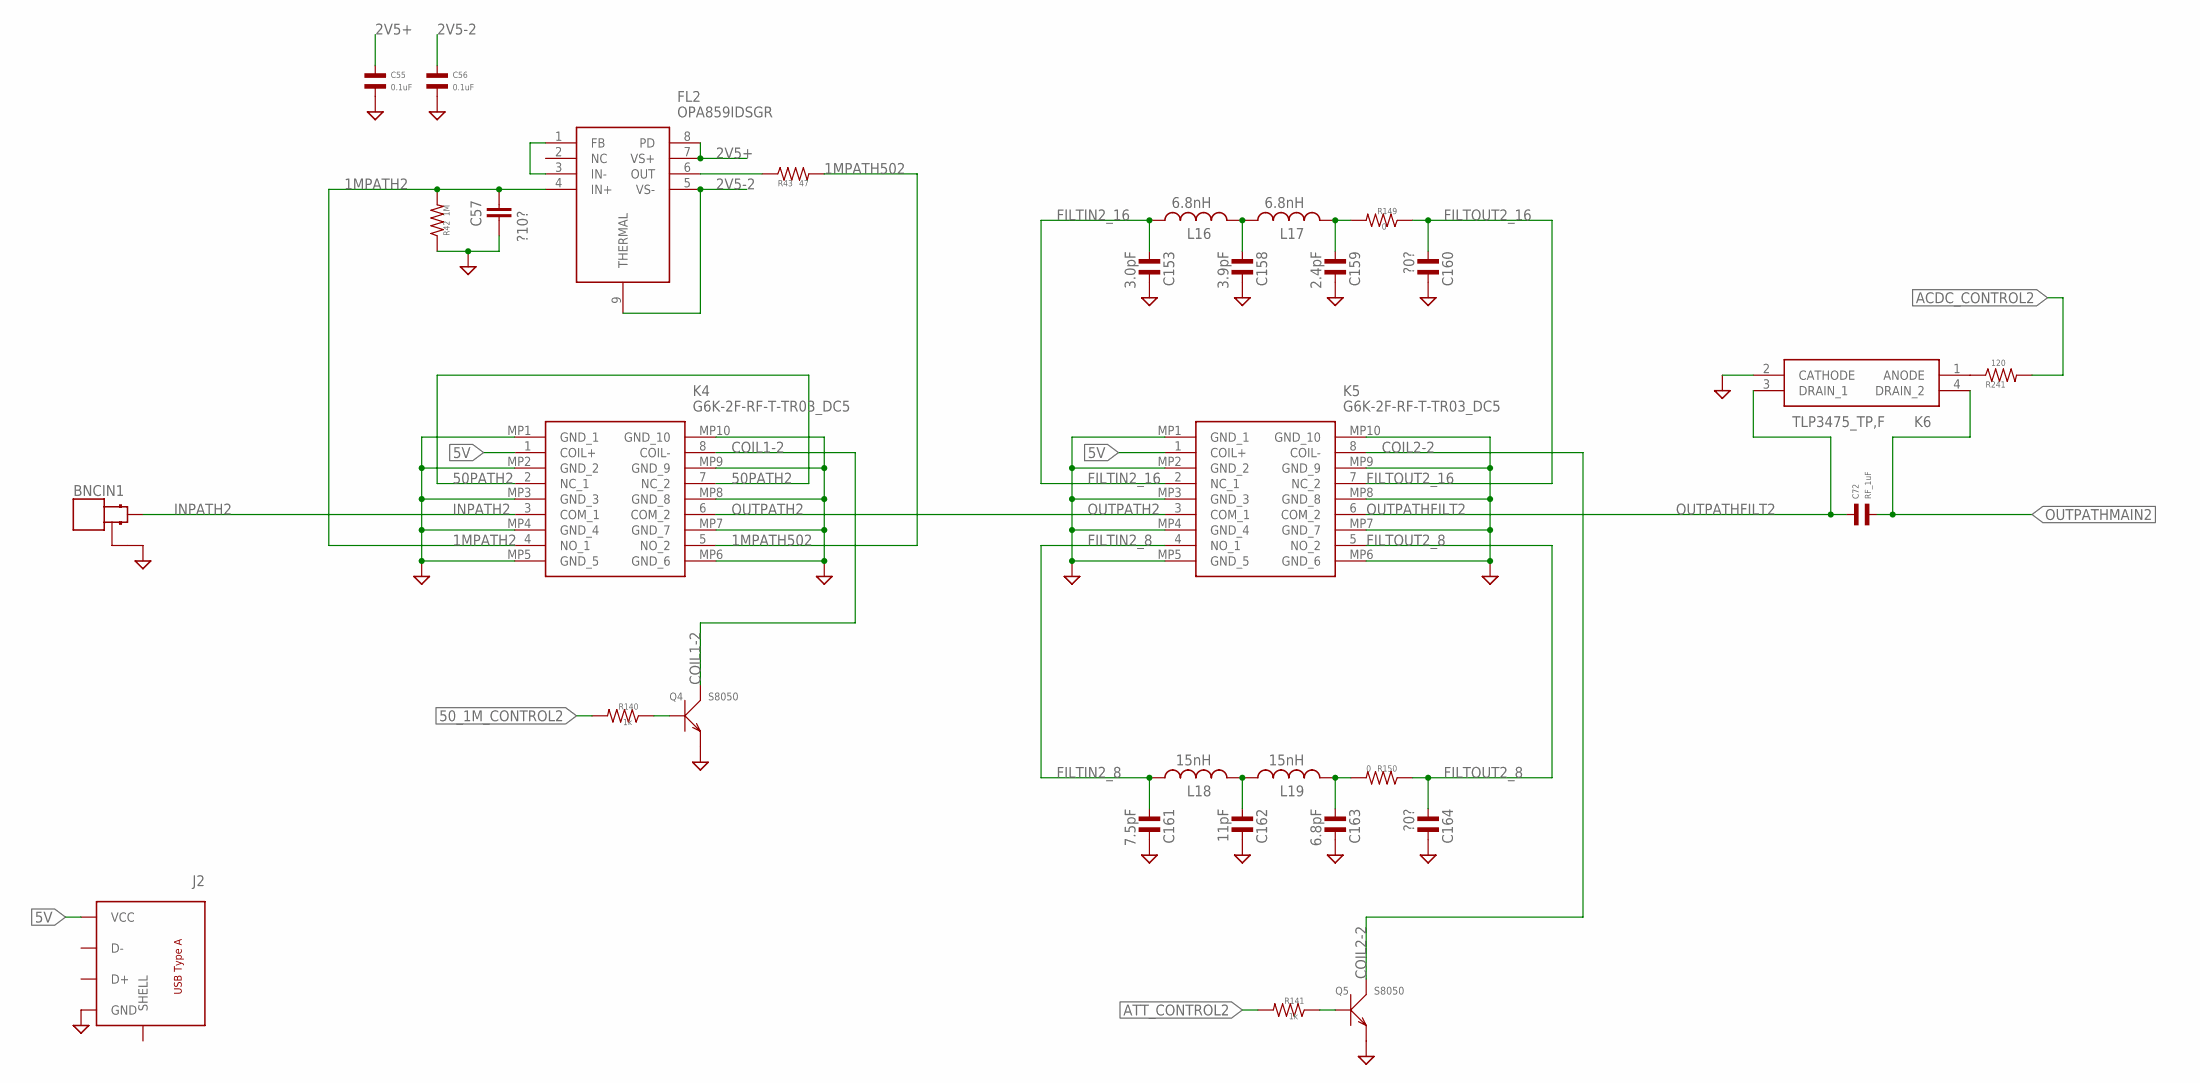
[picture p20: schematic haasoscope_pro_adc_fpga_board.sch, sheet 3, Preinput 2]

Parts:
BNCIN1: MOLEX_BNC_73100-0105; MOLEX-BNC-73100-0105; MPN 73100-0105
C55, C56: 0.1uF; C0402
C57: ?10?; C0805
C72: RF_1uF; C0402; LCSC C52923
C153: 3.0pF; C0402
C158: 3.9pF; C0402
C159: 2.4pF; C0402
C160, C164: ?0?; C0402
C161: 7.5pF; C0402
C162: 11pF; C0402
C163: 6.8pF; C0402
FL2: OPA859IDSGR; SON50P200X200X80-9N
J2: test1; USB-2.0-A-THT-RA-TE_AMP-292303-1
K4, K5: G6K-2F-RF-T-TR03_DC5; G6K2FRFTTR03DC5
K6: TLP3475_TP,F; TLP3475TPF; MANUFACTURER_PART_NUMBER TLP3475; MOUSER_PART_NUMBER 757-TLP3475
L16, L17: 6.8nH; RESC0402_N; LCSC C77110
L18, L19: 15nH; RESC0402_N; LCSC C521066
Q4, Q5: S8050; SOT-23; LCSC C7420370
R42: 1M; R0402
R43: 47; R0402
R140, R141: 1k; R0402
R149, R150: 0; R0402
R241: 120; R0402

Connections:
1MPATH2: C57.2, FL2.4 (IN+), K4.4 (NO_1), R42.P$2
1MPATH502: K4.5 (NO_2), R43.P$2
2V5+: C55.P$1, FL2.7 (VS+), FL2.8 (PD); also elsewhere on the board
2V5-2: C56.P$1, FL2.5 (VS-), FL2.9 (THERMAL); also elsewhere on the board
5V: J2.P$1 (VCC), K4.1 (COIL+), K5.1 (COIL+); also elsewhere on the board
50PATH2: K4.2 (NC_1), K4.7 (NC_2)
50_1M_CONTROL2: R140.P$2; also elsewhere on the board
ACDC_CONTROL2: R241.P$2; also elsewhere on the board
ATT_CONTROL2: R141.P$2; also elsewhere on the board
COIL1-2: K4.8 (COIL-), Q4.3 (C)
COIL2-2: K5.8 (COIL-), Q5.3 (C)
FILTIN2_8: C161.P$1, K5.4 (NO_1), L18.1
FILTIN2_16: C153.P$1, K5.2 (NC_1), L16.1
FILTOUT2_8: C164.P$1, K5.5 (NO_2), R150.P$1
FILTOUT2_16: C160.P$1, K5.7 (NC_2), R149.P$1
GND: BNCIN1.GND1 (GND), BNCIN1.GND2 (GND), C55.P$2, C56.P$2, C57.1, C153.P$2, C158.P$2, C159.P$2, C160.P$2, C161.P$2, C162.P$2, C163.P$2, C164.P$2, J2.P$4 (GND), K4.MP1 (GND_1), K4.MP2 (GND_2), K4.MP3 (GND_3), K4.MP4 (GND_4), K4.MP5 (GND_5), K4.MP6 (GND_6), K4.MP7 (GND_7), K4.MP8 (GND_8), K4.MP9 (GND_9), K4.MP10 (GND_10), K5.MP1 (GND_1), K5.MP2 (GND_2), K5.MP3 (GND_3), K5.MP4 (GND_4), K5.MP5 (GND_5), K5.MP6 (GND_6), K5.MP7 (GND_7), K5.MP8 (GND_8), K5.MP9 (GND_9), K5.MP10 (GND_10), K6.2 (CATHODE), Q4.2 (E), Q5.2 (E), R42.P$1; also elsewhere on the board
INPATH2: BNCIN1.SIGNAL, K4.3 (COM_1)
unnamed: FL2.6 (OUT), R43.P$1
unnamed: FL2.1 (FB), FL2.3 (IN-)
unnamed: Q4.1 (B), R140.P$1
unnamed: Q5.1 (B), R141.P$1
unnamed: K6.1 (ANODE), R241.P$1
unnamed: C158.P$1, L16.2, L17.1
unnamed: C159.P$1, L17.2, R149.P$2
unnamed: C162.P$1, L18.2, L19.1
unnamed: C163.P$1, L19.2, R150.P$2
OUTPATH2: K4.6 (COM_2), K5.3 (COM_1)
OUTPATHFILT2: C72.P$1, K5.6 (COM_2), K6.3 (DRAIN_1)
OUTPATHMAIN2: C72.P$2, K6.4 (DRAIN_2); also elsewhere on the board

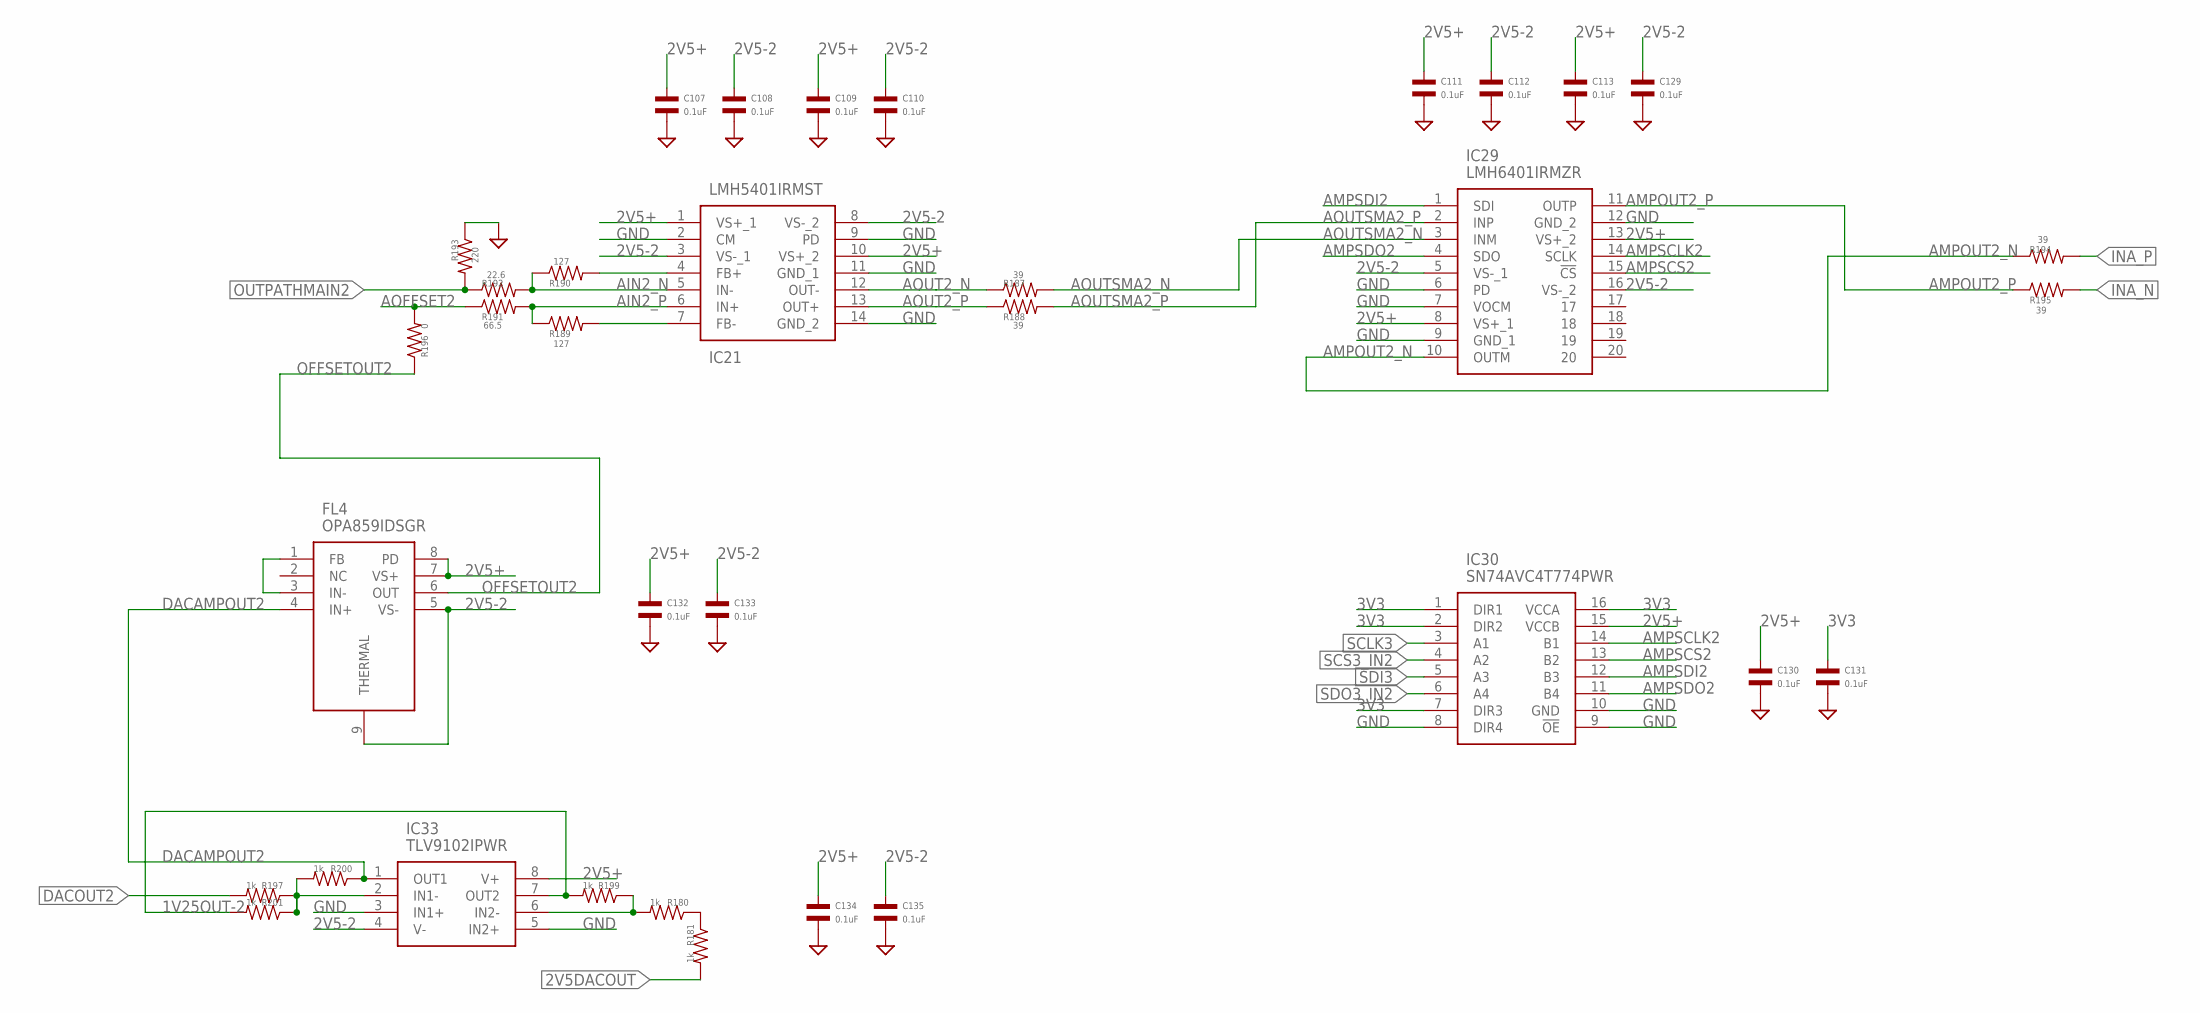
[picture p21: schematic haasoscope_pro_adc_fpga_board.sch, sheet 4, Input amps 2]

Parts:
C107, C108, C109, C110, C111, C112, C113, C129, C130, C131, C132, C133, C134, C135: 0.1uF; C0402
FL4: OPA859IDSGR; SON50P200X200X80-9N
IC21: LMH5401IRMST; LMH5401IRMSR
IC29: LMH6401IRMZR
IC30: SN74AVC4T774PWR; SOP65P640X120-16N
IC33: TLV9102IPWR; SOP65P640X120-8N
R180, R181, R197, R199, R200, R201: 1k; R0402
R187, R188, R194, R195: 39; R0402
R189, R190: 127; R0402
R191: 66.5; R0402
R192: 22.6; R0402
R193: 220; R0402
R196: 0; R0402

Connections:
1V25OUT-2: IC33.7 (OUT2), R199.P$2, R201.P$2
2V5+: C107.P$1, C109.P$1, C111.P$1, C113.P$1, C130.P$1, C132.P$1, C134.P$1, FL4.7 (VS+), FL4.8 (PD), IC21.1 (VS+_1), IC21.10 (VS+_2), IC29.8 (VS+_1), IC29.13 (VS+_2), IC30.15 (VCCB), IC33.8 (V+); also elsewhere on the board
2V5-2: C108.P$1, C110.P$1, C112.P$1, C129.P$1, C133.P$1, C135.P$1, FL4.5 (VS-), FL4.9 (THERMAL), IC21.3 (VS-_1), IC21.8 (VS-_2), IC29.5 (VS-_1), IC29.16 (VS-_2), IC33.4 (V-); also elsewhere on the board
2V5DACOUT: R181.P$2; also elsewhere on the board
3V3: C131.P$1, IC30.1 (DIR1), IC30.2 (DIR2), IC30.7 (DIR3), IC30.16 (VCCA); also elsewhere on the board
AIN2_N: IC21.5 (IN-), R190.P$1, R192.P$2
AIN2_P: IC21.6 (IN+), R189.P$1, R191.P$2
AMPOUT2_N: IC29.10 (OUTM), R194.P$1
AMPOUT2_P: IC29.11 (OUTP), R195.P$1
AMPSCLK2: IC29.14 (SCLK), IC30.14 (B1)
AMPSCS2: IC29.15 (!CS), IC30.13 (B2)
AMPSDI2: IC29.1 (SDI), IC30.12 (B3)
AMPSDO2: IC29.4 (SDO), IC30.11 (B4)
AOFFSET2: R191.P$1, R196.P$2
AOUT2_N: IC21.12 (OUT-), R187.P$1
AOUT2_P: IC21.13 (OUT+), R188.P$1
AOUTSMA2_N: IC29.3 (INM), R187.P$2
AOUTSMA2_P: IC29.2 (INP), R188.P$2
DACAMPOUT2: FL4.4 (IN+), IC33.1 (OUT1), R200.P$1
DACOUT2: R197.P$2; also elsewhere on the board
GND: C107.P$2, C108.P$2, C109.P$2, C110.P$2, C111.P$2, C112.P$2, C113.P$2, C129.P$2, C130.P$2, C131.P$2, C132.P$2, C133.P$2, C134.P$2, C135.P$2, IC21.2 (CM), IC21.9 (PD), IC21.11 (GND_1), IC21.14 (GND_2), IC29.6 (PD), IC29.7 (VOCM), IC29.9 (GND_1), IC29.12 (GND_2), IC30.8 (DIR4), IC30.9 (!OE), IC30.10 (GND), IC33.3 (IN1+), IC33.5 (IN2+), R193.P$1; also elsewhere on the board
INA_N: R195.P$2; also elsewhere on the board
INA_P: R194.P$2; also elsewhere on the board
unnamed: FL4.1 (FB), FL4.3 (IN-)
unnamed: IC21.7 (FB-), R189.P$2
unnamed: IC21.4 (FB+), R190.P$2
unnamed: IC33.6 (IN2-), R180.P$2, R199.P$1
unnamed: IC33.2 (IN1-), R197.P$1, R200.P$2, R201.P$1
unnamed: R180.P$1, R181.P$1
OFFSETOUT2: FL4.6 (OUT), R196.P$1
OUTPATHMAIN2: R192.P$1, R193.P$2; also elsewhere on the board
SCLK3: IC30.3 (A1); also elsewhere on the board
SCS3_IN2: IC30.4 (A2); also elsewhere on the board
SDI3: IC30.5 (A3); also elsewhere on the board
SDO3_IN2: IC30.6 (A4); also elsewhere on the board

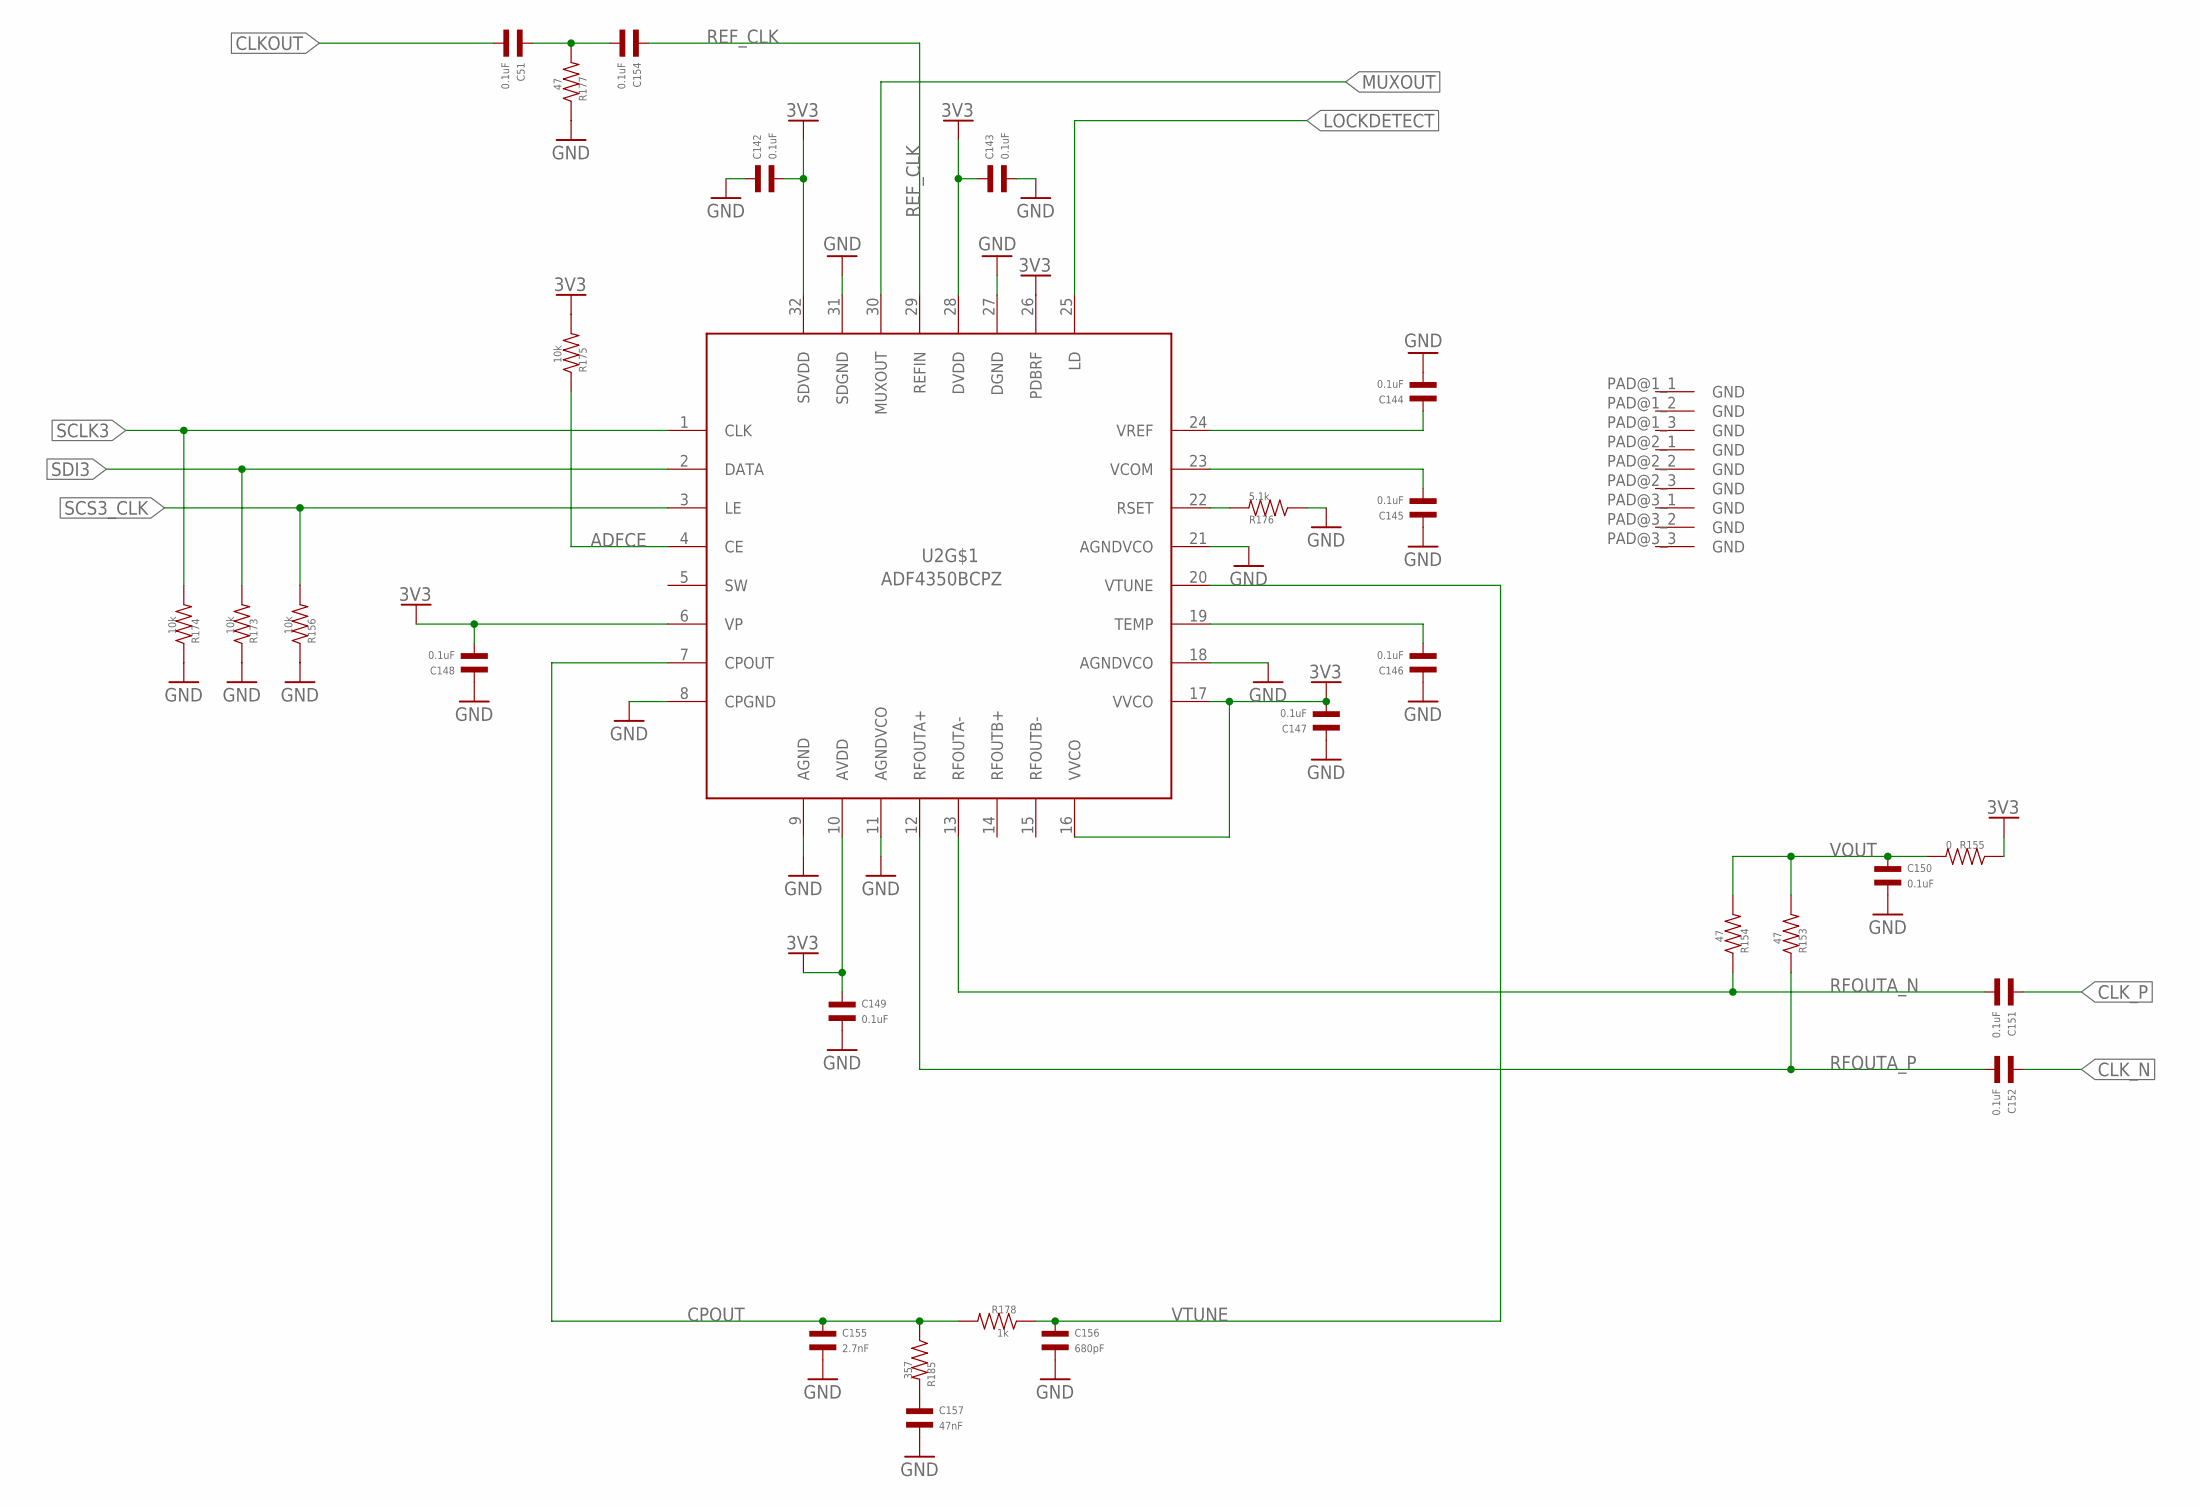
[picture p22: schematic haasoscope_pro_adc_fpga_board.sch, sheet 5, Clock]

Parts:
C51, C142, C143, C144, C145, C146, C147, C148, C149, C150, C151, C152, C154: 0.1uF; C0402
C155: 2.7nF; C0402
C156: 680pF; C0402
C157: 47nF; C0402
R153, R154, R177: 47; R0402
R155: 0; R0402
R156, R173, R174, R175: 10k; R0402
R176: 5.1k; R0402
R178: 1k; R0402
R185: 357; R0402
U2: ADF4350BCPZ; QFN50P500X500X100-33V2N

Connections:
3V3: C142.P$2, C143.P$1, C147.P$2, C148.P$2, C149.P$1, R155.P$1, R175.P$2, U2.6 (VP), U2.10 (AVDD), U2.16 (VVCO), U2.17 (VVCO), U2.26 (PDBRF), U2.28 (DVDD), U2.32 (SDVDD); also elsewhere on the board
ADFCE: R175.P$1, U2.4 (CE)
CLKOUT: C51.P$2; also elsewhere on the board
CLKOUTAC: C51.P$1, C154.P$2, R177.P$2
CLK_N: C152.P$1; also elsewhere on the board
CLK_P: C151.P$1; also elsewhere on the board
CPOUT: C155.P$1, R178.P$2, R185.P$1, U2.7 (CPOUT)
GND: C142.P$1, C143.P$2, C144.P$2, C145.P$1, C146.P$1, C147.P$1, C148.P$1, C149.P$2, C150.P$2, C155.P$2, C156.P$2, C157.P$2, R156.P$1, R173.P$1, R174.P$1, R176.P$1, R177.P$1, U2.8 (CPGND), U2.9 (AGND), U2.11 (AGNDVCO), U2.18 (AGNDVCO), U2.21 (AGNDVCO), U2.27 (DGND), U2.31 (SDGND), U2.PAD@1_1 (GND), U2.PAD@1_2 (GND), U2.PAD@1_3 (GND), U2.PAD@2_1 (GND), U2.PAD@2_2 (GND), U2.PAD@2_3 (GND), U2.PAD@3_1 (GND), U2.PAD@3_2 (GND), U2.PAD@3_3 (GND); also elsewhere on the board
LOCKDETECT: U2.25 (LD); also elsewhere on the board
MUXOUT: U2.30 (MUXOUT); also elsewhere on the board
unnamed: C146.P$2, U2.19 (TEMP)
unnamed: C145.P$2, U2.23 (VCOM)
unnamed: R176.P$2, U2.22 (RSET)
unnamed: C157.P$1, R185.P$2
REF_CLK: C154.P$1, U2.29 (REFIN)
RFOUTA_N: C151.P$2, R154.P$1, U2.13 (RFOUTA-)
RFOUTA_P: C152.P$2, R153.P$1, U2.12 (RFOUTA+)
SCLK3: R174.P$2, U2.1 (CLK); also elsewhere on the board
SCS3_CLK: R156.P$2, U2.3 (LE); also elsewhere on the board
SDI3: R173.P$2, U2.2 (DATA); also elsewhere on the board
VOUT: C150.P$1, R153.P$2, R154.P$2, R155.P$2
VREF2: C144.P$1, U2.24 (VREF)
VTUNE: C156.P$1, R178.P$1, U2.20 (VTUNE)

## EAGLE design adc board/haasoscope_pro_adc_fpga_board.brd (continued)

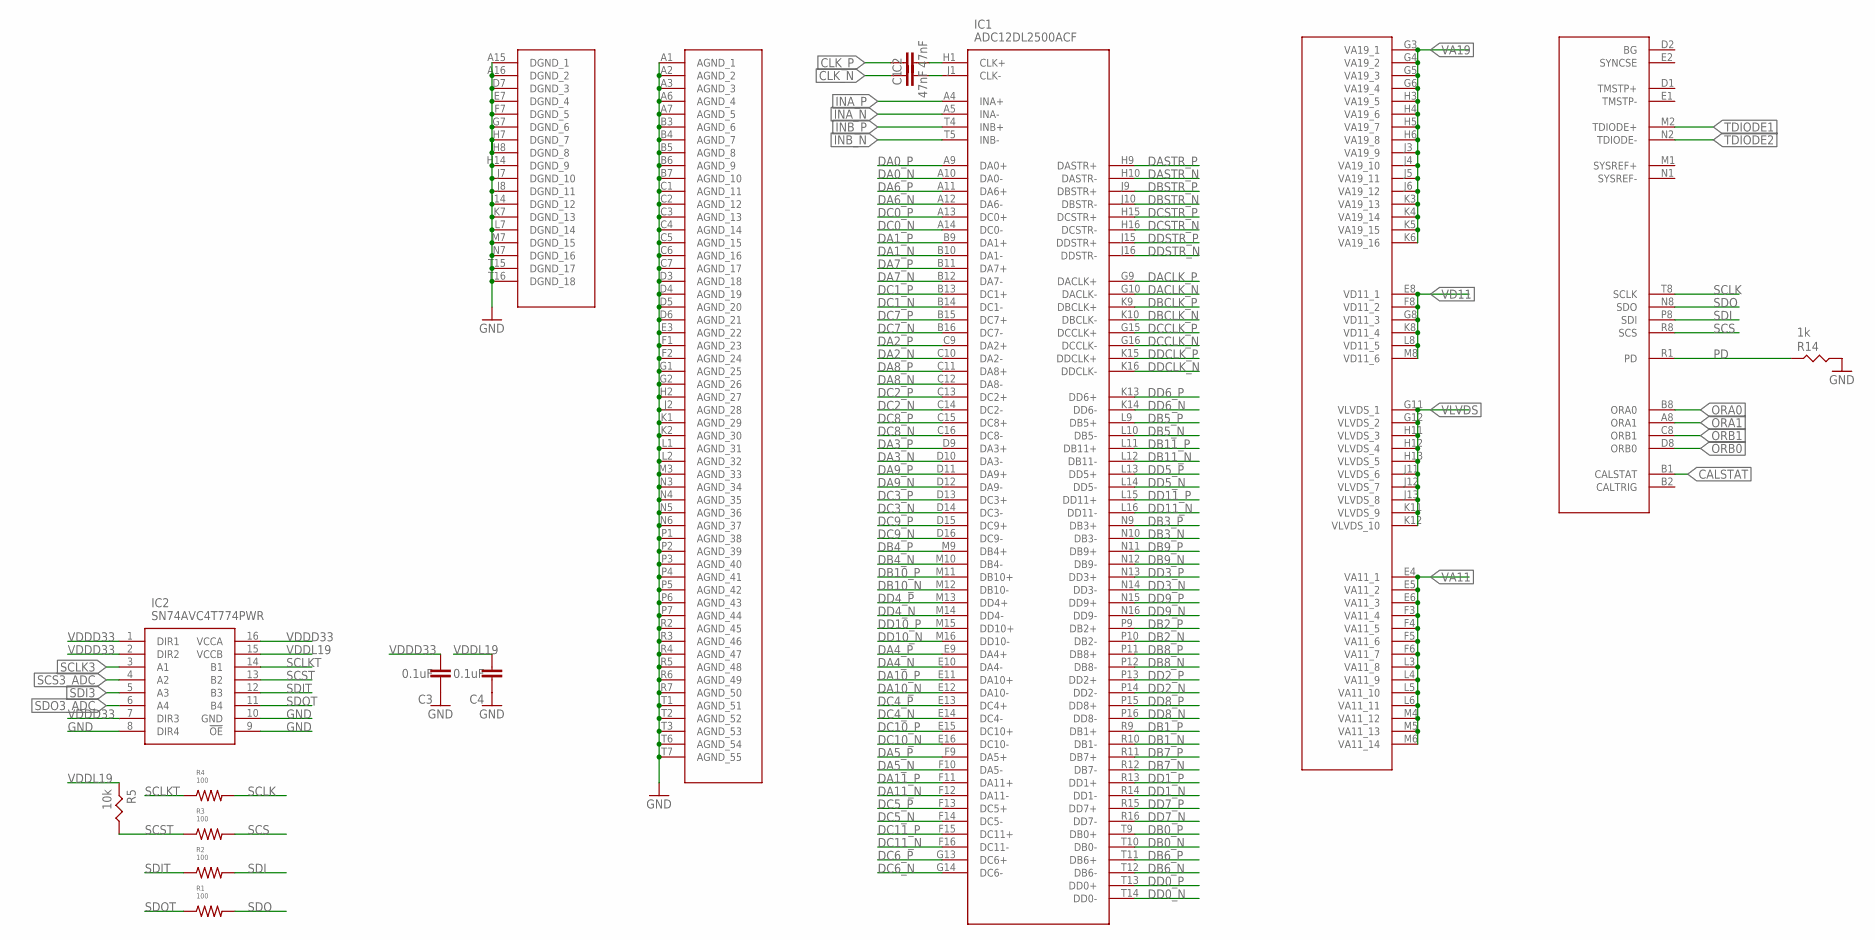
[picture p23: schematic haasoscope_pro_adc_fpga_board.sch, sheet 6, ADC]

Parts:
C1, C2: 47nF; RESC0402_N
C3, C4: 0.1uF; RESC0402_N
IC1: ADC12DL2500ACF; BGA256C100P16X16_1700X1700X331; MANUFACTURER_PART_NUMBER ADC12DL500ACF
IC2: SN74AVC4T774PWR; SOP65P640X120-16N
R1, R2, R3, R4: 100; R0201
R5: 10k; RES-0402
R14: 1k; RES-0402

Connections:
CALSTAT: IC1.B1 (CALSTAT); also elsewhere on the board
CLK_AC_N: C1.1, IC1.J1 (CLK-)
CLK_AC_P: C2.2, IC1.H1 (CLK+)
CLK_N: C1.2; also elsewhere on the board
CLK_P: C2.1; also elsewhere on the board
DA0_N: IC1.A10 (DA0-); also elsewhere on the board
DA0_P: IC1.A9 (DA0+); also elsewhere on the board
DA1_N: IC1.B10 (DA1-); also elsewhere on the board
DA1_P: IC1.B9 (DA1+); also elsewhere on the board
DA2_N: IC1.C10 (DA2-); also elsewhere on the board
DA2_P: IC1.C9 (DA2+); also elsewhere on the board
DA3_N: IC1.D10 (DA3-); also elsewhere on the board
DA3_P: IC1.D9 (DA3+); also elsewhere on the board
DA4_N: IC1.E10 (DA4-); also elsewhere on the board
DA4_P: IC1.E9 (DA4+); also elsewhere on the board
DA5_N: IC1.F10 (DA5-); also elsewhere on the board
DA5_P: IC1.F9 (DA5+); also elsewhere on the board
DA6_N: IC1.A12 (DA6-); also elsewhere on the board
DA6_P: IC1.A11 (DA6+); also elsewhere on the board
DA7_N: IC1.B12 (DA7-); also elsewhere on the board
DA7_P: IC1.B11 (DA7+); also elsewhere on the board
DA8_N: IC1.C12 (DA8-); also elsewhere on the board
DA8_P: IC1.C11 (DA8+); also elsewhere on the board
DA9_N: IC1.D12 (DA9-); also elsewhere on the board
DA9_P: IC1.D11 (DA9+); also elsewhere on the board
DA10_N: IC1.E12 (DA10-); also elsewhere on the board
DA10_P: IC1.E11 (DA10+); also elsewhere on the board
DA11_N: IC1.F12 (DA11-); also elsewhere on the board
DA11_P: IC1.F11 (DA11+); also elsewhere on the board
DACLK_N: IC1.G10 (DACLK-); also elsewhere on the board
DACLK_P: IC1.G9 (DACLK+); also elsewhere on the board
DASTR_N: IC1.H10 (DASTR-); also elsewhere on the board
DASTR_P: IC1.H9 (DASTR+); also elsewhere on the board
DB0_N: IC1.T10 (DB0-); also elsewhere on the board
DB0_P: IC1.T9 (DB0+); also elsewhere on the board
DB1_N: IC1.R10 (DB1-); also elsewhere on the board
DB1_P: IC1.R9 (DB1+); also elsewhere on the board
DB2_N: IC1.P10 (DB2-); also elsewhere on the board
DB2_P: IC1.P9 (DB2+); also elsewhere on the board
DB3_N: IC1.N10 (DB3-); also elsewhere on the board
DB3_P: IC1.N9 (DB3+); also elsewhere on the board
DB4_N: IC1.M10 (DB4-); also elsewhere on the board
DB4_P: IC1.M9 (DB4+); also elsewhere on the board
DB5_N: IC1.L10 (DB5-); also elsewhere on the board
DB5_P: IC1.L9 (DB5+); also elsewhere on the board
DB6_N: IC1.T12 (DB6-); also elsewhere on the board
DB6_P: IC1.T11 (DB6+); also elsewhere on the board
DB7_N: IC1.R12 (DB7-); also elsewhere on the board
DB7_P: IC1.R11 (DB7+); also elsewhere on the board
DB8_N: IC1.P12 (DB8-); also elsewhere on the board
DB8_P: IC1.P11 (DB8+); also elsewhere on the board
DB9_N: IC1.N12 (DB9-); also elsewhere on the board
DB9_P: IC1.N11 (DB9+); also elsewhere on the board
DB10_N: IC1.M12 (DB10-); also elsewhere on the board
DB10_P: IC1.M11 (DB10+); also elsewhere on the board
DB11_N: IC1.L12 (DB11-); also elsewhere on the board
DB11_P: IC1.L11 (DB11+); also elsewhere on the board
DBCLK_N: IC1.K10 (DBCLK-); also elsewhere on the board
DBCLK_P: IC1.K9 (DBCLK+); also elsewhere on the board
DBSTR_N: IC1.J10 (DBSTR-); also elsewhere on the board
DBSTR_P: IC1.J9 (DBSTR+); also elsewhere on the board
DC0_N: IC1.A14 (DC0-); also elsewhere on the board
DC0_P: IC1.A13 (DC0+); also elsewhere on the board
DC1_N: IC1.B14 (DC1-); also elsewhere on the board
DC1_P: IC1.B13 (DC1+); also elsewhere on the board
DC2_N: IC1.C14 (DC2-); also elsewhere on the board
DC2_P: IC1.C13 (DC2+); also elsewhere on the board
DC3_N: IC1.D14 (DC3-); also elsewhere on the board
DC3_P: IC1.D13 (DC3+); also elsewhere on the board
DC4_N: IC1.E14 (DC4-); also elsewhere on the board
DC4_P: IC1.E13 (DC4+); also elsewhere on the board
DC5_N: IC1.F14 (DC5-); also elsewhere on the board
DC5_P: IC1.F13 (DC5+); also elsewhere on the board
DC6_N: IC1.G14 (DC6-); also elsewhere on the board
DC6_P: IC1.G13 (DC6+); also elsewhere on the board
DC7_N: IC1.B16 (DC7-); also elsewhere on the board
DC7_P: IC1.B15 (DC7+); also elsewhere on the board
DC8_N: IC1.C16 (DC8-); also elsewhere on the board
DC8_P: IC1.C15 (DC8+); also elsewhere on the board
DC9_N: IC1.D16 (DC9-); also elsewhere on the board
DC9_P: IC1.D15 (DC9+); also elsewhere on the board
DC10_N: IC1.E16 (DC10-); also elsewhere on the board
DC10_P: IC1.E15 (DC10+); also elsewhere on the board
DC11_N: IC1.F16 (DC11-); also elsewhere on the board
DC11_P: IC1.F15 (DC11+); also elsewhere on the board
DCCLK_N: IC1.G16 (DCCLK-); also elsewhere on the board
DCCLK_P: IC1.G15 (DCCLK+); also elsewhere on the board
DCSTR_N: IC1.H16 (DCSTR-); also elsewhere on the board
DCSTR_P: IC1.H15 (DCSTR+); also elsewhere on the board
DD0_N: IC1.T14 (DD0-); also elsewhere on the board
DD0_P: IC1.T13 (DD0+); also elsewhere on the board
DD1_N: IC1.R14 (DD1-); also elsewhere on the board
DD1_P: IC1.R13 (DD1+); also elsewhere on the board
DD2_N: IC1.P14 (DD2-); also elsewhere on the board
DD2_P: IC1.P13 (DD2+); also elsewhere on the board
DD3_N: IC1.N14 (DD3-); also elsewhere on the board
DD3_P: IC1.N13 (DD3+); also elsewhere on the board
DD4_N: IC1.M14 (DD4-); also elsewhere on the board
DD4_P: IC1.M13 (DD4+); also elsewhere on the board
DD5_N: IC1.L14 (DD5-); also elsewhere on the board
DD5_P: IC1.L13 (DD5+); also elsewhere on the board
DD6_N: IC1.K14 (DD6-); also elsewhere on the board
DD6_P: IC1.K13 (DD6+); also elsewhere on the board
DD7_N: IC1.R16 (DD7-); also elsewhere on the board
DD7_P: IC1.R15 (DD7+); also elsewhere on the board
DD8_N: IC1.P16 (DD8-); also elsewhere on the board
DD8_P: IC1.P15 (DD8+); also elsewhere on the board
DD9_N: IC1.N16 (DD9-); also elsewhere on the board
DD9_P: IC1.N15 (DD9+); also elsewhere on the board
DD10_N: IC1.M16 (DD10-); also elsewhere on the board
DD10_P: IC1.M15 (DD10+); also elsewhere on the board
DD11_N: IC1.L16 (DD11-); also elsewhere on the board
DD11_P: IC1.L15 (DD11+); also elsewhere on the board
DDCLK_N: IC1.K16 (DDCLK-); also elsewhere on the board
DDCLK_P: IC1.K15 (DDCLK+); also elsewhere on the board
DDSTR_N: IC1.J16 (DDSTR-); also elsewhere on the board
DDSTR_P: IC1.J15 (DDSTR+); also elsewhere on the board
GND: C3.1, C4.1, IC1.A1 (AGND_1), IC1.A2 (AGND_2), IC1.A3 (AGND_3), IC1.A6 (AGND_4), IC1.A7 (AGND_5), IC1.A15 (DGND_1), IC1.A16 (DGND_2), IC1.B3 (AGND_6), IC1.B4 (AGND_7), IC1.B5 (AGND_8), IC1.B6 (AGND_9), IC1.B7 (AGND_10), IC1.C1 (AGND_11), IC1.C2 (AGND_12), IC1.C3 (AGND_13), IC1.C4 (AGND_14), IC1.C5 (AGND_15), IC1.C6 (AGND_16), IC1.C7 (AGND_17), IC1.D3 (AGND_18), IC1.D4 (AGND_19), IC1.D5 (AGND_20), IC1.D6 (AGND_21), IC1.D7 (DGND_3), IC1.E3 (AGND_22), IC1.E7 (DGND_4), IC1.F1 (AGND_23), IC1.F2 (AGND_24), IC1.F7 (DGND_5), IC1.G1 (AGND_25), IC1.G2 (AGND_26), IC1.G7 (DGND_6), IC1.H2 (AGND_27), IC1.H7 (DGND_7), IC1.H8 (DGND_8), IC1.H14 (DGND_9), IC1.J2 (AGND_28), IC1.J7 (DGND_10), IC1.J8 (DGND_11), IC1.J14 (DGND_12), IC1.K1 (AGND_29), IC1.K2 (AGND_30), IC1.K7 (DGND_13), IC1.L1 (AGND_31), IC1.L2 (AGND_32), IC1.L7 (DGND_14), IC1.M3 (AGND_33), IC1.M7 (DGND_15), IC1.N3 (AGND_34), IC1.N4 (AGND_35), IC1.N5 (AGND_36), IC1.N6 (AGND_37), IC1.N7 (DGND_16), IC1.P1 (AGND_38), IC1.P2 (AGND_39), IC1.P3 (AGND_40), IC1.P4 (AGND_41), IC1.P5 (AGND_42), IC1.P6 (AGND_43), IC1.P7 (AGND_44), IC1.R2 (AGND_45), IC1.R3 (AGND_46), IC1.R4 (AGND_47), IC1.R5 (AGND_48), IC1.R6 (AGND_49), IC1.R7 (AGND_50), IC1.T1 (AGND_51), IC1.T2 (AGND_52), IC1.T3 (AGND_53), IC1.T6 (AGND_54), IC1.T7 (AGND_55), IC1.T15 (DGND_17), IC1.T16 (DGND_18), IC2.8 (DIR4), IC2.9 (!OE), IC2.10 (GND), R14.P$2; also elsewhere on the board
INA_N: IC1.A5 (INA-); also elsewhere on the board
INA_P: IC1.A4 (INA+); also elsewhere on the board
INB_N: IC1.T5 (INB-); also elsewhere on the board
INB_P: IC1.T4 (INB+); also elsewhere on the board
ORA0: IC1.B8 (ORA0); also elsewhere on the board
ORA1: IC1.A8 (ORA1); also elsewhere on the board
ORB0: IC1.D8 (ORB0); also elsewhere on the board
ORB1: IC1.C8 (ORB1); also elsewhere on the board
PD: IC1.R1 (PD), R14.P$1
SCLK: IC1.T8 (SCLK), R4.2
SCLK3: IC2.3 (A1); also elsewhere on the board
SCLKT: IC2.14 (B1), R4.1
SCS: IC1.R8 (SCS), R3.2
SCS3_ADC: IC2.4 (A2); also elsewhere on the board
SCST: IC2.13 (B2), R3.1, R5.P$2
SDI: IC1.P8 (SDI), R2.2
SDI3: IC2.5 (A3); also elsewhere on the board
SDIT: IC2.12 (B3), R2.1
SDO: IC1.N8 (SDO), R1.2
SDO3_ADC: IC2.6 (A4); also elsewhere on the board
SDOT: IC2.11 (B4), R1.1
TDIODE1: IC1.M2 (TDIODE+); also elsewhere on the board
TDIODE2: IC1.N2 (TDIODE-); also elsewhere on the board
VA11: IC1.E4 (VA11_1), IC1.E5 (VA11_2), IC1.E6 (VA11_3), IC1.F3 (VA11_4), IC1.F4 (VA11_5), IC1.F5 (VA11_6), IC1.F6 (VA11_7), IC1.L3 (VA11_8), IC1.L4 (VA11_9), IC1.L5 (VA11_10), IC1.L6 (VA11_11), IC1.M4 (VA11_12), IC1.M5 (VA11_13), IC1.M6 (VA11_14); also elsewhere on the board
VA19: IC1.G3 (VA19_1), IC1.G4 (VA19_2), IC1.G5 (VA19_3), IC1.G6 (VA19_4), IC1.H3 (VA19_5), IC1.H4 (VA19_6), IC1.H5 (VA19_7), IC1.H6 (VA19_8), IC1.J3 (VA19_9), IC1.J4 (VA19_10), IC1.J5 (VA19_11), IC1.J6 (VA19_12), IC1.K3 (VA19_13), IC1.K4 (VA19_14), IC1.K5 (VA19_15), IC1.K6 (VA19_16); also elsewhere on the board
VD11: IC1.E8 (VD11_1), IC1.F8 (VD11_2), IC1.G8 (VD11_3), IC1.K8 (VD11_4), IC1.L8 (VD11_5), IC1.M8 (VD11_6); also elsewhere on the board
VDDD33: C3.2, IC2.1 (DIR1), IC2.2 (DIR2), IC2.7 (DIR3), IC2.16 (VCCA); also elsewhere on the board
VDDL19: C4.2, IC2.15 (VCCB), R5.P$1; also elsewhere on the board
VLVDS: IC1.G11 (VLVDS_1), IC1.G12 (VLVDS_2), IC1.H11 (VLVDS_3), IC1.H12 (VLVDS_4), IC1.H13 (VLVDS_5), IC1.J11 (VLVDS_6), IC1.J12 (VLVDS_7), IC1.J13 (VLVDS_8), IC1.K11 (VLVDS_9), IC1.K12 (VLVDS_10); also elsewhere on the board

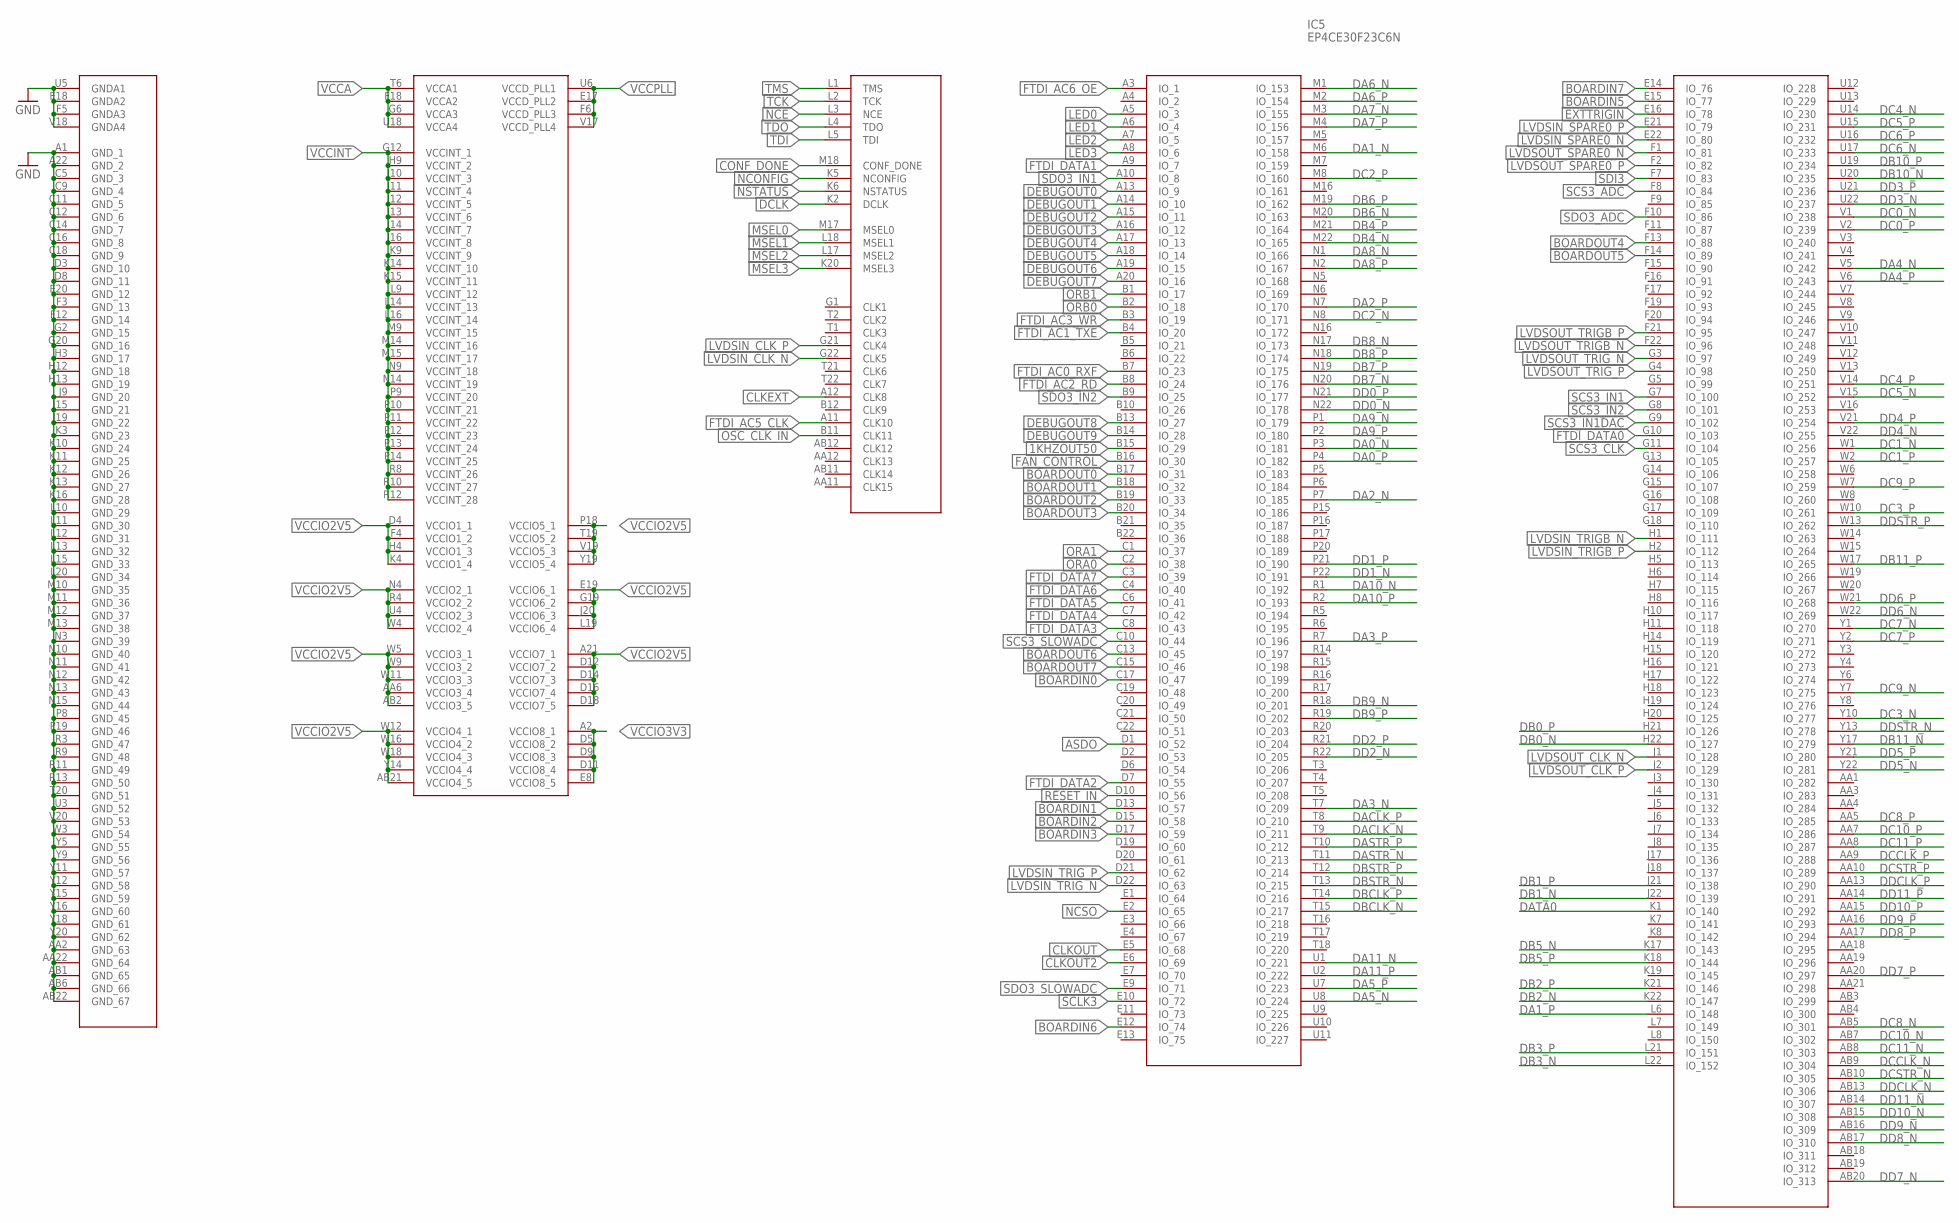
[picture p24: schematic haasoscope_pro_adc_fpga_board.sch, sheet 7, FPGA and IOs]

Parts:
IC5: EP4CE30F23C6N; BGA484C100P22X22_2300X2300X240

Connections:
1KHZOUT50: IC5.B15 (IO_29); also elsewhere on the board
ASDO: IC5.D1 (IO_52); also elsewhere on the board
BOARDIN0: IC5.C17 (IO_47); also elsewhere on the board
BOARDIN1: IC5.D13 (IO_57); also elsewhere on the board
BOARDIN2: IC5.D15 (IO_58); also elsewhere on the board
BOARDIN3: IC5.D17 (IO_59); also elsewhere on the board
BOARDIN5: IC5.E15 (IO_77); also elsewhere on the board
BOARDIN6: IC5.E12 (IO_74); also elsewhere on the board
BOARDIN7: IC5.E14 (IO_76); also elsewhere on the board
BOARDOUT0: IC5.B17 (IO_31); also elsewhere on the board
BOARDOUT1: IC5.B18 (IO_32); also elsewhere on the board
BOARDOUT2: IC5.B19 (IO_33); also elsewhere on the board
BOARDOUT3: IC5.B20 (IO_34); also elsewhere on the board
BOARDOUT4: IC5.F13 (IO_88); also elsewhere on the board
BOARDOUT5: IC5.F14 (IO_89); also elsewhere on the board
BOARDOUT6: IC5.C13 (IO_45); also elsewhere on the board
BOARDOUT7: IC5.C15 (IO_46); also elsewhere on the board
CLKEXT: IC5.A12 (CLK8); also elsewhere on the board
CLKOUT: IC5.E5 (IO_68); also elsewhere on the board
CLKOUT2: IC5.E6 (IO_69); also elsewhere on the board
CONF_DONE: IC5.M18 (CONF_DONE); also elsewhere on the board
DA0_N: IC5.P3 (IO_181); also elsewhere on the board
DA0_P: IC5.P4 (IO_182); also elsewhere on the board
DA1_N: IC5.M6 (IO_158); also elsewhere on the board
DA1_P: IC5.L6 (IO_148); also elsewhere on the board
DA2_N: IC5.P7 (IO_185); also elsewhere on the board
DA2_P: IC5.N7 (IO_170); also elsewhere on the board
DA3_N: IC5.T7 (IO_209); also elsewhere on the board
DA3_P: IC5.R7 (IO_196); also elsewhere on the board
DA4_N: IC5.V5 (IO_242); also elsewhere on the board
DA4_P: IC5.V6 (IO_243); also elsewhere on the board
DA5_N: IC5.U8 (IO_224); also elsewhere on the board
DA5_P: IC5.U7 (IO_223); also elsewhere on the board
DA6_N: IC5.M1 (IO_153); also elsewhere on the board
DA6_P: IC5.M2 (IO_154); also elsewhere on the board
DA7_N: IC5.M3 (IO_155); also elsewhere on the board
DA7_P: IC5.M4 (IO_156); also elsewhere on the board
DA8_N: IC5.N1 (IO_166); also elsewhere on the board
DA8_P: IC5.N2 (IO_167); also elsewhere on the board
DA9_N: IC5.P1 (IO_179); also elsewhere on the board
DA9_P: IC5.P2 (IO_180); also elsewhere on the board
DA10_N: IC5.R1 (IO_192); also elsewhere on the board
DA10_P: IC5.R2 (IO_193); also elsewhere on the board
DA11_N: IC5.U1 (IO_221); also elsewhere on the board
DA11_P: IC5.U2 (IO_222); also elsewhere on the board
DACLK_N: IC5.T9 (IO_211); also elsewhere on the board
DACLK_P: IC5.T8 (IO_210); also elsewhere on the board
DASTR_N: IC5.T11 (IO_213); also elsewhere on the board
DASTR_P: IC5.T10 (IO_212); also elsewhere on the board
DATA0: IC5.K1 (IO_140); also elsewhere on the board
DB0_N: IC5.H22 (IO_127); also elsewhere on the board
DB0_P: IC5.H21 (IO_126); also elsewhere on the board
DB1_N: IC5.J22 (IO_139); also elsewhere on the board
DB1_P: IC5.J21 (IO_138); also elsewhere on the board
DB2_N: IC5.K22 (IO_147); also elsewhere on the board
DB2_P: IC5.K21 (IO_146); also elsewhere on the board
DB3_N: IC5.L22 (IO_152); also elsewhere on the board
DB3_P: IC5.L21 (IO_151); also elsewhere on the board
DB4_N: IC5.M22 (IO_165); also elsewhere on the board
DB4_P: IC5.M21 (IO_164); also elsewhere on the board
DB5_N: IC5.K17 (IO_143); also elsewhere on the board
DB5_P: IC5.K18 (IO_144); also elsewhere on the board
DB6_N: IC5.M20 (IO_163); also elsewhere on the board
DB6_P: IC5.M19 (IO_162); also elsewhere on the board
DB7_N: IC5.N20 (IO_176); also elsewhere on the board
DB7_P: IC5.N19 (IO_175); also elsewhere on the board
DB8_N: IC5.N17 (IO_173); also elsewhere on the board
DB8_P: IC5.N18 (IO_174); also elsewhere on the board
DB9_N: IC5.R18 (IO_201); also elsewhere on the board
DB9_P: IC5.R19 (IO_202); also elsewhere on the board
DB10_N: IC5.U20 (IO_235); also elsewhere on the board
DB10_P: IC5.U19 (IO_234); also elsewhere on the board
DB11_N: IC5.Y17 (IO_279); also elsewhere on the board
DB11_P: IC5.W17 (IO_265); also elsewhere on the board
DBCLK_N: IC5.T15 (IO_217); also elsewhere on the board
DBCLK_P: IC5.T14 (IO_216); also elsewhere on the board
DBSTR_N: IC5.T13 (IO_215); also elsewhere on the board
DBSTR_P: IC5.T12 (IO_214); also elsewhere on the board
DC0_N: IC5.V1 (IO_238); also elsewhere on the board
DC0_P: IC5.V2 (IO_239); also elsewhere on the board
DC1_N: IC5.W1 (IO_256); also elsewhere on the board
DC1_P: IC5.W2 (IO_257); also elsewhere on the board
DC2_N: IC5.N8 (IO_171); also elsewhere on the board
DC2_P: IC5.M8 (IO_160); also elsewhere on the board
DC3_N: IC5.Y10 (IO_277); also elsewhere on the board
DC3_P: IC5.W10 (IO_261); also elsewhere on the board
DC4_N: IC5.U14 (IO_230); also elsewhere on the board
DC4_P: IC5.V14 (IO_251); also elsewhere on the board
DC5_N: IC5.V15 (IO_252); also elsewhere on the board
DC5_P: IC5.U15 (IO_231); also elsewhere on the board
DC6_N: IC5.U17 (IO_233); also elsewhere on the board
DC6_P: IC5.U16 (IO_232); also elsewhere on the board
DC7_N: IC5.Y1 (IO_270); also elsewhere on the board
DC7_P: IC5.Y2 (IO_271); also elsewhere on the board
DC8_N: IC5.AB5 (IO_301); also elsewhere on the board
DC8_P: IC5.AA5 (IO_285); also elsewhere on the board
DC9_N: IC5.Y7 (IO_275); also elsewhere on the board
DC9_P: IC5.W7 (IO_259); also elsewhere on the board
DC10_N: IC5.AB7 (IO_302); also elsewhere on the board
DC10_P: IC5.AA7 (IO_286); also elsewhere on the board
DC11_N: IC5.AB8 (IO_303); also elsewhere on the board
DC11_P: IC5.AA8 (IO_287); also elsewhere on the board
DCCLK_N: IC5.AB9 (IO_304); also elsewhere on the board
DCCLK_P: IC5.AA9 (IO_288); also elsewhere on the board
DCLK: IC5.K2 (DCLK); also elsewhere on the board
DCSTR_N: IC5.AB10 (IO_305); also elsewhere on the board
DCSTR_P: IC5.AA10 (IO_289); also elsewhere on the board
DD0_N: IC5.N22 (IO_178); also elsewhere on the board
DD0_P: IC5.N21 (IO_177); also elsewhere on the board
DD1_N: IC5.P22 (IO_191); also elsewhere on the board
DD1_P: IC5.P21 (IO_190); also elsewhere on the board
DD2_N: IC5.R22 (IO_205); also elsewhere on the board
DD2_P: IC5.R21 (IO_204); also elsewhere on the board
DD3_N: IC5.U22 (IO_237); also elsewhere on the board
DD3_P: IC5.U21 (IO_236); also elsewhere on the board
DD4_N: IC5.V22 (IO_255); also elsewhere on the board
DD4_P: IC5.V21 (IO_254); also elsewhere on the board
DD5_N: IC5.Y22 (IO_281); also elsewhere on the board
DD5_P: IC5.Y21 (IO_280); also elsewhere on the board
DD6_N: IC5.W22 (IO_269); also elsewhere on the board
DD6_P: IC5.W21 (IO_268); also elsewhere on the board
DD7_N: IC5.AB20 (IO_313); also elsewhere on the board
DD7_P: IC5.AA20 (IO_297); also elsewhere on the board
DD8_N: IC5.AB17 (IO_310); also elsewhere on the board
DD8_P: IC5.AA17 (IO_294); also elsewhere on the board
DD9_N: IC5.AB16 (IO_309); also elsewhere on the board
DD9_P: IC5.AA16 (IO_293); also elsewhere on the board
DD10_N: IC5.AB15 (IO_308); also elsewhere on the board
DD10_P: IC5.AA15 (IO_292); also elsewhere on the board
DD11_N: IC5.AB14 (IO_307); also elsewhere on the board
DD11_P: IC5.AA14 (IO_291); also elsewhere on the board
DDCLK_N: IC5.AB13 (IO_306); also elsewhere on the board
DDCLK_P: IC5.AA13 (IO_290); also elsewhere on the board
DDSTR_N: IC5.Y13 (IO_278); also elsewhere on the board
DDSTR_P: IC5.W13 (IO_262); also elsewhere on the board
DEBUGOUT0: IC5.A13 (IO_9); also elsewhere on the board
DEBUGOUT1: IC5.A14 (IO_10); also elsewhere on the board
DEBUGOUT2: IC5.A15 (IO_11); also elsewhere on the board
DEBUGOUT3: IC5.A16 (IO_12); also elsewhere on the board
DEBUGOUT4: IC5.A17 (IO_13); also elsewhere on the board
DEBUGOUT5: IC5.A18 (IO_14); also elsewhere on the board
DEBUGOUT6: IC5.A19 (IO_15); also elsewhere on the board
DEBUGOUT7: IC5.A20 (IO_16); also elsewhere on the board
DEBUGOUT8: IC5.B13 (IO_27); also elsewhere on the board
DEBUGOUT9: IC5.B14 (IO_28); also elsewhere on the board
EXTTRIGIN: IC5.E16 (IO_78); also elsewhere on the board
FAN_CONTROL: IC5.B16 (IO_30); also elsewhere on the board
FTDI_AC0_RXF: IC5.B7 (IO_23); also elsewhere on the board
FTDI_AC1_TXE: IC5.B4 (IO_20); also elsewhere on the board
FTDI_AC2_RD: IC5.B8 (IO_24); also elsewhere on the board
FTDI_AC3_WR: IC5.B3 (IO_19); also elsewhere on the board
FTDI_AC5_CLK: IC5.A11 (CLK10); also elsewhere on the board
FTDI_AC6_OE: IC5.A3 (IO_1); also elsewhere on the board
FTDI_DATA0: IC5.G10 (IO_103); also elsewhere on the board
FTDI_DATA1: IC5.A9 (IO_7); also elsewhere on the board
FTDI_DATA2: IC5.D7 (IO_55); also elsewhere on the board
FTDI_DATA3: IC5.C8 (IO_43); also elsewhere on the board
FTDI_DATA4: IC5.C7 (IO_42); also elsewhere on the board
FTDI_DATA5: IC5.C6 (IO_41); also elsewhere on the board
FTDI_DATA6: IC5.C4 (IO_40); also elsewhere on the board
FTDI_DATA7: IC5.C3 (IO_39); also elsewhere on the board
GND: IC5.A1 (GND_1), IC5.A22 (GND_2), IC5.AA2 (GND_63), IC5.AA22 (GND_64), IC5.AB1 (GND_65), IC5.AB6 (GND_66), IC5.AB22 (GND_67), IC5.C5 (GND_3), IC5.C9 (GND_4), IC5.C11 (GND_5), IC5.C12 (GND_6), IC5.C14 (GND_7), IC5.C16 (GND_8), IC5.C18 (GND_9), IC5.D3 (GND_10), IC5.D8 (GND_11), IC5.E18 (GNDA2), IC5.E20 (GND_12), IC5.F3 (GND_13), IC5.F5 (GNDA3), IC5.F12 (GND_14), IC5.G2 (GND_15), IC5.G20 (GND_16), IC5.H3 (GND_17), IC5.H12 (GND_18), IC5.H13 (GND_19), IC5.J9 (GND_20), IC5.J15 (GND_21), IC5.J19 (GND_22), IC5.K3 (GND_23), IC5.K10 (GND_24), IC5.K11 (GND_25), IC5.K12 (GND_26), IC5.K13 (GND_27), IC5.K16 (GND_28), IC5.L10 (GND_29), IC5.L11 (GND_30), IC5.L12 (GND_31), IC5.L13 (GND_32), IC5.L15 (GND_33), IC5.L20 (GND_34), IC5.M10 (GND_35), IC5.M11 (GND_36), IC5.M12 (GND_37), IC5.M13 (GND_38), IC5.N3 (GND_39), IC5.N10 (GND_40), IC5.N11 (GND_41), IC5.N12 (GND_42), IC5.N13 (GND_43), IC5.N15 (GND_44), IC5.P8 (GND_45), IC5.P19 (GND_46), IC5.R3 (GND_47), IC5.R9 (GND_48), IC5.R11 (GND_49), IC5.R13 (GND_50), IC5.T20 (GND_51), IC5.U3 (GND_52), IC5.U5 (GNDA1), IC5.V18 (GNDA4), IC5.V20 (GND_53), IC5.W3 (GND_54), IC5.Y5 (GND_55), IC5.Y9 (GND_56), IC5.Y11 (GND_57), IC5.Y12 (GND_58), IC5.Y15 (GND_59), IC5.Y16 (GND_60), IC5.Y18 (GND_61), IC5.Y20 (GND_62); also elsewhere on the board
LED0: IC5.A5 (IO_3); also elsewhere on the board
LED1: IC5.A6 (IO_4); also elsewhere on the board
LED2: IC5.A7 (IO_5); also elsewhere on the board
LED3: IC5.A8 (IO_6); also elsewhere on the board
LVDSIN_CLK_N: IC5.G22 (CLK5); also elsewhere on the board
LVDSIN_CLK_P: IC5.G21 (CLK4); also elsewhere on the board
LVDSIN_SPARE0_N: IC5.E22 (IO_80); also elsewhere on the board
LVDSIN_SPARE0_P: IC5.E21 (IO_79); also elsewhere on the board
LVDSIN_TRIGB_N: IC5.H1 (IO_111); also elsewhere on the board
LVDSIN_TRIGB_P: IC5.H2 (IO_112); also elsewhere on the board
LVDSIN_TRIG_N: IC5.D22 (IO_63); also elsewhere on the board
LVDSIN_TRIG_P: IC5.D21 (IO_62); also elsewhere on the board
LVDSOUT_CLK_N: IC5.J1 (IO_128); also elsewhere on the board
LVDSOUT_CLK_P: IC5.J2 (IO_129); also elsewhere on the board
LVDSOUT_SPARE0_N: IC5.F1 (IO_81); also elsewhere on the board
LVDSOUT_SPARE0_P: IC5.F2 (IO_82); also elsewhere on the board
LVDSOUT_TRIGB_N: IC5.F22 (IO_96); also elsewhere on the board
LVDSOUT_TRIGB_P: IC5.F21 (IO_95); also elsewhere on the board
LVDSOUT_TRIG_N: IC5.G3 (IO_97); also elsewhere on the board
LVDSOUT_TRIG_P: IC5.G4 (IO_98); also elsewhere on the board
MSEL0: IC5.M17 (MSEL0); also elsewhere on the board
MSEL1: IC5.L18 (MSEL1); also elsewhere on the board
MSEL2: IC5.L17 (MSEL2); also elsewhere on the board
MSEL3: IC5.K20 (MSEL3); also elsewhere on the board
NCE: IC5.L3 (NCE); also elsewhere on the board
NCONFIG: IC5.K5 (NCONFIG); also elsewhere on the board
NCSO: IC5.E2 (IO_65); also elsewhere on the board
NSTATUS: IC5.K6 (NSTATUS); also elsewhere on the board
ORA0: IC5.C2 (IO_38); also elsewhere on the board
ORA1: IC5.C1 (IO_37); also elsewhere on the board
ORB0: IC5.B2 (IO_18); also elsewhere on the board
ORB1: IC5.B1 (IO_17); also elsewhere on the board
OSC_CLK_IN: IC5.B11 (CLK11); also elsewhere on the board
RESET_IN: IC5.D10 (IO_56); also elsewhere on the board
SCLK3: IC5.E10 (IO_72); also elsewhere on the board
SCS3_ADC: IC5.F8 (IO_84); also elsewhere on the board
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

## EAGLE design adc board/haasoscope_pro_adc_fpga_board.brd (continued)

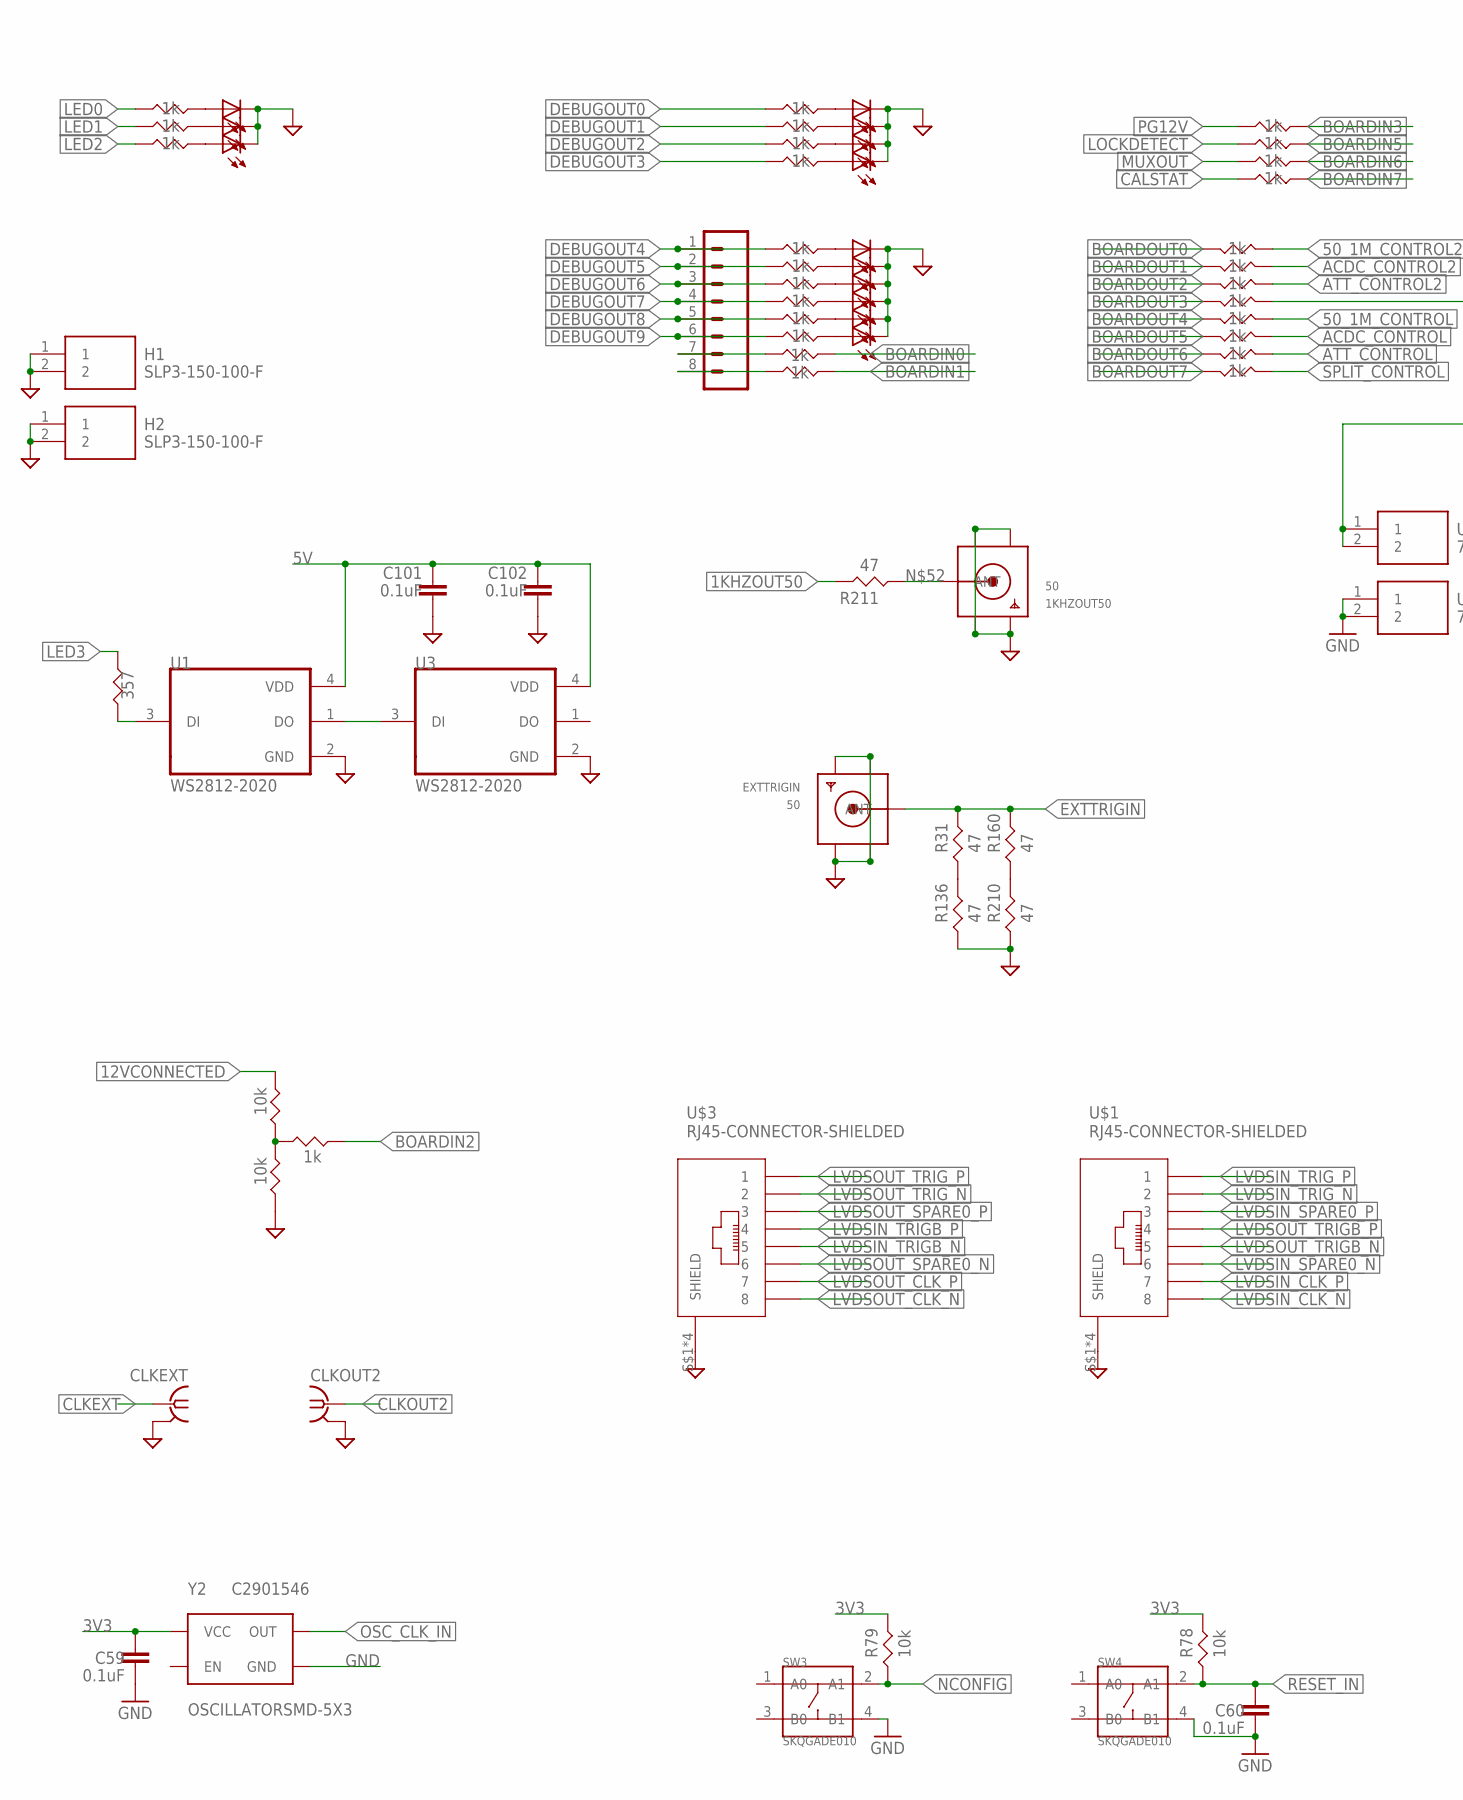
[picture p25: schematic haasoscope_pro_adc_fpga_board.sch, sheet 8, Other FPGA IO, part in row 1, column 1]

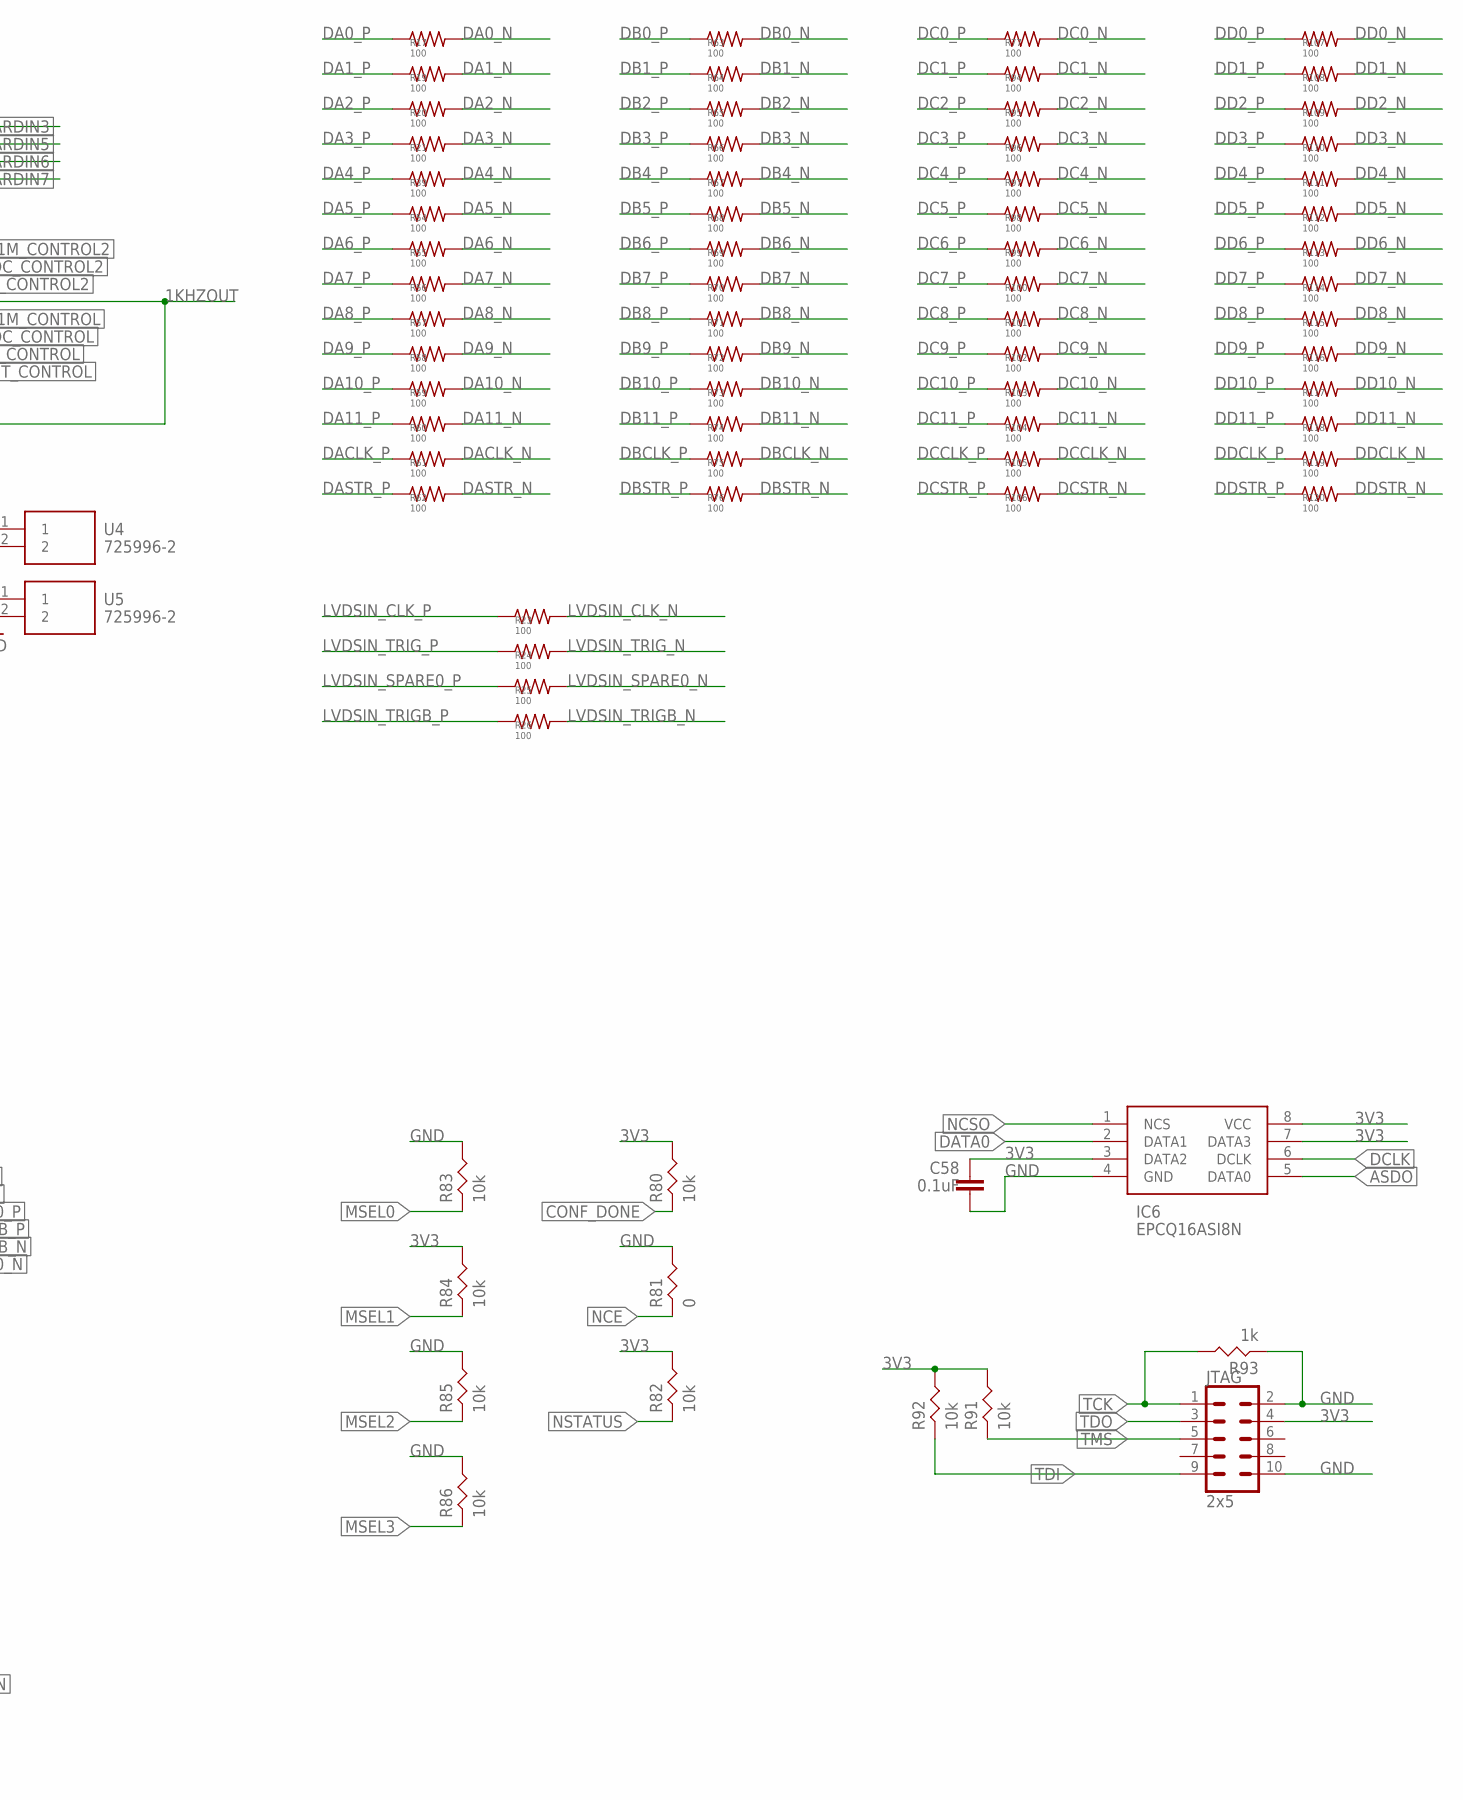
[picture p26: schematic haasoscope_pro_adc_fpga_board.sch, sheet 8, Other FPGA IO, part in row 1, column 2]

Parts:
1KHZOUT50: 50; SMA_EDGELAUNCH
C58, C59, C60, C101, C102: 0.1uF; RESC0402_N
CLKEXT: BU-SMB-V
CLKOUT2: BU-SMB-V
EXTTRIGIN: 50; SMA_EDGELAUNCH
H1, H2: SLP3-150-100-F; SLP3150100F
IC6: EPCQ16ASI8N; SOIC127P600X175-8N
J11: 8pin; 1X08
JTAG: 2x5; 2X5-SHROUDED
LED25, LED26, LED27, LED28, LED29, LED30, LED41, LED42, LED43, LED45, LED46, LED47, LED48: red; CHIP-LED0603
R6, R7, R8, R9, R10, R11, R12, R13, R16, R22, R32, R33, R34, R35, R36, R37, R46, R47, R48, R49, R51, R52, R53, R93, R206, R236, R238, R243, R244: 1k; RES-0402
R17, R19, R20, R21, R23, R24, R25, R26, R39, R54, R55, R56, R57, R58, R59, R60, R61, R62, R63, R64, R65, R66, R67, R68, R69, R70, R71, R72, R73, R74, R75, R76, R77, R94, R95, R96, R97, R98, R99, R100, R101, R102, R103, R104, R105, R106, R107, R108, R109, R110, R111, R112, R113, R114, R115, R116, R117, R118, R119, R120: 100; R0201
R31, R136, R160, R210, R211: 47; RES-0402
R50: 357; RES-0402
R78, R79, R80, R82, R83, R84, R85, R86, R91, R92, R167, R246: 10k; RES-0402
R81: 0; RES-0402
SW3, SW4: SKQGADE010; SW4-SMD-5.2X5.2X1.5MM
U1, U3: WS2812-2020; LED_WS2812-2020
U4, U5: 725996-2; 7259962
U$1, U$3: RJ45-CONNECTOR-SHIELDED; RJ45_THT_RA_AMPH-FRJAE448
Y2: OSCILLATORSMD-5X3; OSCILLATOR-SMD-5X3.2; LCSC C2901546

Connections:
1KHZOUT: R206.P$1, U4.1, U4.2
1KHZOUT50: R211.P$2; also elsewhere on the board
3V3: C58.2, C59.2, IC6.3 (DATA2), IC6.7 (DATA3), IC6.8 (VCC), JTAG.4, R78.P$2, R79.P$2, R80.P$2, R82.P$2, R84.P$2, R91.P$2, R92.P$2, Y2.4 (VCC); also elsewhere on the board
5V: C101.2, C102.2, U1.4 (VDD), U3.4 (VDD); also elsewhere on the board
12VCONNECTED: R167.P$2; also elsewhere on the board
50_1M_CONTROL: R8.P$1; also elsewhere on the board
50_1M_CONTROL2: R12.P$1; also elsewhere on the board
ACDC_CONTROL: R9.P$1; also elsewhere on the board
ACDC_CONTROL2: R13.P$1; also elsewhere on the board
ASDO: IC6.5 (DATA0); also elsewhere on the board
ATT_CONTROL: R10.P$1; also elsewhere on the board
ATT_CONTROL2: R22.P$1; also elsewhere on the board
BOARDIN0: R243.P$1; also elsewhere on the board
BOARDIN1: R244.P$1; also elsewhere on the board
BOARDIN2: R238.P$2; also elsewhere on the board
BOARDIN3: R236.P$2; also elsewhere on the board
BOARDIN5: R7.P$2; also elsewhere on the board
BOARDIN6: R6.P$2; also elsewhere on the board
BOARDIN7: R16.P$2; also elsewhere on the board
BOARDOUT0: R12.P$2; also elsewhere on the board
BOARDOUT1: R13.P$2; also elsewhere on the board
BOARDOUT2: R22.P$2; also elsewhere on the board
BOARDOUT3: R206.P$2; also elsewhere on the board
BOARDOUT4: R8.P$2; also elsewhere on the board
BOARDOUT5: R9.P$2; also elsewhere on the board
BOARDOUT6: R10.P$2; also elsewhere on the board
BOARDOUT7: R11.P$2; also elsewhere on the board
CALSTAT: R16.P$1; also elsewhere on the board
CLKEXT: CLKEXT.1; also elsewhere on the board
CLKOUT2: CLKOUT2.1; also elsewhere on the board
CONF_DONE: R80.P$1; also elsewhere on the board
DA0_N: R17.2; also elsewhere on the board
DA0_P: R17.1; also elsewhere on the board
DA1_N: R19.2; also elsewhere on the board
DA1_P: R19.1; also elsewhere on the board
DA2_N: R20.2; also elsewhere on the board
DA2_P: R20.1; also elsewhere on the board
DA3_N: R21.2; also elsewhere on the board
DA3_P: R21.1; also elsewhere on the board
DA4_N: R39.2; also elsewhere on the board
DA4_P: R39.1; also elsewhere on the board
DA5_N: R54.2; also elsewhere on the board
DA5_P: R54.1; also elsewhere on the board
DA6_N: R55.2; also elsewhere on the board
DA6_P: R55.1; also elsewhere on the board
DA7_N: R56.2; also elsewhere on the board
DA7_P: R56.1; also elsewhere on the board
DA8_N: R57.2; also elsewhere on the board
DA8_P: R57.1; also elsewhere on the board
DA9_N: R58.2; also elsewhere on the board
DA9_P: R58.1; also elsewhere on the board
DA10_N: R59.2; also elsewhere on the board
DA10_P: R59.1; also elsewhere on the board
DA11_N: R60.2; also elsewhere on the board
DA11_P: R60.1; also elsewhere on the board
DACLK_N: R61.2; also elsewhere on the board
DACLK_P: R61.1; also elsewhere on the board
DASTR_N: R62.2; also elsewhere on the board
DASTR_P: R62.1; also elsewhere on the board
DATA0: IC6.2 (DATA1); also elsewhere on the board
DB0_N: R63.2; also elsewhere on the board
DB0_P: R63.1; also elsewhere on the board
DB1_N: R64.2; also elsewhere on the board
DB1_P: R64.1; also elsewhere on the board
DB2_N: R65.2; also elsewhere on the board
DB2_P: R65.1; also elsewhere on the board
DB3_N: R66.2; also elsewhere on the board
DB3_P: R66.1; also elsewhere on the board
DB4_N: R67.2; also elsewhere on the board
DB4_P: R67.1; also elsewhere on the board
DB5_N: R68.2; also elsewhere on the board
DB5_P: R68.1; also elsewhere on the board
DB6_N: R69.2; also elsewhere on the board
DB6_P: R69.1; also elsewhere on the board
DB7_N: R70.2; also elsewhere on the board
DB7_P: R70.1; also elsewhere on the board
DB8_N: R71.2; also elsewhere on the board
DB8_P: R71.1; also elsewhere on the board
DB9_N: R72.2; also elsewhere on the board
DB9_P: R72.1; also elsewhere on the board
DB10_N: R73.2; also elsewhere on the board
DB10_P: R73.1; also elsewhere on the board
DB11_N: R74.2; also elsewhere on the board
DB11_P: R74.1; also elsewhere on the board
DBCLK_N: R75.2; also elsewhere on the board
DBCLK_P: R75.1; also elsewhere on the board
DBSTR_N: R76.2; also elsewhere on the board
DBSTR_P: R76.1; also elsewhere on the board
DC0_N: R77.2; also elsewhere on the board
DC0_P: R77.1; also elsewhere on the board
DC1_N: R94.2; also elsewhere on the board
DC1_P: R94.1; also elsewhere on the board
DC2_N: R95.2; also elsewhere on the board
DC2_P: R95.1; also elsewhere on the board
DC3_N: R96.2; also elsewhere on the board
DC3_P: R96.1; also elsewhere on the board
DC4_N: R97.2; also elsewhere on the board
DC4_P: R97.1; also elsewhere on the board
DC5_N: R98.2; also elsewhere on the board
DC5_P: R98.1; also elsewhere on the board
DC6_N: R99.2; also elsewhere on the board
DC6_P: R99.1; also elsewhere on the board
DC7_N: R100.2; also elsewhere on the board
DC7_P: R100.1; also elsewhere on the board
DC8_N: R101.2; also elsewhere on the board
DC8_P: R101.1; also elsewhere on the board
DC9_N: R102.2; also elsewhere on the board
DC9_P: R102.1; also elsewhere on the board
DC10_N: R103.2; also elsewhere on the board
DC10_P: R103.1; also elsewhere on the board
DC11_N: R104.2; also elsewhere on the board
DC11_P: R104.1; also elsewhere on the board
DCCLK_N: R105.2; also elsewhere on the board
DCCLK_P: R105.1; also elsewhere on the board
DCLK: IC6.6 (DCLK); also elsewhere on the board
DCSTR_N: R106.2; also elsewhere on the board
DCSTR_P: R106.1; also elsewhere on the board
DD0_N: R107.2; also elsewhere on the board
DD0_P: R107.1; also elsewhere on the board
DD1_N: R108.2; also elsewhere on the board
DD1_P: R108.1; also elsewhere on the board
DD2_N: R109.2; also elsewhere on the board
DD2_P: R109.1; also elsewhere on the board
DD3_N: R110.2; also elsewhere on the board
DD3_P: R110.1; also elsewhere on the board
DD4_N: R111.2; also elsewhere on the board
DD4_P: R111.1; also elsewhere on the board
DD5_N: R112.2; also elsewhere on the board
DD5_P: R112.1; also elsewhere on the board
DD6_N: R113.2; also elsewhere on the board
DD6_P: R113.1; also elsewhere on the board
DD7_N: R114.2; also elsewhere on the board
DD7_P: R114.1; also elsewhere on the board
DD8_N: R115.2; also elsewhere on the board
DD8_P: R115.1; also elsewhere on the board
DD9_N: R116.2; also elsewhere on the board
DD9_P: R116.1; also elsewhere on the board
DD10_N: R117.2; also elsewhere on the board
DD10_P: R117.1; also elsewhere on the board
DD11_N: R118.2; also elsewhere on the board
DD11_P: R118.1; also elsewhere on the board
DDCLK_N: R119.2; also elsewhere on the board
DDCLK_P: R119.1; also elsewhere on the board
DDSTR_N: R120.2; also elsewhere on the board
DDSTR_P: R120.1; also elsewhere on the board
DEBUGOUT0: R49.P$1; also elsewhere on the board
DEBUGOUT1: R48.P$1; also elsewhere on the board
DEBUGOUT2: R47.P$1; also elsewhere on the board
DEBUGOUT3: R46.P$1; also elsewhere on the board
DEBUGOUT4: J11.1, R37.P$1; also elsewhere on the board
DEBUGOUT5: J11.2, R36.P$1; also elsewhere on the board
DEBUGOUT6: J11.3, R35.P$1; also elsewhere on the board
DEBUGOUT7: J11.4, R34.P$1; also elsewhere on the board
DEBUGOUT8: J11.5, R33.P$1; also elsewhere on the board
DEBUGOUT9: J11.6, R32.P$1; also elsewhere on the board
EXTTRIGIN: EXTTRIGIN.P (ANT), R31.P$2, R160.P$2; also elsewhere on the board
GND: 1KHZOUT50.GND@1 (GND4), 1KHZOUT50.GND@2 (GND3), 1KHZOUT50.GND@3 (GND2), 1KHZOUT50.GND@4 (GND1), C58.1, C59.1, C60.1, C101.1, C102.1, CLKEXT.2, CLKEXT.3 (2), CLKEXT.4 (2), CLKEXT.5 (2), CLKOUT2.2, CLKOUT2.3 (2), CLKOUT2.4 (2), CLKOUT2.5 (2), EXTTRIGIN.GND@1 (GND4), EXTTRIGIN.GND@2 (GND3), EXTTRIGIN.GND@3 (GND2), EXTTRIGIN.GND@4 (GND1), H1.1, H1.2, H2.1, H2.2, IC6.4 (GND), JTAG.2, JTAG.10, LED25.C, LED26.C, LED27.C, LED28.C, LED29.C, LED30.C, LED41.C, LED42.C, LED43.C, LED45.C, LED46.C, LED47.C, LED48.C, R81.P$2, R83.P$2, R85.P$2, R86.P$2, R93.P$1, R136.P$1, R210.P$1, R246.P$1, SW3.4 (B1), SW4.4 (B1), U1.2 (GND), U3.2 (GND), U5.1, U5.2, U$1.S$1 (SHIELD), U$1.S$2 (SHIELD), U$1.S$3 (SHIELD), U$1.S$4 (SHIELD), U$3.S$1 (SHIELD), U$3.S$2 (SHIELD), U$3.S$3 (SHIELD), U$3.S$4 (SHIELD), Y2.2 (GND); also elsewhere on the board
LED0: R53.P$1; also elsewhere on the board
LED1: R52.P$1; also elsewhere on the board
LED2: R51.P$1; also elsewhere on the board
LED3: R50.P$1; also elsewhere on the board
LOCKDETECT: R7.P$1; also elsewhere on the board
LVDSIN_CLK_N: R23.2, U$1.P$8 (8); also elsewhere on the board
LVDSIN_CLK_P: R23.1, U$1.P$7 (7); also elsewhere on the board
LVDSIN_SPARE0_N: R25.2, U$1.P$6 (6); also elsewhere on the board
LVDSIN_SPARE0_P: R25.1, U$1.P$3 (3); also elsewhere on the board
LVDSIN_TRIGB_N: R26.2, U$3.P$5 (5); also elsewhere on the board
LVDSIN_TRIGB_P: R26.1, U$3.P$4 (4); also elsewhere on the board
LVDSIN_TRIG_N: R24.2, U$1.P$2 (2); also elsewhere on the board
LVDSIN_TRIG_P: R24.1, U$1.P$1 (1); also elsewhere on the board
LVDSOUT_CLK_N: U$3.P$8 (8); also elsewhere on the board
LVDSOUT_CLK_P: U$3.P$7 (7); also elsewhere on the board
LVDSOUT_SPARE0_N: U$3.P$6 (6); also elsewhere on the board
LVDSOUT_SPARE0_P: U$3.P$3 (3); also elsewhere on the board
LVDSOUT_TRIGB_N: U$1.P$5 (5); also elsewhere on the board
LVDSOUT_TRIGB_P: U$1.P$4 (4); also elsewhere on the board
LVDSOUT_TRIG_N: U$3.P$2 (2); also elsewhere on the board
LVDSOUT_TRIG_P: U$3.P$1 (1); also elsewhere on the board
MSEL0: R83.P$1; also elsewhere on the board
MSEL1: R84.P$1; also elsewhere on the board
MSEL2: R85.P$1; also elsewhere on the board
MSEL3: R86.P$1; also elsewhere on the board
MUXOUT: R6.P$1; also elsewhere on the board
unnamed: R31.P$1, R136.P$2
unnamed: LED25.A, R37.P$2
unnamed: LED26.A, R36.P$2
unnamed: LED27.A, R35.P$2
unnamed: LED28.A, R34.P$2
unnamed: LED29.A, R33.P$2
unnamed: LED30.A, R32.P$2
unnamed: R160.P$1, R210.P$2
unnamed: LED41.A, R53.P$2
unnamed: LED42.A, R52.P$2
unnamed: LED43.A, R51.P$2
unnamed: R50.P$2, U1.3 (DI)
unnamed: LED45.A, R49.P$2
unnamed: LED46.A, R48.P$2
unnamed: LED47.A, R47.P$2
unnamed: LED48.A, R46.P$2
unnamed: 1KHZOUT50.P (ANT), R211.P$1
unnamed: J11.7, R243.P$2
unnamed: J11.8, R244.P$2
unnamed: R167.P$1, R238.P$1, R246.P$2
unnamed: U1.1 (DO), U3.3 (DI)
NCE: R81.P$1; also elsewhere on the board
NCONFIG: R79.P$1, SW3.2 (A1); also elsewhere on the board
NCSO: IC6.1 (NCS); also elsewhere on the board
NSTATUS: R82.P$1; also elsewhere on the board
OSC_CLK_IN: Y2.3 (OUT); also elsewhere on the board
PG12V: R236.P$1; also elsewhere on the board
RESET_IN: C60.2, R78.P$1, SW4.2 (A1); also elsewhere on the board
SPLIT_CONTROL: R11.P$1; also elsewhere on the board
TCK: JTAG.1, R93.P$2; also elsewhere on the board
TDI: JTAG.9, R92.P$1; also elsewhere on the board
TDO: JTAG.3; also elsewhere on the board
TMS: JTAG.5, R91.P$1; also elsewhere on the board

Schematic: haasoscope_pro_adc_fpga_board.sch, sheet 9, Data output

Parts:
C114, C115, C116, C117, C119, C121, C122, C123, C124, C125: 0.1uF; RESC0402_N
C118, C120, C126: 10uF; RESC0805_N
C127, C128: 16pF; RESC0402_N
FB2: 50mΩ 220Ω@100MHz 0603; 0603
IC8: FT232HQ; QFN48_8MM; JLC_ROTATION 270
IC9: 93LC56B; SOT23-6; LCSC C190271
R27, R38, R121, R123: 10k; RES-0402
R28, R29, R40, R41, R157, R179: 1k; RES-0402
R182, R183: 5.1k; RES-0402
R184: 39; RES-0402
X1: USBC; USB_C_CUSB31-CFM2AX-01-X
Y3: 12MHz; CRYSTAL-SMD-5X3; LCSC C2901628

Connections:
3V3: IC8.32 (ACBUS8), R121.P$2, R123.P$2; also elsewhere on the board
5V: C117.2, IC8.40 (VREGIN); also elsewhere on the board
CC1: R183.P$2, X1.A5 (CC1)
CC2: R182.P$2, X1.B5 (CC2)
FTDI_AC0_RXF: IC8.21 (ACBUS0/TXDEN); also elsewhere on the board
FTDI_AC1_TXE: IC8.25 (ACBUS1); also elsewhere on the board
FTDI_AC2_RD: IC8.26 (ACBUS2); also elsewhere on the board
FTDI_AC3_WR: IC8.27 (ACBUS3/RXLED#); also elsewhere on the board
FTDI_AC4_SIWU: IC8.28 (ACBUS4/TXLED#), R121.P$1
FTDI_AC5_CLK: R184.P$2; also elsewhere on the board
FTDI_AC6_OE: IC8.30 (ACBUS6); also elsewhere on the board
FTDI_AC7_PWRSAV: IC8.31 (ACBUS7), R123.P$1
FTDI_DATA0: IC8.13 (ADBUS0/TXD); also elsewhere on the board
FTDI_DATA1: IC8.14 (ADBUS1/RXD); also elsewhere on the board
FTDI_DATA2: IC8.15 (ADBUS2/RTS#); also elsewhere on the board
FTDI_DATA3: IC8.16 (ADBUS3/CTS#); also elsewhere on the board
FTDI_DATA4: IC8.17 (ADBUS4/DTR#); also elsewhere on the board
FTDI_DATA5: IC8.18 (ADBUS5/DSR#); also elsewhere on the board
FTDI_DATA6: IC8.19 (ADBUS6/DCD#); also elsewhere on the board
FTDI_DATA7: IC8.20 (ADBUS7/RI#); also elsewhere on the board
GND: C114.1, C115.1, C116.1, C117.1, C118.1, C119.1, C120.1, C121.1, C122.1, C123.1, C124.1, C125.1, C126.1, C127.2, C128.2, IC8.4 (AGND), IC8.9 (AGND), IC8.10 (GND), IC8.11 (GND), IC8.22 (GND), IC8.23 (GND), IC8.33 (ACBUS9), IC8.35 (GND), IC8.36 (GND), IC8.41 (AGND), IC8.42 (TEST), IC8.47 (GND), IC8.48 (GND), IC8.THERMAL (PAD), IC9.2 (GND), R41.P$1, R182.P$1, R183.P$1, X1.A1B12 (GND), X1.B1A12 (GND); also elsewhere on the board
unnamed: R27.P$1, R28.P$2
unnamed: R28.P$1, R29.P$2
unnamed: R38.P$1, R40.P$2
unnamed: R40.P$1, R41.P$2
unnamed: R157.P$1, R179.P$2
unnamed: C127.1, IC8.1 (OSCIN), Y3.3 (2)
unnamed: C128.1, IC8.2 (OSCOUT), Y3.1
unnamed: IC8.34 (!RESET), R27.P$2
unnamed: IC8.43 (EEDATA), IC9.3 (DI), R157.P$2
unnamed: IC8.45 (EECS), IC9.5 (CS)
unnamed: IC8.44 (EECLK), IC9.4 (CLK)
unnamed: IC9.1 (DO), R179.P$1
unnamed: IC8.29 (ACBUS5), R184.P$1
REF: IC8.5 (REF), R38.P$2
USB_D_N: IC8.7 (USBD+), X1.A6 (D+), X1.B6 (D+)
USB_D_P: IC8.6 (USBD-), X1.A7 (D-), X1.B7 (D-)
VBUS: C118.2, FB2.1, X1.A4B9 (VBUS), X1.B4A9 (VBUS)
VBUSOUT: C126.2, FB2.2; also elsewhere on the board
VCC1V8: C114.2, IC8.38 (VCCCORE)
VCC3V3: C116.2, C119.2, C120.2, C121.2, C122.2, C123.2, C124.2, C125.2, IC8.3 (VPHY), IC8.8 (VPLL), IC8.12 (VCCIO), IC8.24 (VCCIO), IC8.39 (VCCD), IC8.46 (VCCIO), IC9.6 (VCC), R29.P$1
VCCA_FTDI: C115.2, IC8.37 (VCCA)

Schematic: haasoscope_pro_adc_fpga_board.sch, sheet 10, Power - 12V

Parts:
C81, C166, C290, C291, C292, C293: 22uF; RESC0805_N
C171, C172: 1000uF; EEE0JA152UAP; LCSC C401766
C242, C243, C287, C289, C319, C320, C321, C322: 10uF; RESC0805_N
C283, C318: 0.1uF; RESC0402_N; LCSC C307331
C284, C286: 0.1uF; RESC0402_N
C285: 1uF; RESC0402_N
CN2: 12Vin; DCJACK_2MM_PTH
J30, J45, J46: 2p-2.54; H2-2.54
L2, L14: 10uH; CDRH125; LCSC C339970
LED2, LED3, LED4: red; CHIP-LED0603
PS14: LMR33630ADDA; SOIC127P600X170-9N; LCSC C841384
Q2: FDN340P; SOT-23; MPN P-MOS AO3401A
R148, R151, R212, R234, R239: 10k; RES-0402
R152, R165, R217, R235: 5.1k; RES-0402
R233: 100k; RES-0402
R237: 1k; RES-0402

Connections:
5V: C166.1, C172.1 (+), J45.1, L2.2, R148.P$2; also elsewhere on the board
5VDIRTY: C81.1, C171.1 (+), C286.1, C287.1, C289.1, C290.1, C291.1, C292.1, C293.1, J46.2, L2.1, L14.2, LED3.A, Q2.2 (S), R233.P$2, R237.P$2
12V: C242.1, C283.1, C319.1, C320.1, CN2.PWR, J30.2, LED2.A, PS14.2 (VIN), PS14.3 (EN)
12VCONNECTED: CN2.GNDBREAK, R237.P$1, R239.P$1; also elsewhere on the board
GND: C81.2, C166.2, C171.2 (-), C172.2 (-), C243.2, C285.2, C286.2, C287.2, C289.2, C290.2, C291.2, C292.2, C293.2, C318.2, C321.2, C322.2, CN2.GND, J30.1, J45.2, J46.1, PS14.1 (PGND), PS14.9 (EP), R148.P$1, R152.P$1, R165.P$1, R217.P$1, R235.P$1; also elsewhere on the board
unnamed: R151.P$2, R234.P$1
unnamed: R151.P$1, R152.P$2
unnamed: LED2.C, R217.P$2
unnamed: LED3.C, R235.P$2
unnamed: Q2.1 (G), R239.P$2
unnamed: LED4.C, R165.P$2
unnamed: C242.2, C243.1
unnamed: C284.1, L14.1, PS14.8 (SW)
unnamed: C284.2, PS14.7 (BOOT)
unnamed: PS14.5 (FB), R233.P$1, R234.P$2
unnamed: C285.1, PS14.6 (VCC)
unnamed: C283.2, C318.1
unnamed: C319.2, C321.1
unnamed: C320.2, C322.1
PG12V: PS14.4 (PG), R212.P$2; also elsewhere on the board
VBUSOUT: LED4.A, Q2.3 (D); also elsewhere on the board
VCCIO2V5: R212.P$1; also elsewhere on the board

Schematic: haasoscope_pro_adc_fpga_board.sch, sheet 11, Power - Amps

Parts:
C73, C74, C77, C250, C252, C254, C279, C280, C282: 0.1uF; RESC0402_N
C76, C251, C253, C288: 10uF; RESC0805_N
C83: 1000uF; EEE0JA152UAP; LCSC C401766
C281: 1uF; RESC0402_N
C294, C295, C296, C297: 22uF; RESC0805_N
D10: B340A; SMA-DIODE; LCSC C64982
IC10, IC25: TPS72325DBVR; SOT95P280X145-5N
IC26: TPS7A7200RGTR; QFN50P300X300X100-17N
J4, J34, J35, J44: 2p-2.54; H2-2.54
L13: 10uH; CDRH125; LCSC C339970
PS13: LMR33630ADDA; SOIC127P600X170-9N; LCSC C841384
R209, R231, R232: 100k; RES-0402
R216: 10k; RES-0402

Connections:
2V5+: C253.1, C254.1, IC26.1 (SNS), IC26.15 (OUT_1), IC26.16 (OUT_2), J35.2, R216.P$1; also elsewhere on the board
2V5-1: C251.1, IC25.5 (OUT), J34.1; also elsewhere on the board
2V5-2: C76.1, IC10.5 (OUT), J4.1; also elsewhere on the board
3V0-: C77.1, C83.2 (-), C252.1, C279.2, C281.2, C282.2, C288.2, C294.2, C295.2, C296.2, C297.2, D10.A, IC10.2 (IN), IC25.2 (IN), J44.2, PS13.1 (PGND), PS13.9 (EP), R209.P$1, R232.P$1
3V3: C73.1, IC26.12 (EN), IC26.13 (IN_1), IC26.14 (IN_2); also elsewhere on the board
5V: C279.1, C288.1, PS13.2 (VIN), PS13.3 (EN); also elsewhere on the board
GND: C73.2, C74.2, C76.2, C77.2, C83.1 (+), C250.2, C251.2, C252.2, C253.2, C254.2, C282.1, C294.1, C295.1, C296.1, C297.1, D10.C, IC10.1 (GND), IC25.1 (GND), IC26.7 (GND), IC26.8 (400MV), IC26.10 (1.6V), IC26.17 (EP), J4.2, J34.2, J35.1, J44.1, L13.2, R231.P$2; also elsewhere on the board
unnamed: C74.1, IC10.4 (NR/FB)
unnamed: C250.1, IC25.4 (NR/FB)
unnamed: C280.1, L13.1, PS13.8 (SW)
unnamed: C280.2, PS13.7 (BOOT)
unnamed: PS13.5 (FB), R209.P$2, R231.P$1, R232.P$2
unnamed: C281.1, PS13.6 (VCC)
PG25: IC26.3 (PG), R216.P$2

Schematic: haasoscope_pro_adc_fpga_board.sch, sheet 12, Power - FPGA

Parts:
C52, C170, C173, C257: 10uF; RESC0805_N
C53, C54, C258, C271, C272, C274, C275, C276, C278: 0.1uF; RESC0402_N
C99, C168: 1000uF; EEE0JA152UAP; LCSC C401766
C273, C277: 1uF; RESC0402_N
C298, C299, C300, C301, C302, C303, C304, C305: 22uF; RESC0805_N
IC7, IC28: TPS7A7200RGTR; QFN50P300X300X100-17N
J3, J37, J42, J43: 2p-2.54; H2-2.54
L11, L12: 10uH; CDRH125; LCSC C339970
PS11, PS12: LMR33630ADDA; SOIC127P600X170-9N; LCSC C841384
R137, R227, R229, R230: 100k; RES-0402
R161, R220: 10k; RES-0402
R228: 56k; RES-0402

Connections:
1V2: C52.1, C53.1, IC7.1 (SNS), IC7.15 (OUT_1), IC7.16 (OUT_2), J3.2, R161.P$1; also elsewhere on the board
1V5D: C54.1, C99.1 (+), C278.1, C298.1, C299.1, C300.1, C301.1, IC7.12 (EN), IC7.13 (IN_1), IC7.14 (IN_2), J43.1, L12.2, R229.P$2
2V5D: C257.1, C258.1, IC28.1 (SNS), IC28.15 (OUT_1), IC28.16 (OUT_2), J37.2, R220.P$1; also elsewhere on the board
2V8D: C168.1 (+), C274.1, C302.1, C303.1, C304.1, C305.1, IC28.12 (EN), IC28.13 (IN_1), IC28.14 (IN_2), J42.1, L11.2, R227.P$2
5V: C170.1, C173.1, C271.1, C275.1, PS11.2 (VIN), PS11.3 (EN), PS12.2 (VIN), PS12.3 (EN); also elsewhere on the board
GND: C52.2, C53.2, C54.2, C99.2 (-), C168.2 (-), C170.2, C173.2, C257.2, C258.2, C271.2, C273.2, C274.2, C275.2, C277.2, C278.2, C298.2, C299.2, C300.2, C301.2, C302.2, C303.2, C304.2, C305.2, IC7.5 (100MV), IC7.6 (200MV), IC7.7 (GND), IC7.8 (400MV), IC7.17 (EP), IC28.7 (GND), IC28.8 (400MV), IC28.10 (1.6V), IC28.17 (EP), J3.1, J37.1, J42.2, J43.2, PS11.1 (PGND), PS11.9 (EP), PS12.1 (PGND), PS12.9 (EP), R137.P$1, R228.P$1; also elsewhere on the board
unnamed: R137.P$2, R230.P$1
unnamed: C272.1, L11.1, PS11.8 (SW)
unnamed: C272.2, PS11.7 (BOOT)
unnamed: PS11.5 (FB), R227.P$1, R228.P$2
unnamed: C273.1, PS11.6 (VCC)
unnamed: C276.1, L12.1, PS12.8 (SW)
unnamed: C276.2, PS12.7 (BOOT)
unnamed: PS12.5 (FB), R229.P$1, R230.P$2
unnamed: C277.1, PS12.6 (VCC)
PG1V2: IC7.3 (PG), R161.P$2
PG2V5D: IC28.3 (PG), R220.P$2

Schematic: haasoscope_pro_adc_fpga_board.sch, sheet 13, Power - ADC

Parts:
C100, C165, C167: 1000uF; EEE0JA152UAP; LCSC C401766
C174, C175, C176, C244, C246, C248, C255: 10uF; RESC0805_N
C245, C247, C249, C256, C259, C260, C262, C263, C264, C266, C267, C268, C270: 0.1uF; RESC0402_N
C261, C265, C269: 1uF; RESC0402_N
C306, C307, C308, C309, C310, C311, C312, C313, C314, C315, C316, C317: 22uF; RESC0805_N
IC22, IC23, IC24, IC27: TPS7A7200RGTR; QFN50P300X300X100-17N
J31, J32, J33, J36, J39, J40, J41: 2p-2.54; H2-2.54
L1, L9, L10: 10uH; CDRH125; LCSC C339970
LED1: red; CHIP-LED0603
PS2, PS9, PS10: LMR33630ADDA; SOIC127P600X170-9N; LCSC C841384
R163, R221, R223, R224, R225, R226: 100k; RES-0402
R204, R205: 1M; RES-0402
R213, R214, R215, R219: 10k; RES-0402
R218: 5.1k; RES-0402
R222: 39k; RES-0402

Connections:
1V5: C165.1 (+), C266.1, C310.1, C311.1, C312.1, C313.1, IC24.13 (IN_1), IC24.14 (IN_2), J40.1, L9.2, R223.P$2
2V2: C167.1 (+), C270.1, C306.1, C307.1, C308.1, C309.1, IC23.12 (EN), IC23.13 (IN_1), IC23.14 (IN_2), IC27.12 (EN), IC27.13 (IN_1), IC27.14 (IN_2), J41.1, L10.2, R225.P$2
3V3: C244.1, C245.1, IC22.1 (SNS), IC22.15 (OUT_1), IC22.16 (OUT_2), J31.2, LED1.A, R213.P$1; also elsewhere on the board
3V7: C100.1 (+), C262.1, C314.1, C315.1, C316.1, C317.1, IC22.12 (EN), IC22.13 (IN_1), IC22.14 (IN_2), J39.1, L1.2, R221.P$2
5V: C174.1, C175.1, C176.1, C259.1, C263.1, C267.1, PS2.2 (VIN), PS2.3 (EN), PS9.2 (VIN), PS9.3 (EN), PS10.2 (VIN), PS10.3 (EN); also elsewhere on the board
GND: C100.2 (-), C165.2 (-), C167.2 (-), C174.2, C175.2, C176.2, C244.2, C245.2, C246.2, C247.2, C248.2, C249.2, C255.2, C256.2, C259.2, C261.2, C262.2, C263.2, C265.2, C266.2, C267.2, C269.2, C270.2, C306.2, C307.2, C308.2, C309.2, C310.2, C311.2, C312.2, C313.2, C314.2, C315.2, C316.2, C317.2, IC22.7 (GND), IC22.8 (400MV), IC22.9 (800MV), IC22.10 (1.6V), IC22.17 (EP), IC23.6 (200MV), IC23.7 (GND), IC23.8 (400MV), IC23.9 (800MV), IC23.17 (EP), IC24.6 (200MV), IC24.7 (GND), IC24.8 (400MV), IC24.17 (EP), IC27.6 (200MV), IC27.7 (GND), IC27.8 (400MV), IC27.9 (800MV), IC27.17 (EP), J31.1, J32.1, J33.1, J36.1, J39.2, J40.2, J41.2, PS2.1 (PGND), PS2.9 (EP), PS9.1 (PGND), PS9.9 (EP), PS10.1 (PGND), PS10.9 (EP), R163.P$1, R204.P$1, R205.P$1, R218.P$1, R222.P$1, R226.P$1; also elsewhere on the board
unnamed: R163.P$2, R224.P$1
unnamed: C260.1, L1.1, PS2.8 (SW)
unnamed: C260.2, PS2.7 (BOOT)
unnamed: PS2.5 (FB), R221.P$1, R222.P$2
unnamed: C261.1, PS2.6 (VCC)
unnamed: C264.1, L9.1, PS9.8 (SW)
unnamed: C264.2, PS9.7 (BOOT)
unnamed: PS9.5 (FB), R223.P$1, R224.P$2
unnamed: C265.1, PS9.6 (VCC)
unnamed: C268.1, L10.1, PS10.8 (SW)
unnamed: C268.2, PS10.7 (BOOT)
unnamed: PS10.5 (FB), R204.P$2, R205.P$2, R225.P$1, R226.P$2
unnamed: C269.1, PS10.6 (VCC)
unnamed: LED1.C, R218.P$2
PG1V1: IC24.3 (PG), R215.P$2
PG1V9: IC23.3 (PG), IC24.12 (EN), R214.P$2
PG1V9D: IC27.3 (PG), R219.P$2
PG3V3: IC22.3 (PG), R213.P$2
V11_IN: C248.1, C249.1, IC24.1 (SNS), IC24.15 (OUT_1), IC24.16 (OUT_2), J33.2, R215.P$1; also elsewhere on the board
V19_IN: C246.1, C247.1, IC23.1 (SNS), IC23.15 (OUT_1), IC23.16 (OUT_2), J32.2, R214.P$1; also elsewhere on the board
VLVDS_IN: C255.1, C256.1, IC27.1 (SNS), IC27.15 (OUT_1), IC27.16 (OUT_2), J36.2, R219.P$1; also elsewhere on the board

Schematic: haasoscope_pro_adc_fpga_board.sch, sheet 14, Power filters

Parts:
C5, C15, C25, C35, C45: NFM31PC276B0J3L; NFM31HK103R1H3L
C6, C8, C10, C13, C16, C18, C21, C24, C26, C28, C34, C36, C38, C40, C41, C42, C43, C46, C48: 10uF; RESC0805_N
C7, C9, C12, C17, C19, C20, C23, C27, C29, C31, C33, C37, C39, C47, C49, C61, C62, C63, C64, C65, C66, C67, C68, C69, C70, C71: 0.1uF; RESC0402_N
C11, C14, C22, C30, C32: 1uF; RESC0402_N
R15, R18, R87, R88, R89, R90: 0; RES-0402
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

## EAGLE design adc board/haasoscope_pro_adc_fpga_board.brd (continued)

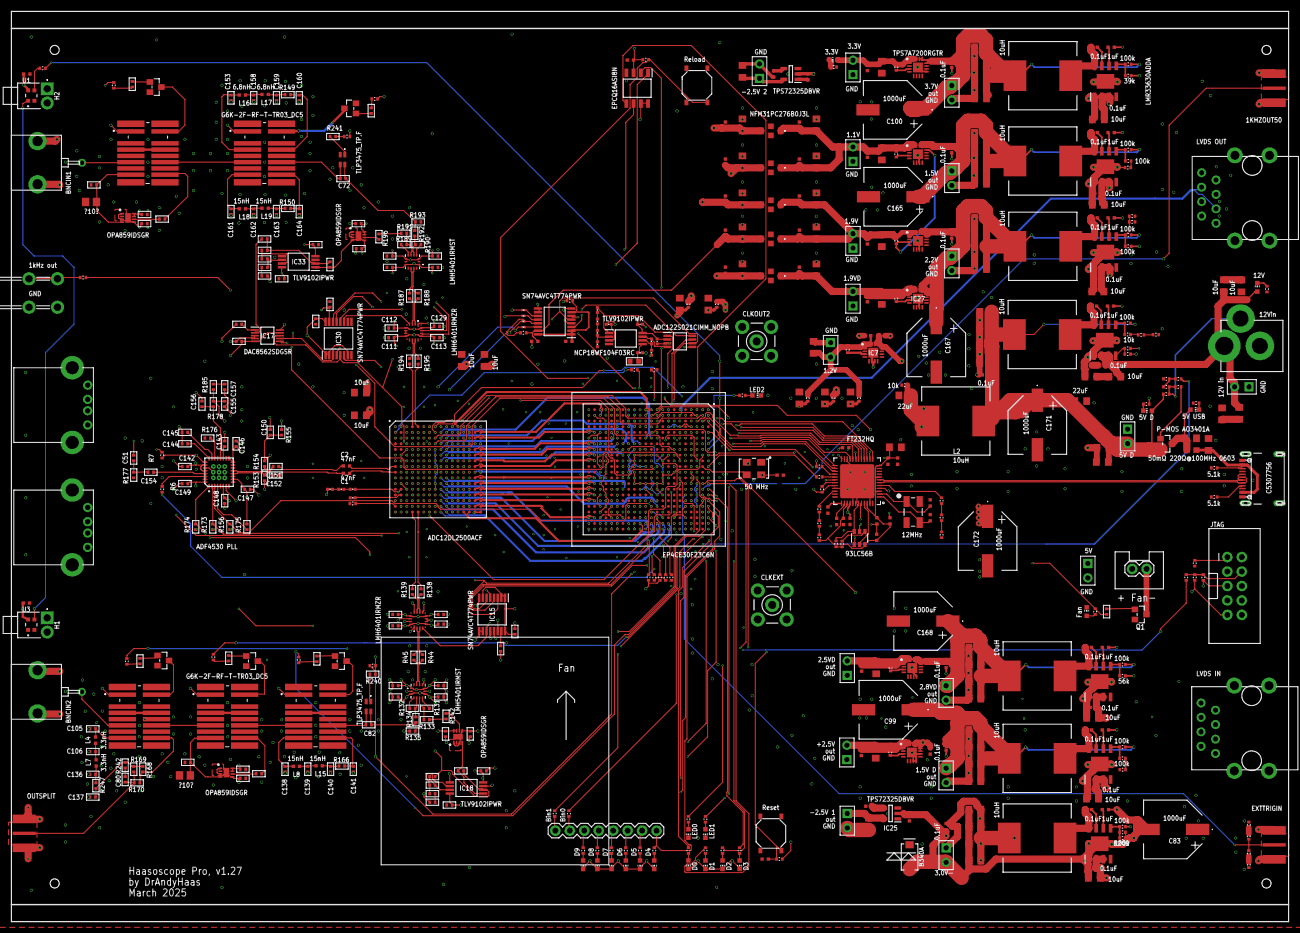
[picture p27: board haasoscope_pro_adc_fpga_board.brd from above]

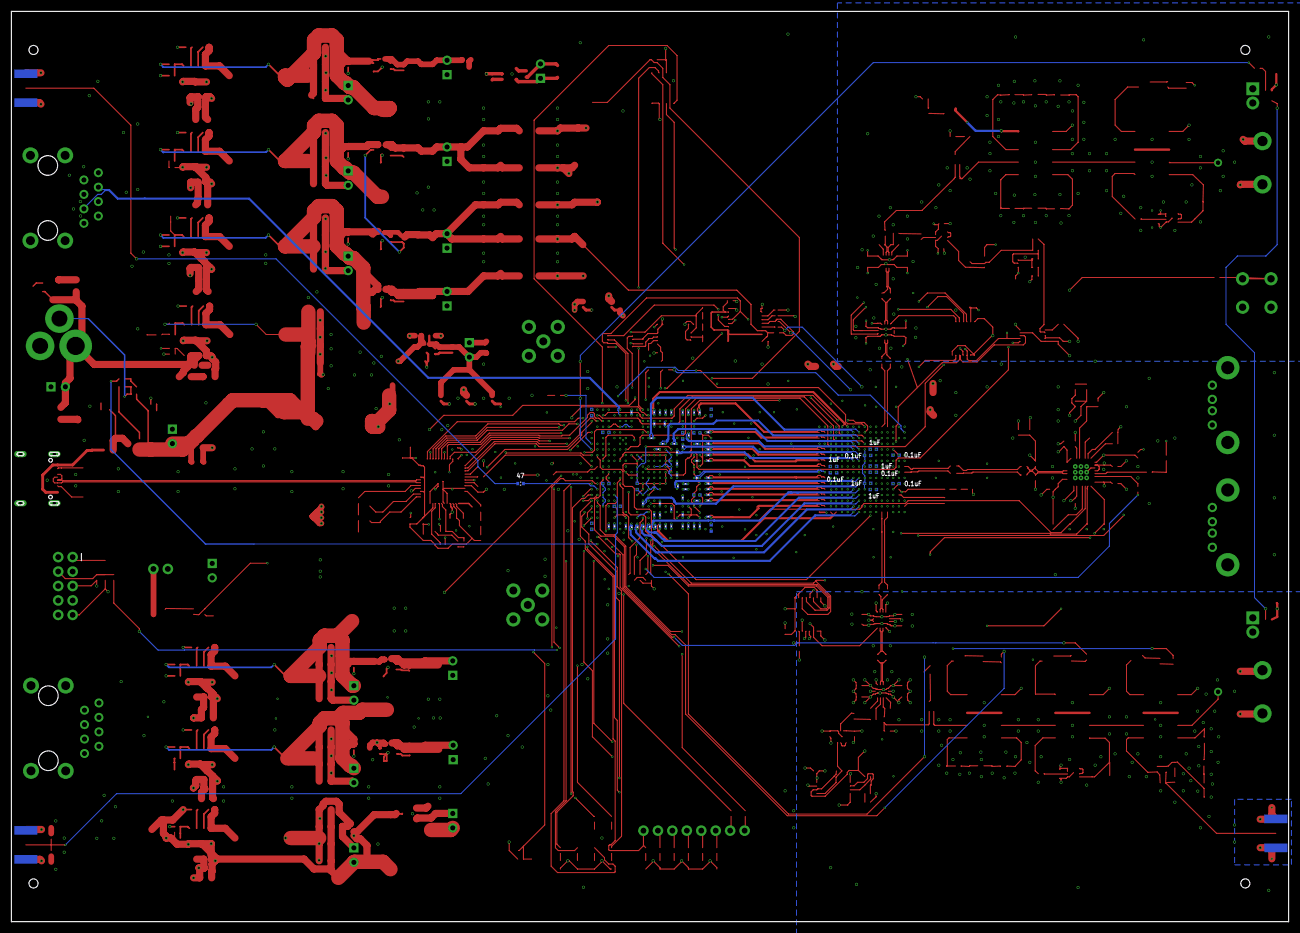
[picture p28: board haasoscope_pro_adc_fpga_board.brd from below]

Board: 10 copper layers, 224.5 x 160.0 mm, 632 parts (82 on the bottom side), 494 nets.

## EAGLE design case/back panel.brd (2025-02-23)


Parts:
C2: 10uF; RESC0805_N
D1: green; LED0805
R1: 3.3k; RES-0402

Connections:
5V: C2.1, D1.ANODE
GND: C2.2, R1.P$1
unnamed: D1.CATHODE, R1.P$2


Board: 2 copper layers, 165.0 x 30.1 mm, 5 parts (3 on the bottom side), 3 nets.

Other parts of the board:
U$1: CE_5MM
U$2: FCC_6.1X16MM

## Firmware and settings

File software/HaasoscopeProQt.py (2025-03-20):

import numpy as np
import sys, time, warnings
import pyqtgraph as pg
import PyQt5
from pyqtgraph.Qt import QtCore, QtWidgets, loadUiType
from PyQt5.QtGui import QPalette, QColor
from scipy.optimize import curve_fit
from scipy.signal import resample
from usbs import *
from board import *

usbs = connectdevices()
if len(usbs)==0: sys.exit(0)
for b in range(len(usbs)):
    version(usbs[b])
    version(usbs[b])
    version(usbs[b])
usbs = orderusbs(usbs)

# Define fft window class from template
FFTWindowTemplate, FFTTemplateBaseClass = loadUiType("HaasoscopeProFFT.ui")
class FFTWindow(FFTTemplateBaseClass):
    def __init__(self):
        FFTTemplateBaseClass.__init__(self)
        self.ui = FFTWindowTemplate()
        self.ui.setupUi(self)
        self.ui.plot.setLabel('bottom', 'Frequency (MHz)')
        self.ui.plot.setLabel('left', 'Amplitude')
        self.ui.plot.showGrid(x=True, y=True, alpha=1.0)
        #self.ui.plot.setRange(xRange=(0.0, 1600.0))
        self.ui.plot.setBackground('w')
        c = (10, 10, 10)
        self.fftpen = pg.mkPen(color=c)  # add linewidth=0.5, alpha=.5
        self.fftline = self.ui.plot.plot(pen=self.fftpen, name="fft_plot")
        self.fftlastTime = time.time() - 10
        self.fftyrange = 1

# Define main window class from template
WindowTemplate, TemplateBaseClass = loadUiType("HaasoscopePro.ui")
class MainWindow(TemplateBaseClass):

    expect_samples = 100
    expect_samples_extra = 5 # enough to cover downsample shifting and toff shifting
    samplerate = 3.2  # freq in GHz
    nsunits = 1
    num_board = len(usbs)
    num_chan_per_board = 2
    num_logic_inputs = 0
    tenx = 1
    debug = False
    dopattern = 0 # set to 4 to do max varying test pattern
    debugprint = True
    showbinarydata = True
    debugstrobe = False
    dofast = False
    dotwochannel = False
    dointerleaved = False
    dooverrange = False
    total_rx_len = 0
    time_start = time.time()
    triggertype = 1
    isrolling = 0
    selectedchannel = 0
    activeusb = usbs[0]
    activeboard = 0
    activexychannel = 0
    tad = 0
    toff = 0
    themuxoutV = True
    phasecs = []
    for ph in range(len(usbs)): phasecs.append([[0, 0, 0, 0, 0], [0, 0, 0, 0, 0], [0, 0, 0, 0, 0], [0, 0, 0, 0, 0]])
    pll_test_c2phase = 5
    pll_test_c2phase_down = 2
    doexttrig = [0] * num_board
    paused = True # will unpause with dostartstop at startup
    downsample = 0
    downsamplefactor = 1
    highresval = 1
    xscale = 1
    xscaling = 1
    yscale = 3.3/2.03 * 10*5/8 / pow(2,12) # this is the size of 1 bit, so that 2^12 bits fill the 10.x divisions on the screen
    min_y = -5 # -pow(2, 11) * yscale
    max_y = 5 # pow(2, 11) * yscale
    min_x = 0
    max_x = 4 * 10 * expect_samples * downsamplefactor / nsunits / samplerate
    xydata = 0
    xydatainterleaved = 0
    fftui = 0
    downsamplezoom = 1
    triggerlevel = 127
    triggerdelta = 1
    triggerpos = int(expect_samples * 128 / 256)
    triggertimethresh = 0
    triggerchan = 0
    hline = 0
    vline = 0
    getone = False
    downsamplemerging = 1
    units = "ns"
    dodrawing = True
    chtext = ""
    linepens = []
    nlines = 0
    statuscounter = 0
    nevents = 0
    oldnevents = 0
    tinterval = 100.
    oldtime = time.time()
    nbadclkA = 0
    nbadclkB = 0
    nbadclkC = 0
    nbadclkD = 0
    nbadstr = 0
    eventcounter = [0] * num_board
    nsubsamples = 10 * 4 + 8 + 2  # extra 4 for clk+str, and 2 dead beef
    sample_triggered = [0] * num_board
    doeventcounter = False
    fitwidthfraction = 0.2
    extrigboardstdcorrection = 1
    extrigboardmeancorrection = 0
    lastrate = 0
    lastsize = 0
    VperD = [0.16]*(num_board*2)
    plljustreset = [0] * num_board
    dooversample = False
    doresamp = 0

    def __init__(self):
        TemplateBaseClass.__init__(self)
        self.ui = WindowTemplate()
        self.ui.setupUi(self)
        self.ui.runButton.clicked.connect(self.dostartstop)
        self.ui.threshold.valueChanged.connect(self.triggerlevelchanged)
        self.ui.thresholdDelta.valueChanged.connect(self.triggerdeltachanged)
        self.ui.thresholdPos.valueChanged.connect(self.triggerposchanged)
        self.ui.rollingButton.clicked.connect(self.rolling)
        self.ui.singleButton.clicked.connect(self.single)
        self.ui.timeslowButton.clicked.connect(self.timeslow)
        self.ui.timefastButton.clicked.connect(self.timefast)
        self.ui.risingedgeCheck.stateChanged.connect(self.risingfalling)
        self.ui.exttrigCheck.stateChanged.connect(self.exttrig)
        self.ui.totBox.valueChanged.connect(self.tot)
        self.ui.depthBox.valueChanged.connect(self.depth)
        self.ui.boardBox.valueChanged.connect(self.boardchanged)
        self.ui.triggerChanBox.valueChanged.connect(self.triggerchanchanged)
        self.ui.gridCheck.stateChanged.connect(self.grid)
        self.ui.markerCheck.stateChanged.connect(self.marker)
        self.ui.highresCheck.stateChanged.connect(self.highres)
        self.ui.pllresetButton.clicked.connect(self.pllreset)
        self.ui.adfresetButton.clicked.connect(self.adfreset)
        self.ui.upposButton0.clicked.connect(self.uppos)
        self.ui.downposButton0.clicked.connect(self.downpos)
        self.ui.upposButton1.clicked.connect(self.uppos1)
        self.ui.downposButton1.clicked.connect(self.downpos1)
        self.ui.upposButton2.clicked.connect(self.uppos2)
        self.ui.downposButton2.clicked.connect(self.downpos2)
        self.ui.upposButton3.clicked.connect(self.uppos3)
        self.ui.downposButton3.clicked.connect(self.downpos3)
        self.ui.upposButton4.clicked.connect(self.uppos4)
        self.ui.downposButton4.clicked.connect(self.downpos4)
        self.ui.chanBox.valueChanged.connect(self.selectchannel)
        self.ui.gainBox.valueChanged.connect(self.changegain)
        self.ui.offsetBox.valueChanged.connect(self.changeoffset)
        self.ui.acdcCheck.stateChanged.connect(self.setacdc)
        self.ui.ohmCheck.stateChanged.connect(self.setohm)
        self.ui.oversampCheck.stateChanged.connect(self.setoversamp)
        self.ui.interleavedCheck.stateChanged.connect(self.interleave)
        self.ui.attCheck.stateChanged.connect(self.setatt)
        self.ui.tenxCheck.stateChanged.connect(self.settenx)
        self.ui.chanonCheck.stateChanged.connect(self.chanon)
        self.ui.drawingCheck.clicked.connect(self.drawing)
        self.ui.fwfBox.valueChanged.connect(self.fwf)
        self.ui.tadBox.valueChanged.connect(self.setTAD)
        self.ui.resampBox.valueChanged.connect(self.resamp)
        self.ui.twochanCheck.clicked.connect(self.twochan)
        self.ui.ToffBox.valueChanged.connect(self.setToff)
        self.ui.fftCheck.clicked.connect(self.fft)
        self.ui.actionDo_autocalibration.triggered.connect(self.actionDo_autocalibration)
        self.dofft = False
        self.db = False
        self.lastTime = time.time()
        self.fps = None
        self.lines = []
        self.otherlines = []
        self.savetofile = False  # save scope data to file
        self.doh5 = False  # use the h5 binary file format
        self.numrecordeventsperfile = 1000  # number of events in each file to record before opening new file
        self.timer = QtCore.QTimer()
        # noinspection PyUnresolvedReferences
        self.timer.timeout.connect(self.updateplot)
        self.timer2 = QtCore.QTimer()
        # noinspection PyUnresolvedReferences
        self.timer2.timeout.connect(self.drawtext)
        self.ui.statusBar.showMessage("Hello!")
        self.ui.plot.setBackground('w')
        self.show()

    def boardchanged(self):
        self.activeusb = usbs[self.ui.boardBox.value()]
        self.activeboard = self.ui.boardBox.value()
        self.selectchannel()

    def selectchannel(self):
        if self.activeboard%2==0:
            self.ui.exttrigCheck.setEnabled(False)
            self.ui.oversampCheck.setEnabled(True)
            if self.dooversample: self.ui.interleavedCheck.setEnabled(True)
        else:
            self.ui.exttrigCheck.setEnabled(True)
            self.ui.oversampCheck.setEnabled(False)
            self.ui.interleavedCheck.setEnabled(False)
        if self.doexttrig[self.activeboard]: self.ui.exttrigCheck.setChecked(True)
        else: self.ui.exttrigCheck.setChecked(False)
        self.selectedchannel = self.ui.chanBox.value()
        self.activexychannel = self.activeboard*self.num_chan_per_board + self.selectedchannel
        p = self.ui.chanColor.palette()
        col = QColor("red")
        if self.activexychannel==1: col = QColor("green")
        if self.activexychannel==2: col = QColor("blue")
        if self.activexychannel==3: col = QColor("magenta")
        if self.activexychannel>=4: print("Not ready for >2 boards yet!")
        p.setColor(QPalette.Base, col)  # Set background color of box
        self.ui.chanColor.setPalette(p)
        if self.lines[self.activexychannel].isVisible():
            self.ui.chanonCheck.setCheckState(QtCore.Qt.Checked)
        else:
            self.ui.chanonCheck.setCheckState(QtCore.Qt.Unchecked)

    def fft(self):
        if self.ui.fftCheck.checkState() == QtCore.Qt.Checked:
            self.fftui = FFTWindow()
            self.fftui.setWindowTitle('Haasoscope Pro FFT of board '+str(self.activeboard)+' channel ' + str(self.selectedchannel))
            self.fftui.show()
            self.dofft = True
        else:
            self.fftui.close()
            self.dofft = False

    def resamp(self, value):
        self.doresamp = value

    def twochan(self):
        self.dotwochannel = self.ui.twochanCheck.checkState() == QtCore.Qt.Checked
        self.setupchannels()
        self.doleds()
        for usb in usbs: setupboard(usb,self.dopattern,self.dotwochannel,self.dooverrange)
        for usb in usbs: self.telldownsample(usb, self.downsample)
        self.timechanged()
        if self.dotwochannel:
            self.ui.chanBox.setMaximum(self.num_chan_per_board - 1)
            self.ui.oversampCheck.setEnabled(False)
        else:
            self.ui.chanBox.setMaximum(0)
            self.ui.oversampCheck.setEnabled(True)
        for c in range(self.num_board*self.num_chan_per_board):
            if c%2==1:
                if self.dotwochannel: self.lines[c].setVisible(True)
                else: self.lines[c].setVisible(False)

    def changeoffset(self):
        scaling = 1000*self.VperD[self.activeboard*2+self.selectedchannel]/160 # compare to 0 dB gain
        if dooffset(self.activeusb, self.selectedchannel, self.ui.offsetBox.value(),scaling/self.tenx,self.dooversample):
            if self.dooversample and self.ui.boardBox.value()%2==0: # also adjust other board we're oversampling with
                dooffset(usbs[self.ui.boardBox.value()+1], self.selectedchannel, self.ui.offsetBox.value(),scaling/self.tenx,self.dooversample)
            v2 = scaling*1.5*self.ui.offsetBox.value()
            if self.dooversample: v2 *= 2.0
            self.ui.Voff.setText(str(int(v2))+" mV")

    def changegain(self):
        setgain(self.activeusb, self.selectedchannel, self.ui.gainBox.value(),self.dooversample)
        if self.dooversample and self.ui.boardBox.value()%2==0: # also adjust other board we're oversampling with
            setgain(usbs[self.ui.boardBox.value()+1], self.selectedchannel, self.ui.gainBox.value(),self.dooversample)
        db = self.ui.gainBox.value()
        v2 = 0.1605*self.tenx/pow(10, db / 20.) # 0.16 V at 0 dB gain
        if self.dooversample: v2 *= 2.0
        oldvperd = self.VperD[self.activeboard*2+self.selectedchannel]
        self.VperD[self.activeboard*2+self.selectedchannel] = v2
        if self.dooversample and self.ui.boardBox.value()%2==0: # also adjust other board we're oversampling with
            self.VperD[(self.activeboard+1)*2+self.selectedchannel] = v2
        self.ui.offsetBox.setValue(int(self.ui.offsetBox.value()*oldvperd/v2))
        v2 = round(1000*v2,0)
        self.ui.VperD.setText(str(int(v2))+" mV/div")
        if self.ui.gainBox.value()>24: self.ui.gainBox.setSingleStep(2)
        else: self.ui.gainBox.setSingleStep(6)

    def fwf(self):
        self.fitwidthfraction = self.ui.fwfBox.value() / 100.

    def setTAD(self):
        if self.tad<0 and self.ui.tadBox.value()>=0:
            spicommand(self.activeusb, "TAD", 0x02, 0xB7, 0, False, quiet=False)
        if self.tad>=0 and self.ui.tadBox.value()<0:
            spicommand(self.activeusb, "TAD", 0x02, 0xB7, 1, False, quiet=False)
        self.tad = self.ui.tadBox.value()
        spicommand(self.activeusb, "TAD", 0x02, 0xB6, abs(self.tad), False, quiet=True)

    def setToff(self):
        self.toff = self.ui.ToffBox.value()

    def adfreset(self, board):
        if not board: board=self.activeboard # if called by pressing button
        usb = usbs[board]
        # adf4350(150.0, None, 10) # need larger rcounter for low freq
        adf4350(usb, self.samplerate * 1000 / 2, None, themuxout=self.themuxoutV)
        time.sleep(0.1)
        res = boardinbits(usb)
        if not getbit(res, 0): print("Adf pll for board",board,"not locked?")  # should be 1 if locked
        else: print("Adf pll locked for board",board)

    def chanon(self):
        if self.ui.chanonCheck.checkState() == QtCore.Qt.Checked:
            self.lines[self.activexychannel].setVisible(True)
        else:
            self.lines[self.activexychannel].setVisible(False)

    def setacdc(self):
        setchanacdc(self.activeusb, self.selectedchannel,
                    self.ui.acdcCheck.checkState() == QtCore.Qt.Checked, self.dooversample)  # will be True for AC, False for DC
        if self.dooversample and self.ui.boardBox.value() % 2 == 0:  # also adjust other board we're oversampling with
            setchanacdc(usbs[self.ui.boardBox.value()+1], self.selectedchannel,
                    self.ui.acdcCheck.checkState() == QtCore.Qt.Checked, self.dooversample)

    def setohm(self):
        setchanimpedance(self.activeusb, self.selectedchannel,
                         self.ui.ohmCheck.checkState() == QtCore.Qt.Checked, self.dooversample)  # will be True for 1M ohm, False for 50 ohm

    def setatt(self):
        setchanatt(self.activeusb, self.selectedchannel,
                   self.ui.attCheck.checkState() == QtCore.Qt.Checked, self.dooversample)  # will be True for attenuation on

    def settenx(self):
        if self.ui.tenxCheck.checkState() == QtCore.Qt.Checked:
            self.tenx = 10
        else:
            self.tenx = 1
        self.changegain()

    def setoversamp(self):
        self.dooversample = self.ui.oversampCheck.checkState() == QtCore.Qt.Checked # will be True for oversampling, False otherwise
        setsplit(self.activeusb,self.dooversample)
        setsplit(usbs[self.activeboard+1], False)
        for usb in usbs: swapinputs(usb,self.dooversample)
        if self.dooversample:
            self.ui.interleavedCheck.setEnabled(True)
            self.ui.twochanCheck.setEnabled(False)
        else:
            self.ui.interleavedCheck.setEnabled(False)
            self.ui.interleavedCheck.setChecked(False)
            self.ui.twochanCheck.setEnabled(True)
        self.changegain()
        self.changeoffset()
        self.doleds()

    def interleave(self):
        self.dointerleaved = self.ui.interleavedCheck.checkState() == QtCore.Qt.Checked
        c = (self.activeboard+1) * self.num_chan_per_board
        if self.dointerleaved:
            self.lines[c].setVisible(False)
            self.ui.boardBox.setMaximum(int(self.num_board/2)-1)
        else:
            self.lines[c].setVisible(True)
            self.ui.boardBox.setMaximum(self.num_board-1)
        self.selectchannel()
        self.timechanged()
        self.doleds()

    def dophase(self, board, plloutnum, updown, pllnum=None, quiet=False):
        # for 3rd byte, 000:all 001:M 010=2:C0 011=3:C1 100=4:C2 101=5:C3 110=6:C4
        # for 4th byte, 1 is up, 0 is down
        if pllnum is None: pllnum = int(self.ui.pllBox.value())
        usbs[board].send(bytes([6, pllnum, int(plloutnum + 2), updown, 100, 100, 100, 100]))
        if updown:
            self.phasecs[board][pllnum][plloutnum] = self.phasecs[board][pllnum][plloutnum] + 1
        else:
            self.phasecs[board][pllnum][plloutnum] = self.phasecs[board][pllnum][plloutnum] - 1
        if not quiet: print("phase for pllnum", pllnum, "plloutnum", plloutnum, "on board", board, "now",
                            self.phasecs[board][pllnum][plloutnum])

    def uppos(self):
        self.dophase(self.activeboard, plloutnum=0, updown=1)

    def uppos1(self):
        self.dophase(self.activeboard, plloutnum=1, updown=1)

    def uppos2(self):
        self.dophase(self.activeboard, plloutnum=2, updown=1)

    def uppos3(self):
        self.dophase(self.activeboard, plloutnum=3, updown=1)

    def uppos4(self):
        self.dophase(self.activeboard, plloutnum=4, updown=1)

    def downpos(self):
        self.dophase(self.activeboard, plloutnum=0, updown=0)

    def downpos1(self):
        self.dophase(self.activeboard, plloutnum=1, updown=0)

    def downpos2(self):
        self.dophase(self.activeboard, plloutnum=2, updown=0)

    def downpos3(self):
        self.dophase(self.activeboard, plloutnum=3, updown=0)

    def downpos4(self):
        self.dophase(self.activeboard, plloutnum=4, updown=0)

    def pllreset(self, board):
        if not board: board = self.activeboard # if we called it from the button
        usbs[board].send(bytes([5, 99, 99, 99, 100, 100, 100, 100]))
        tres = usbs[board].recv(4)
        print("pllreset sent to board",board,"- got back:", tres[3], tres[2], tres[1], tres[0])
        self.phasecs[board] = [[0, 0, 0, 0, 0], [0, 0, 0, 0, 0], [0, 0, 0, 0, 0], [0, 0, 0, 0, 0]]  # reset counters
        # adjust phases (intentionally put to a place where the clockstr may be bad, it'll get adjusted by 90 deg later, and then dropped to a good range)
        n = self.pll_test_c2phase  # amount to adjust (+ or -)
        for i in range(abs(n)): self.dophase(board, 2, n > 0, pllnum=0, quiet=(i != abs(n) - 1))  # adjust phase of c2, clkout
        n = -1  # amount to adjust (+ or -)
        for i in range(abs(n)): self.dophase(board, 3, n > 0, pllnum=0, quiet=(i != abs(n) - 1))  # adjust phase of c3
        n = 0  # amount to adjust (+ or -)
        for i in range(abs(n)): self.dophase(board, 4, n > 0, pllnum=0, quiet=(i != abs(n) - 1))  # adjust phase of c4
        self.plljustreset[board] = 3 # get a few events
        switchclock(usbs,board)

    def adjustclocks(self, board, nbadclkA, nbadclkB, nbadclkC, nbadclkD, nbadstr):
        if (nbadclkA+nbadclkB+nbadclkC+nbadclkD+nbadstr>4) and self.phasecs[board][0][2] < 20:  # adjust phase by 90 deg
            n = 6  # amount to adjust clkout (positive)
            for i in range(n): self.dophase(board, 2, 1, pllnum=0, quiet=(i != n - 1))  # adjust phase of clkout
        if self.plljustreset[board]>0: self.plljustreset[board] -= 1 # count down while collecting events
        if self.plljustreset[board]==1: # adjust back down to a good range after detecting that it needs to be shifted by 90 deg or not
            n = self.pll_test_c2phase_down  # amount to adjust clkout (negative)
            for i in range(n): self.dophase(board, 2, 0, pllnum=0, quiet=(i != n - 1))  # adjust phase of clkout

    def wheelEvent(self, event):  # QWheelEvent
        if hasattr(event, "delta"):
            if event.delta() > 0:
                self.uppos()
            else:
                self.downpos()
        elif hasattr(event, "angleDelta"):
            if event.angleDelta() > 0:
                self.uppos()
            else:
                self.downpos()

    def keyPressEvent(self, event):
        if event.key() == QtCore.Qt.Key_Up: self.uppos()
        if event.key() == QtCore.Qt.Key_Down: self.downpos()
        if event.key() == QtCore.Qt.Key_Left: self.timefast()
        if event.key() == QtCore.Qt.Key_Right: self.timeslow()
        # modifiers = QtWidgets.QApplication.keyboardModifiers()

    def exttrig(self, value):
        board = self.ui.boardBox.value()
        self.doexttrig[board] = value
        self.ui.exttrigCheck.setChecked(value)
        #print("doexttrig", self.doexttrig[board], "for board", board)
        r = self.ui.rollingButton.isChecked()
        if self.doexttrig[board]: r = False
        print("setting rolling",r,"for board",board)
        usbs[board].send(bytes([2, 8, r, 0, 100, 100, 100, 100]))
        usbs[board].recv(4)

    def grid(self):
        if self.ui.gridCheck.isChecked():
            self.ui.plot.showGrid(x=True, y=True)
        else:
            self.ui.plot.showGrid(x=False, y=False)

    def marker(self):
        if self.ui.markerCheck.isChecked():
            for li in range(self.nlines):
                self.lines[li].setSymbol("o")
                self.lines[li].setSymbolSize(3)
                # self.lines[li].setSymbolPen("black")
                self.lines[li].setSymbolPen(self.linepens[li].color())
                self.lines[li].setSymbolBrush(self.linepens[li].color())
        else:
            for li in range(self.nlines):
                self.lines[li].setSymbol(None)

    def dostartstop(self):
        if self.paused:
            self.timer.start(0)
            self.timer2.start(1000)
            self.paused = False
            self.ui.runButton.setChecked(True)
        else:
            self.timer.stop()
            self.timer2.stop()
            self.paused = True
            self.ui.runButton.setChecked(False)

    def triggerlevelchanged(self, value):
        if value + self.triggerdelta < 256 and value - self.triggerdelta > 0:
            self.triggerlevel = value
            for usb in usbs: self.sendtriggerinfo(usb)
            self.drawtriggerlines()
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

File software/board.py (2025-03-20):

import time
from spi import *
from utils import *
from adf435x_core import *

def adf4350(usb, freq, phase, r_counter=1, divided=FeedbackSelect.Divider, ref_doubler=False, ref_div2=True, themuxout=False):
    print('ADF4350 being set to %0.2f MHz' % freq)
    INT, MOD, FRAC, output_divider, band_select_clock_divider = (calculate_regs(
        device_type=DeviceType.ADF4350, freq=freq, ref_freq=50.0,
        band_select_clock_mode=BandSelectClockMode.Low,
        feedback_select=divided,
        r_counter=r_counter,  # needed when using FeedbackSelect.Divider (needed for phase resync?!)
        ref_doubler=ref_doubler, ref_div2=ref_div2, enable_gcd=True))
    print("INT", INT, "MOD", MOD, "FRAC", FRAC, "outdiv", output_divider, "bandselclkdiv", band_select_clock_divider)
    regs = make_regs(
        INT=INT, MOD=MOD, FRAC=FRAC, output_divider=output_divider,
        band_select_clock_divider=band_select_clock_divider, r_counter=r_counter, ref_doubler=ref_doubler,
        ref_div_2=ref_div2,
        device_type=DeviceType.ADF4350, phase_value=phase, mux_out=themuxout, charge_pump_current=2.50,
        feedback_select=divided, pd_polarity=PDPolarity.Positive, prescaler='4/5',
        band_select_clock_mode=BandSelectClockMode.Low,
        clk_div_mode=ClkDivMode.ResyncEnable, clock_divider_value=1000, csr=False,
        aux_output_enable=False, aux_output_power=-4.0, output_enable=True, output_power=-4.0)  # (-4,-1,2,5)
    # values can also be computed using free Analog Devices ADF435x Software:
    # https://www.analog.com/en/resources/evaluation-hardware-and-software/evaluation-boards-kits/eval-adf4351.html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
    spimode(usb, 0)
    for r in reversed(range(len(regs))):
        # regs[2]=0x5004E42 #to override from ADF435x software
        print("adf4350 reg", r, binprint(regs[r]), hex(regs[r]))
        fourbytes = inttobytes(regs[r])
        # for i in range(4): print(binprint(fourbytes[i]))
        spicommand(usb, "ADF4350 Reg " + str(r), fourbytes[3], fourbytes[2], fourbytes[1], False, fourth=fourbytes[0],
                   cs=3, nbyte=4)  # was cs=2 on alpha board v1.11
    spimode(usb, 0)

def swapinputs(usb,doswap,insetup=False):
    if not insetup:
        spicommand(usb, "LVDS_EN", 0x02, 0x00, 0x00, False)  # disable LVDS interface
        spicommand(usb, "CAL_EN", 0x00, 0x61, 0x00, False)  # disable calibration
    if doswap: spicommand(usb, "INPUT_MUX", 0x00, 0x60, 0x12, False)  # swap inputs
    else: spicommand(usb, "INPUT_MUX", 0x00, 0x60, 0x01, False)  # unswap inputs
    if not insetup:
        spicommand(usb, "CAL_EN", 0x00, 0x61, 0x01, False)  # enable calibration
        spicommand(usb, "LVDS_EN", 0x02, 0x00, 0x01, False)  # enable LVDS interface

def setupboard(usb, dopattern, twochannel, dooverrange):
    setfan(usb, 1)

    spimode(usb, 0)
    spicommand(usb, "DEVICE_CONFIG", 0x00, 0x02, 0x00, False)  # power up
    # spicommand(usb, "DEVICE_CONFIG", 0x00, 0x02, 0x03, False) # power down
    spicommand2(usb, "VENDOR", 0x00, 0x0c, 0x00, 0x00, True)
    spicommand(usb, "LVDS_EN", 0x02, 0x00, 0x00, False)  # disable LVDS interface
    spicommand(usb, "CAL_EN", 0x00, 0x61, 0x00, False)  # disable calibration

    if twochannel:
        spicommand(usb, "LMODE", 0x02, 0x01, 0x03, False)  # LVDS mode: aligned, demux, dual channel, 12-bit
        # spicommand("LMODE", 0x02, 0x01, 0x01, False)  # LVDS mode: staggered, demux, dual channel, 12-bit
    else:
        spicommand(usb, "LMODE", 0x02, 0x01, 0x07, False)  # LVDS mode: aligned, demux, single channel, 12-bit
        # spicommand(usb, "LMODE", 0x02, 0x01, 0x37, False)  # LVDS mode: aligned, demux, single channel, 8-bit
        # spicommand(usb, "LMODE", 0x02, 0x01, 0x05, False)  # LVDS mode: staggered, demux, single channel, 12-bit

    spicommand(usb, "LVDS_SWING", 0x00, 0x48, 0x00, False)  # high swing mode
    # spicommand(usb, "LVDS_SWING", 0x00, 0x48, 0x01, False)  #low swing mode

    spicommand(usb, "LCTRL", 0x02, 0x04, 0x0a, False)  # use LSYNC_N (software), 2's complement
    # spicommand(usb, "LCTRL", 0x02, 0x04, 0x08, False)  # use LSYNC_N (software), offset binary

    swapinputs(usb,False, True)

    # spicommand(usb, "TAD", 0x02, 0xB7, 0x01, False)  # invert clk
    spicommand(usb, "TAD", 0x02, 0xB7, 0x00, False)  # don't invert clk

    tad=0
    spicommand(usb, "TAD", 0x02, 0xB6, tad, False)  # adjust TAD (time of ADC relative to clk)

    if dooverrange:
        spicommand(usb, "OVR_CFG", 0x02, 0x13, 0x0f, False)  # overrange on
        spicommand(usb, "OVR_T0", 0x02, 0x11, 0xf2, False)  # overrange threshold 0
        spicommand(usb, "OVR_T1", 0x02, 0x12, 0xab, False)  # overrange threshold 1
    else:
        spicommand(usb, "OVR_CFG", 0x02, 0x13, 0x07, False)  # overrange off
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

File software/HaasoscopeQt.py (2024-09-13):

import numpy as np
import sys, time
import pyqtgraph as pg
from ftd2xx import DeviceError
from pyqtgraph.Qt import QtCore, QtWidgets, loadUiType

from USB_FTX232H_FT60X import USB_FTX232H_FT60X_sync245mode # see USB_FTX232H_FT60X.py

# https://github.com/drandyhaas/pyadf435x
from adf435x import calculate_regs, make_regs, DeviceType, MuxOut, ClkDivMode, BandSelectClockMode, FeedbackSelect, PDPolarity

usb = USB_FTX232H_FT60X_sync245mode(device_to_open_list=(('FTX232H','HaasoscopePro USB2'),('FT60X','Haasoscope USB3')))

def binprint(x):
    return bin(x)[2:].zfill(8)

def getbit(i, n):
    return (i >> n) & 1
def oldbytes():
    while True:
        olddata = usb.recv(10000000)
        print("Got",len(olddata),"old bytes")
        if len(olddata)==0: break
        print("Old byte0:",olddata[0])

def inttobytes(theint): #convert length number to a 4-byte byte array (with type of 'bytes')
    return [theint & 0xff, (theint >> 8) & 0xff, (theint >> 16) & 0xff, (theint >> 24) & 0xff]
def spicommand(name, first, second, third, read, fourth=100, show_bin=False, cs=0, nbyte=3):
    # first byte to send, start of address
    # second byte to send, rest of address
    # third byte to send, value to write, ignored during read
    # cs is which chip to select, adc 0 by default
    # nbyte is 2 or 3, second byte is ignored in case of 2 bytes
    if read: first = first + 0x80 #set the highest bit for read, i.e. add 0x80
    usb.send(bytes([3, cs, first, second, third, fourth, 100, nbyte]))  # get SPI result from command
    spires = usb.recv(4)
    if read:
        if show_bin: print("SPI read:\t" + name, "(", hex(first), hex(second), ")", binprint(spires[0]))
        else: print("SPI read:\t"+name, "(",hex(first),hex(second),")",hex(spires[0]))
    else: print("SPI write:\t"+name, "(",hex(first),hex(second),")",hex(third),hex(fourth))

def spicommand2(name,first,second,third,fourth,read, cs=0, nbyte=3):
    # first byte to send, start of address
    # second byte to send, rest of address
    # third byte to send, value to write, ignored during read, to address +1 (the higher 8 bits)
    # fourth byte to send, value to write, ignored during read
    # cs is which chip to select, adc 0 by default
    # nbyte is 2 or 3, second byte is ignored in case of 2 bytes
    if read: first = first + 0x80  # set the highest bit for read, i.e. add 0x80
    usb.send(bytes([3, cs, first, second, fourth, 100, 100, nbyte]))  # get SPI result from command
    spires = usb.recv(4)
    usb.send(bytes([3, cs, first, second+0x01, third, 100, 100, nbyte]))  # get SPI result from command for next byte
    spires2 = usb.recv(4)
    if read: print("SPI read:\t"+name, "(",hex(first),hex(second),")",hex(spires2[0]),hex(spires[0]))
    else: print("SPI write:\t"+name, "(",hex(first),hex(second),")",hex(fourth),hex(third))

def adf4350(freq):
    # For now use cs=2 for clk, later can use cs=3 on new board revision
    print('ADF4530 being set to %0.2f MHz' % freq)
    INT, MOD, FRAC, output_divider, band_select_clock_divider = (
        calculate_regs(device_type=DeviceType.ADF4350, freq=freq, ref_freq=25.0,
                       band_select_clock_mode=BandSelectClockMode.Low,
                       ref_doubler=False, ref_div2=False, enable_gcd=True
                       ))
    print("INT", INT, "MOD", MOD, "FRAC", FRAC, "outdiv", output_divider, "bandselclkdiv", band_select_clock_divider)
    regs = make_regs(INT=INT, MOD=4000, FRAC=FRAC, output_divider=output_divider,
                     band_select_clock_divider=band_select_clock_divider,
                     device_type=DeviceType.ADF4350, phase_value=None, mux_out=MuxOut.DVdd, charge_pump_current=2.50,
                     feedback_select=FeedbackSelect.Fundamental, pd_polarity=PDPolarity.Positive,
                     clk_div_mode=ClkDivMode.ResyncEnable, clock_divider_value=4000, csr=False,
                     aux_output_enable=False, aux_output_power=-4.0, output_enable=True, output_power=-4.0)  # (-4,-1,2,5)

    for r in range(len(regs)):
        print("adf4530 reg", r, binprint(regs[r]), hex(regs[r]))
        fourbytes = inttobytes(regs[r])
        # for i in range(4): print(binprint(fourbytes[i]))
        spicommand("ADF4530 Reg " + str(r), fourbytes[3], fourbytes[2], fourbytes[1], False, fourth=fourbytes[0], cs=2, nbyte=4)
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

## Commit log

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2024-07-29 fix pins for bottom rows of fpga
    [haasoscope_pro_adc_board - no blind.brd, haasoscope_pro_adc_board - no blind.sch]
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2024-08-01 fifo working with better stability (settings in fifo, 3 syncs) add triggeron and triggercounter to give the sending a break sometimes and test the fifo when near empty
    [command_processor.v]
2024-08-02 Working analog - turn on 1.1V _before_ 1.9V ?? 250 MHz clock, 125 MHz lvdsclk, 25 MHz lvdsclkout Gives correct 10 bits with 25 MHz input
    [command_processor.v, usb_rx_mass.py]
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2024-08-16 add 2.5D for fpga, and add 1V9D for VLVDS
    [haasoscope_pro_power_board.brd, haasoscope_pro_power_board.sch]
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2024-09-05 Consolodated clocks, fix timing almost
    [command_processor.v]
2024-09-10 Revert "v1.1"
    This reverts commit 9c2a8abd0e838ea48c804dee952ae91d8fcae4a4.
    [data board.brd, data board.sch, data board_top_bom.csv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]
2024-09-10 Revert "v1.1"
    This reverts commit 3ea246ff6ce0038198bb0009f8cc6fa5045fb056.
    [data board.brd, data board.sch]
2024-09-10 Revert "add husb238 for power delivery"
    This reverts commit fdcc09ca80390afb5c840c7f1bf23dbb25893304.
    [data board.brd, data board.sch, data board_top_bom.csv]
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2024-09-10 Power board v1.11 with +0.1V options, 2v5, etc.
    [haasoscope_pro_power_board.brd, haasoscope_pro_power_board.sch, haasoscope_pro_power_board_top_bom.csv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]
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2024-09-11 minor-fix ampout for jlcpcb
    [haasoscope_pro_input_board.brd, haasoscope_pro_input_board.sch, haasoscope_pro_input_board_top_bom.csv]
2024-09-11 add refB out, fix i/o spacing
    [haasoscope_pro_clock_board.brd, haasoscope_pro_clock_board.sch]
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2024-09-13 runs with adf4350 clock board, but phase not synced
    [haasoscope_pro_clock_board.sch]
2024-09-14 phase synced (need to reset adf, can be off by 180deg?)
    [HaasoscopeProQt.py]
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2024-09-19 1M 50 switch, with delta 6dB resistive combiner
    [haasoscope_pro_preinput_board.brd, haasoscope_pro_preinput_board.sch]
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2024-09-20 add attenuator and fix relay footprint
    [haasoscope_pro_preinput_board.brd, haasoscope_pro_preinput_board.sch, haasoscope_pro_preinput_board_top_bom.csv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]
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2024-09-20 change debugout 12-27 to boardout and boardin BUT SPI is flakey - need to debug
    [haasoscope_pro_adc_fpga_board.brd, haasoscope_pro_adc_fpga_board.sch]
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2024-09-24 can take 5V input, or make 5V from 12V
    [haasoscope_pro_power_board - 5V.brd, haasoscope_pro_power_board - 5V.sch]
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2024-09-24 use 4x22uF 0805 caps instead of 100uF tants
    [haasoscope_pro_power_board - 5V.brd, haasoscope_pro_power_board - 5V.sch, haasoscope_pro_power_board - 5V_top_bom.csv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]
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2024-09-26 don't place 10pF, fix some labels
    [haasoscope_pro_preinput_board.brd, haasoscope_pro_preinput_board.sch]
2024-09-27 add relay for splitter add ethernet jack for testing lvds add connector and trace test lines
    [haasoscope_pro_preinput_board.brd, haasoscope_pro_preinput_board.sch]
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2024-09-29 Revert "For quartus 23.1std.1 Build 993 05/14/2024 SC Lite Edition"
    This reverts commit 39e0d0792f11797ca9c313240aa76579386079d1.
    [HaasoscopeProQt.py]
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2024-10-01 2.4->2.2V for 1.9V reg, to reduce heat add vias in regulator gnd pads, to dissipate heat
    [haasoscope_pro_power_board - 5V.brd, haasoscope_pro_power_board - 5V.sch]
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2024-10-01 minor, change net classes so we can merge with main board
    [haasoscope_pro_clock_board.brd, haasoscope_pro_clock_board.sch]
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2024-10-03 remap lvds in/out clk, spare01, trig start to route them
    [haasoscope_pro_adc_fpga_board.brd, haasoscope_pro_adc_fpga_board.sch]
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2024-10-04 ready to do gnd vias, then routing rest
    [haasoscope_pro_adc_fpga_board.brd, haasoscope_pro_adc_fpga_board.sch]
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2024-10-05 fixed some bad route paths
    [haasoscope_pro_adc_fpga_board.brd]
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2024-10-07 move everything down by 3.5mm (one board slot) to make room for eth connectors
    [back panel.brd, back panel.sch, front panel.brd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]
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2024-10-09 fix compliler warnings, better min/max
    [HaasoscopeProQt.py, command_processor.v]
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2024-10-11 add adiff netclass, 4 mil wide with 5 mil spacing
    [haasoscope_pro_adc_fpga_board.brd, haasoscope_pro_adc_fpga_board.sch]
2024-10-11 12 bit ADC for temp mon (cheaper than 10 bit somehow), change gain from 2 to 1.1 for NTC input
    [haasoscope_pro_adc_fpga_board.brd, haasoscope_pro_adc_fpga_board.sch, haasoscope_pro_adc_fpga_board_bom.csv]
2024-10-11 Move fan connector a bit away from USB lines
    [haasoscope_pro_adc_fpga_board.brd]
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2024-10-12 fix bug with xaxis scaling at big downsample
    [HaasoscopeProQt.py]
2024-10-13 fix diffpair net classes and usb_c diffpair impedance
    [haasoscope_pro_adc_fpga_board.brd, haasoscope_pro_adc_fpga_board.sch]
2024-10-13 fix isolation of gnd pours from 0 (.09mm) to .1524mm, now traces are 50 ohm at .254mm width, but before they were more like 44 ohm
    [haasoscope_pro_preinput_board.brd]
2024-10-17 move fan so it doesn't hit relay
    [haasoscope_pro_adc_fpga_board.brd]
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2024-10-21 remove "50ohm?" pads (causing BW drop at 2 GHz)
    [haasoscope_pro_adc_fpga_board.brd, haasoscope_pro_adc_fpga_board.sch]
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2024-10-23 make 2v5+ from 3v3 instead of 2v8+, make 1v2 from 1v5d using standard TPS7A7200RGTR instead of 3v3 with ams117-1.2
    [haasoscope_pro_adc_fpga_board.brd, haasoscope_pro_adc_fpga_board.sch]
2024-10-23 Use 2 -2.5V regulators, one for input A, another for input B, since we need more than 200mA
    [haasoscope_pro_adc_fpga_board.brd, haasoscope_pro_adc_fpga_board.sch]
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2024-10-23 fix hole positions
    [back panel.brd, front panel.brd]
2024-10-23 change -2v8 to -3v0 for more dropout headroom on -2v5 regulator
    [haasoscope_pro_adc_fpga_board.brd, haasoscope_pro_adc_fpga_board.sch]
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2024-10-24 fix up 2v5- polygons a little
    [haasoscope_pro_adc_fpga_board.brd]
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2024-10-28 invert correct channels, fix triggers adjust according to sample triggered
    [HaasoscopeProQt.py, command_processor.v]
2024-10-29 correct for triggered sample when downsampling?
    [HaasoscopeProQt.py]
2024-10-29 be careful when inverting samples
    [command_processor.v]
2024-10-29 minor fix to downsampling
    [command_processor.v]
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2024-10-31 Move 12V and JTAG connectors back slightly, by 1 and 3mm respectively
    [haasoscope_pro_adc_fpga_board.brd]
2024-10-31 Adjustments to USBC slot, sma out hole, and probe comp hole
    [back panel.brd, front panel.brd]
2024-10-31 working on trigger jitter
    [HaasoscopeProQt.py, command_processor.v]
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2024-11-03 use 0.35mm vias instead of a few 0.5mm ones
    [haasoscope_pro_adc_fpga_board.brd]
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2024-11-05 sample_triggered working, for two boards, not workng for downsampling yet on two boards
    [HaasoscopeProQt.py]
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2024-11-08 acdc and normal/auto fixes
    [HaasoscopeProQt.py]
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2024-11-11 Add 1kHzOut50 SMA and ExtTrigIn SMA on back panel
    [back panel.brd, haasoscope_pro_adc_fpga_board.brd, haasoscope_pro_adc_fpga_board.sch]
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2024-11-12 Add a resistor on the 50 ohm aux out line
    [haasoscope_pro_adc_fpga_board.brd, haasoscope_pro_adc_fpga_board.sch]
2024-11-12 specify 2.5V 50 Ohm for ext trig in and aux out
    [back panel.brd]
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2024-11-17 fix a mac glitch
    [HaasoscopeProQt.py]
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2024-11-18 Add comparitors of CC1/2 to 0.7V for USB C power detection
    [haasoscope_pro_adc_fpga_board.brd, haasoscope_pro_adc_fpga_board.sch]
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2024-11-19 LVDS trig backwards H2/H1 outspare1 now intrigb F21/F22 inspare1 now outtrigb
    [haasoscope_pro_adc_fpga_board.brd, haasoscope_pro_adc_fpga_board.sch]
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2024-11-21 typo in sch, remove cc1/2 comparitors, since MACs don't report correctly, and a USB A cable doesn't either
    [haasoscope_pro_adc_fpga_board.brd, haasoscope_pro_adc_fpga_board.sch]
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2024-11-22 fix bug in usb reordering, add back mounting holes
    [haasoscope_pro_adc_fpga_board.brd]
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2024-11-26 cutout gnd on top layer below sma other minor aesthetic changes
    [haasoscope_pro_adc_fpga_board.brd, haasoscope_pro_adc_fpga_board.sch]
2024-11-26 switch to TLP3475 from TLP3475, because of availability
    [haasoscope_pro_adc_fpga_board.brd, haasoscope_pro_adc_fpga_board.sch]
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2024-12-10 fit extrig data to other channel RMS and mean fix sample_triggered for slower risetime events quiet TAD message tot can go down to 0 more lvdsout_trig=0
    [HaasoscopeProQt.py, command_processor.v]
2024-12-12 fixes for sample_triggered only working perfect for tot=0
    [HaasoscopeProQt.py, command_processor.v]
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2024-12-18 357 -> 220 Ohm for lmh5401 termination 27 -> 16 pF and 27 -> 47 Ohm for splitter
    [haasoscope_pro_adc_fpga_board.brd, haasoscope_pro_adc_fpga_board.sch]
2024-12-18 reorder startup so calib issue is gone
    [HaasoscopeProQt.py, board.py, usbs.py]
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2024-12-19 fix glitch in sample_triggered fix downsampling drawing
    [HaasoscopeProQt.py]
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2024-12-25 fix parts
    [haasoscope_pro_adc_fpga_board.brd, haasoscope_pro_adc_fpga_board.sch, haasoscope_pro_adc_fpga_board_bom.csv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]
2024-12-25 Use smaller 0201 resistor footprint Board v1.23 does not include this change or any future changes
    [haasoscope_pro_adc_fpga_board.brd, haasoscope_pro_adc_fpga_board.sch]
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2024-12-29 fix sync slot bug
    [back panel.brd]
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2025-01-08 add 10uF Cin caps, and move them and the 0.1uF close to PGND for switching regs, hoping to reduce EMI
    [haasoscope_pro_adc_fpga_board.brd, haasoscope_pro_adc_fpga_board.sch]
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2025-01-12 switch between one and two channels dynamically - likely still many little bugs, needs testing
    [HaasoscopeProQt.py, board.py]
2025-01-13 reverse D and S on P-mos, and divide down 12connected to 2.5V for FPGA input so it's not pulled down to 3V
    [haasoscope_pro_adc_fpga_board.brd, haasoscope_pro_adc_fpga_board.sch]
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2025-01-23 use signed addition for all highres fix bug in triggercounter use triggersamplecounter to see how long to wait to for tot
    [command_processor.v]
2025-01-23 fix downsamplemerging_triggered for tot>0
    [HaasoscopeProQt.py, command_processor.v]
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2025-01-30 make input 0 on the left, but switch to input 1 for oversampling
    [front panel.brd]
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2025-01-30 correct inversion for two boards and oversampling, now that we're swapping inputs use = not <= for rgb leds
    [HaasoscopeProQt.py, command_processor.v]
2025-01-31 fix downsamplemergingcounter_triggered for tot>0 and ext_trig
    [HaasoscopeProQt.py, command_processor.v]
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2025-02-03 fix rolling and ext trig
    [command_processor.v]
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2025-02-03 calc mean and std correction for oversampling in autocalib function
    [HaasoscopeProQt.py]
2025-02-05 minor, gnd vias under usbs 5v ports, to connect bottom gnd pour
    [haasoscope_pro_adc_fpga_board.brd]
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2025-02-05 move pads a little (~2 mil) closer for MF_PASSIVES R and C 0402 package, to fix JLCPCB complaint
    [haasoscope_pro_adc_fpga_board.brd, haasoscope_pro_adc_fpga_board.sch]
2025-02-05 allow for negative TAD, which flips clk polarity
    [HaasoscopeProQt.py]
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2025-03-15 If statement reversal to reduce LUT usage.
    Reduces total logic elements used from 13568 to 13454.
    [command_processor.v]
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

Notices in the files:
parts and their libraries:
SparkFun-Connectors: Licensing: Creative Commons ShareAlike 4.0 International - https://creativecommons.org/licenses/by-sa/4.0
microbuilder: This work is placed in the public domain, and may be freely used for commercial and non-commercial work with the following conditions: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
